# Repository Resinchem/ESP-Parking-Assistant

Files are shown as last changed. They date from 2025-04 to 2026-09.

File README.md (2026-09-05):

# An ESP32 LED Parking Assistant



### Version 0.60 is now out with a complete rebuild!!

Using a low cost ESP32 Mini, a short strip of around 20-40 WS2812b LED pixels and TFMini-s LIDAR distance sensor, you can create an easy-to-build  visual parking assistant system for putting your car in the same location in the garage each time.

Some key features of the system include:
- 4 variable distance parking zones, including a wake zone, an active zone, a parked zone and a backup zone.
- Each zone can have its own unique LED color, specified by the user
- The active zone has 5 different approach effects that can be used to visually show the car approaching the final parked position.
- Automatically goes to standby or sleep mode and only awakens when a car enters the wake zone.
- Supports any number of LED pixels, up to 100, and is designed so the LED strip can be mounted horizontally or vertically.
- All options and settings made through an embedded web interface. No external apps needed.
- Over-the-air firmware updates, with a manual OTA option available for uploading your own modified source code.
- **Optional** Lateral guidance via a secondary sensor.
- **Optional** AP Mode (no-WiFi) allows the system to be used in locations where reliable WiFi may not be available.
- **Optional** MQTT integration so you can use the parking assistant with other automation systems.
- **Optional** 1-Click Home Assistant Discovery.  Add the device to Home Assistant with no YAML or manual configuration!

If you are just looking to install the firmware, just go to the [Installation Page]( https://resinchem.github.io/ESP-Parking-Assistant/installation.html#-install-full-firmware-here) in the firmware guide.  _You do not need to download any files_ from this repo nor do you need to clone the repository.  The installer will handle everything for you!

## Additional Information and Resources

Resource | Details
------|-----
[Build Guide](https://resinchemtech.blogspot.com/2026/08/parking-assistant-2026.html) |A how-to written guide including parts, schematics and overall assembly instructions.
[Firmware Guide](https://resinchem.github.io/ESP-Parking-Assistant/)|Firwmare installer, onboarding and initial system configuration, and overall general application use.

### Video Overviews
YouTube Video | Details
-------|-------
[ESP32 Parking Assistant Overhaul](https://youtu.be/pNj6GjKsijo)|Primarily focuses on v0.60 new features, with brief overviews of operation, parts and assembly processes.
[Parking Assistant Upgrades: Lateral Guidance](https://youtu.be/Eps6QCgKzaM)|Covers new features introduced starting with v0.50.  Primarily focuses on the side sensor addition, wiring and use.
[Original Parking Assistant Video](https://youtu.be/HqqlY4_3kQ8)|Now a bit outdated, as the original version used an ESP8266 and substandard shifter.  But still contains useful background information, including a comparison of distance sensors and why the TFMini-S was selected.

## Special Upgrade Notice
If you are running v0.5x of the firmware, a special one-time migration is **highly recommended**.  This process is described in a special [Migration Page](https://resinchem.github.io/ESP-Parking-Assistant/migration) within the firmware documentation.  

_**DO NOT** attempt to upgrade your firmware using the existing v0.5x web app until you've reviewed the migration page information!_

---

## Information for Older Releases (v0.52 and earlier)
Version 0.60 involved a complete rewrite of the firmware and much of the documentation.  However, if you landed here looking for information for older versions, it has been maintained (for now).

### ESP8266 Support Has Ended (v0.52)

Due to the continued addition (and complexity) of new features, it has unfortunately become necessary to drop support for the ESP8266 beginning with release v0.52.  If you have or wish to use an ESP8266, then you must use firmware v0.51 or earlier.  I've tried to update the wiki and related pages, but if you still see references to the ESP8266 please be aware that this applies to firmware v0.51 or earlier.  Newer features shown in the wiki and discussed elsewhere also may not be available in the older ESP8266 versions.  It is highly recommended to now use an ESP32 for all new builds.

**ADDTIONAL RESOURCES** (ONLY for pre-v0.60 versions!)

Resource | Notes
-----|----
[Firmware Installation and Use](https://github.com/Resinchem/ESP-Parking-Assistant/wiki)|Maintained in this repo's old Wiki (v0.52 and earlier)
[Original Build Guide](https://resinchemtech.blogspot.com/2022/11/esp-parking-assistant.html)|Original written build guide that covers up to v0.52

### Supporting this Project and Future Developement 

### _Always free!_

It takes substantial time, effort and cost to develop and maintain this project and all the related documentation. But my goal is to always provide the code and documentation for free... **without paywalls, subscriptions or implementing some sort of half-assed "freemimum" model.** 

<i>The system will also never collect your data or force any annoying ads down your throat!</i>

If you find this project helpful and would like to say 'thanks', please consider supporting it and future development at:

<a href="https://www.buymeacoffee.com/resinchemtech" target="_blank">Buy Me A Coffee</a>

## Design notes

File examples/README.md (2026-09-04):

## MQTT / Home Assistant Examples

**Starting with release v0.45, Home Assistant Discovery is now available**

MQTT Discover can be launched from within the Parking Assistant web application and it will automatically create a new device and entities in Home Assistant for you, without the need to create any manual YAML or do any other configuration in Home Assistant. Discovery is the **recommended method** of integrating your Parking Assistant.  Please see [Home Assistant Discovery](https://resinchem.github.io/ESP-Parking-Assistant/discoverymain.html) topic for more information.

However, if the discovery process does not work for you or you simply wish to completely control how the entities are created in Home Assistant, you can manually create them via YAML. The basic code for creating these entities is provided in the yaml examples above.  They do not contain additional fields like last-will-and-testament nor any device information. You can tweak these to use your own preferred names, add default icons, or any other valid properties.

Once created, the entities should be available in Home Assistant for use on your dashboards or in your automations.

HA_Entities_Blurred_Small

Note that when first created, these entities may have a state of 'Unknown' until the controller updates its MQTT values based on the telemetry period set in the controller's MQTT options.  You can force an immediate refresh of all topics by any of the following methods:
- Issue an mqtt command to: `cmnd/your_subscribe_topic/refresh` with a payload of "1"
- Use a browser to send the command: `http://[your_ip_address]/api?refresh=1`
- Reboot the Parking Assistant controller.

<i>Creating individual entities as shown in the examples will <b>not</b> create a device like when using Discovery.  To manually add the entities to a common device, you'd need to add the device information to each entity's YAML definition.  See the [Home Assistant MQTT documentation](https://www.home-assistant.io/integrations/mqtt/) for more information on how to add device properties to an entity.</i>

Note that MQTT is optional for the project and it is not required and can be disabled at any time via the web settings.

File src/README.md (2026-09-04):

### If you just want to install the firmware on your ESP32, you do not need to download any files!

Starting with release v0.60, just go to the [Web Installer](https://resinchem.github.io/ESP-Parking-Assistant/installation.html#-install-full-firmware-here) to install the latest firmware release.  All you need is a compatible browser (Chrome, Edge, Brave, Opera, Arc or most other Chromimum-based browsers) and a USB data cable!

## Source Code
This directory contains the source code files for the parking assistant.  You can download and modify this to meet your own needs.  Both the .ino and .h files are reqired. The Parking Assistant supports OTA updates from the Arduino IDE (or other appropriate IDEs).  See the wiki section on [Modifying the Firmware](https://resinchem.github.io/ESP-Parking-Assistant/modifications.html) for more information on OTA updates using an IDE.

You will need to have the ESP32 boards installed in your environment, plus all the appropriate libraries listed at the top of the sketch file.  If you've not setup the Arduino IDE for the ESP before, this video might help: [Arduino IDE: Basics for Non-Coders](https://youtu.be/KS5HOJat88k)

### ESP8266 support has ended
Support for the ESP8266 ended with release v0.52.  If you need to install a version for the ESP8266, you must download and use the _esp8266.bin file for release v0.51 or earlier.  Later versions (v0.52+) are unstable on the ESP8266 due to the overall sketch size and the complexity of new features.

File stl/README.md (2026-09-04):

## 3D Printed Parts
These parts are not required for functionality but simply provided as an option for enclosing or mounting your parts.

All parts were printed using PLA.  Supports (_touching build plate_) are recommended for all parts.  Click any of the files above to see a preview of the model.

Part | Purpose/Notes
----|-----
`Controller Enclosure Easic.stl`|Basic enclosure for the controller.  Deep enough to permit mounting the ESP32 on pin headers.
`Controller Enclosure with Mount Tabs.stl`|Same controller enclosure, but with mount tabs for anchoring to wall or other surface.
`QwiicBus Enclosure.stl`|Enclosure and mount for the Qwiicbus I2C extender (if needed)
`VL53L0X Side Sensor Mount.stl`|Enclosure and mount for the side sensor (if installed)

Alternative, industrious users  improved on my models by designing a different QwiicBus enclosure and even a controller enclosure design that includes the QwiicBus as part of the base controller.  Here is one of these alternate designs:

Credit to _**@pjschaffer**_

[Alternate Controller Enclosure with embedded QwiicBus](https://makerworld.com/en/models/3241403-resinchem-tech-s-parking-assistant-enclosure)

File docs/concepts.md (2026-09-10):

---
layout: default
title: Concepts and Terminology
parent: Welcome
nav_order: 2
has_toc: false
---

# Concepts and Terminology
{: .no_toc }

To successfully install and configure this firmware, it is important to understand the underlying system design and the specific terminology used throughout this documentation.

**🌐 Connectivity & Privacy:**<br>This system is designed to be **fully functional on a local Wi-Fi network**. While it supports integrations like Home Assistant or other systems via MQTT/API, these are strictly **optional**. An active internet connection is not required for core operations.  There is even a mode where the system can operate without WiFi (Access Point mode).
{: .note }

---

## Parking Zones
<p align="center">
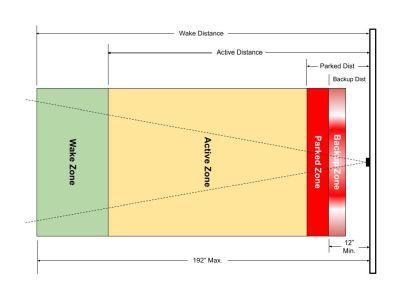
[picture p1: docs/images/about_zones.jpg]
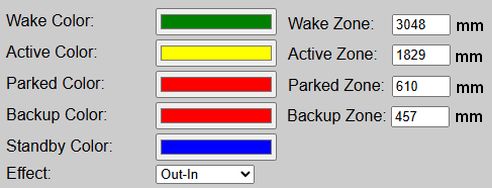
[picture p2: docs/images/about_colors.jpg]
  &emsp;
</p>

To properly configure your system, it is important to understand the different ["zones"](zones) and how they are used.  As a car enters each zone, the LEDs will change color.  What's more, when the car is in the 'Active' zone, an LED effect is used to show the approach to the 'Parked' zone.  Distances, to the outer edge of each zone, can be entered in inches or millimeters.

## The Primary Controller
<p align="center">
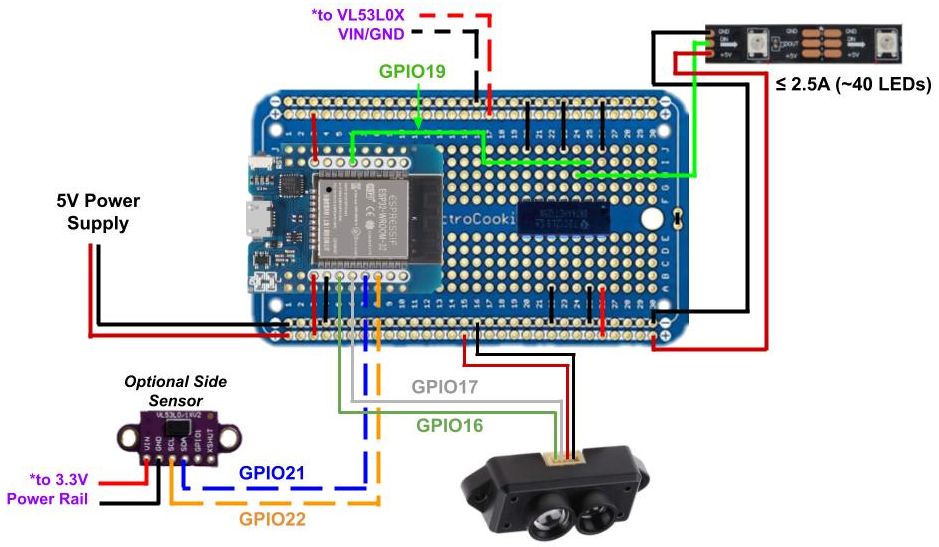
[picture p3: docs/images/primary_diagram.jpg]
  
</p>

The primary controller consists of a standard ESP32 (WROOM-32) and a _recommended_ logic level shifter.  If you've ever built your own WLED controller, the base is nearly identical.  See the [build guide](https://resinchemtech.blogspot.com/2026/08/parking-assistant-2026.html) for complete wiring diagrams and step-by-step assembly instructions.

## LEDs
<p align="center">
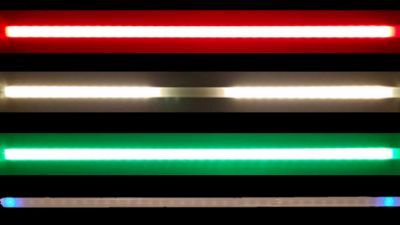
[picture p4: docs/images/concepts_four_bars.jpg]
  
</p>

The system is designed to only work with 5V WS2812b LED strips.  Use of other 5V LED types will require modification of the source code and your own complied version.  Use of 12V or 24V are not supported, as generally these can only control the LEDs in groups of three or six, respectively.  This system needs to control each LED individually, which is normally only found when using 5V addressable LED strips.

The system can theoretically support up to 600 LEDs.  But to minimize the power required (and therefore the wiring), a strip of around 2 feet long is recommended.  This will be around 35 standard LEDs when using a common 60 LEDs/m version.  Alternatively, and to provide greater sensitivity, you can substitute a WS2812b COB LED strip.  Using a version of 160 LEDs/m allows around 100 LEDs in the same 2 foot width, while also drawing about the same amount of current (give or take a bit).

Ideally, you want to keep the current draw of the LEDs to around 2.5A or lower when fully lit at expected brightness.  Exceeding this value will require different power routing (e.g. extra power lines directly to the LEDs). Again, refer to the [build guide](https://resinchemtech.blogspot.com/2026/08/parking-assistant-2026.html) for more information on the LED strips, power supplies and wiring.

## Sensor(s)
<p align="center">
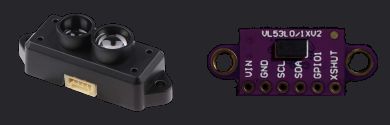
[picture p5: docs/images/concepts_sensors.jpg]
  
</p>

### Primary (Front) Sensor

The primary, or front sensor that tracks the car through the zones, is a TFMini-s LiDAR distance sensor.  The first thing you'll notice about this sensor is its cost... approximately $40!  This is substantially higher than many other distance sensors, like the ultrasonic HC-SR04, that can be purchased for under $5.  

However, in the [original parking video](https://youtu.be/HqqlY4_3kQ8), I compared various sensors at different distances and charted the results.  

<p align="center">
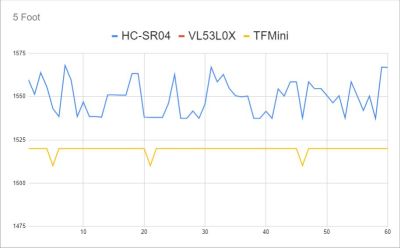
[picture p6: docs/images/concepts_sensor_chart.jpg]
  
</p>

The TFMini-s was the only sensor with the range, precision and signal stability to meet my needs.  Personally, saving $30 isn't much comfort when signal jitter from a noisy subpar sensor causes a bumper to take a $500 bite out of the drywall. 😭

One important note.  Be sure to purchase a TFMini-s (the -s is important).  Other models of the TFMini, such as the _TFMini-plus_ or _TFMini-luna_ use different communication protocols and will not work with the current firmware.

**⚠️ Alternate Sensor Requests:**<br>I've received multiple requests to release a version using a cheaper sensor, like the HC-SR04.  But saving $30 dollars isn't worth the risk of damaging the car or wall by using a less-capable version.  Some have forked the project to substitute a cheaper sensor, but I cannot attest to their functionality nor can I support them.  If you wish to try a different sensor, please understand that you will need to modify the firmware and are on your own for support!
{: .important }

### Optional Secondary (Side) Sensor

While not required, you can add a side sensor to the system to provide both lateral guidance and to improve the front sensor accuracy.  In this case, and because the side sensor needs neither the range nor the precision of the front sensor, it uses a much lower cost VL53L0X sensor.  However, just like the front sensor, the firmware is written for this particular component.  Substitutions will likely require firmware modification.

## Other Important Terminology
There are a few other important terms to understand... at least as far as this guide is concerned.

### Firmware 
This is the compiled code that gets installed on the ESP32 controller.  For this project, the firmware is delivered as a .bin file included in a release's assets.  Note that you cannot directly install the source code (.ino) directly on an ESP board.  It must be compiled into a binary .bin file using the Arduino IDE, PlatformIO or other compiler.  This project includes separate firmware for installing on a new controller or for upgrading an existing controller (v0.60 or greater).

### Web Application:
 The firmware contains an embedded web server and web application. These are primarily used to configure and setup the controller, but can also be used to test or change LED colors, approach effects and distances.

When this documentation refers to the "web app", it does not mean a separate application that has to be installed on a computer, phone or tablet.  You can always access the firmware's "web app" by just going to the IP address of the controller in a web browser of any device on the same WiFi network.  If you opt to run the system in "No WiFi" mode, then the controller will broadcast a local hotspot you can join to access the web application and make system changes.

<div style="display: flex; justify-content: space-between; align-items: center; margin-top: 40px; border-top: 1px solid #333; padding-top: 20px;">
  <a href="{{ '/about' | relative_url }}" class="btn btn-outline"><- Previous: About the Project</a>
  <a href="{{ '/startingmain' | relative_url }}" class="btn btn-purple">Next: Getting Started -></a>
</div>

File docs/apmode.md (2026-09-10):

---
layout: default
title: Access Point Mode (no WiFi)
parent: Setting Up the System
nav_order: 5
---

# Access Point Mode (No WiFi)
{: .no_toc }

---

<p align="center">
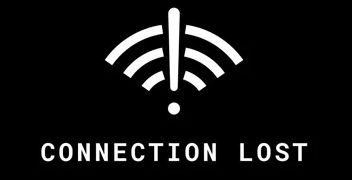
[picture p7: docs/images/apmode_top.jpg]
  
</p>

An oft requested feature, version 0.60 of the firmware introduced the ability to enable local Access Point mode instead of using WiFi.  This is most often needed when installing the Parking Assistant in a location, such as a detached garage or outbuilding, where WiFi may not be available.

Before you can enable this mode (and disable the WiFi features), a few prerequisites must be met:

### <u>System Must First Be Onboarded via WiFi</u>
The onboarding process requires WiFi.  If your planned location does not have WiFi, then simply onboard the ESP32 at a location with WiFi first.  Once onboarded, you can switch to AP Mode via the instructions on this page and then move the controller to the final location.

### <u>MQTT / Home Assistant Discovery Must be Disabled</u>
Since MQTT (and Discovery) require WiFi, you cannot switch the system to AP Mode if Discovery exists or MQTT is enabled.  You must first remove any Discovered devices (if any) and then disable MQTT before you can switch to Access Point mode.

### <u>Other Features Will Also Be Disabled or Limited</u>
Other features that rely on WiFi will also be disabled/unavailable when in AP Mode:
- Firmware Updates:  Firmware updates from within the app use WiFi to transfer the new file.
- Arduino OTA Updates:  This feature requires WiFi/mDNS, so it will also be disabled. 
- HTTP API: Commands can only be sent from devices connected to the AP hotspot.

## Enabling Access Point Mode
Once the above prerequisites have been met, you can toggle AP Mode from the Hardware Settings page.
<p align="center">
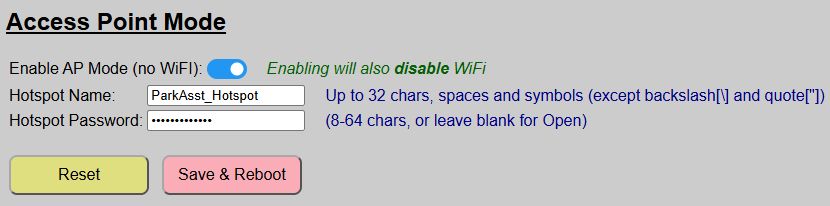
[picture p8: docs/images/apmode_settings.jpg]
  
</p>

Simply toggle the silder to disable WiFi and enable AP Mode.  If you have enabled a feature (like MQTT) that prevents AP mode, you will be shown a message and toggle will move back to "OFF" until you've disabled the other feature(s).

When toggled 'ON', two additional fields are shown:

Setting|Purpose
---|---
HotSpot Name|This is the hotspot that will be broadcast by the system when in AP Mode.  It can be up to 32 characters, numbers or symbols except for the backslash (\\) or quote (") symbols.  It cannot be blank and should not be the same as any other Parking Assistant hotspot name.
Hotspot Password|Enter a password of 8-24 characters in length.  Optionally (but not recommended), you can leave the hotspot 'open', which will not require a password.

>⚠️ **Password Recommended**<br>Leaving a blank password/open hotspot may be more convenient when you need to interact with the system, but anyone else in range of the hotspot can also access the web application and interact with the system.  Even though the range of an ESP32 is rather limited, applying a password is still recommended.
{: .important}

Finally, click the 'Save and Reboot' button.  The system will reboot, but this time, WiFi will not even be started.  Instead, the system will begin broadcasting a local hotspot using the name you specified.  Otherwise, the system will function and operate normally.

## Accessing the Web Application when in AP Mode
So, if the system is not on WiFi, how do you return to the web application to interact with the system or make other changes?  Well, you use a mobile device (tablet or laptop recommended, but a phone will work) and connect to the local hotspot.

In addition, because the radio on the ESP32 isn't very powerful, you'll need to be relatively near the parking assistant to join the hotspot.

_The following instructions and screen shots may be slightly different depending upon the type and operating system of the mobile device in use. Android, iOS and Windows all work just a bit differently, but the steps should be similar._

Using your mobile device, search available WiFi Networks:

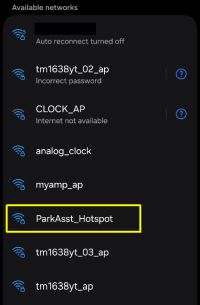
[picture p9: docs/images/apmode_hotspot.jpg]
mobile hotspot


Join this hotspot.  If you entered a password, you will be prompted to provide it.

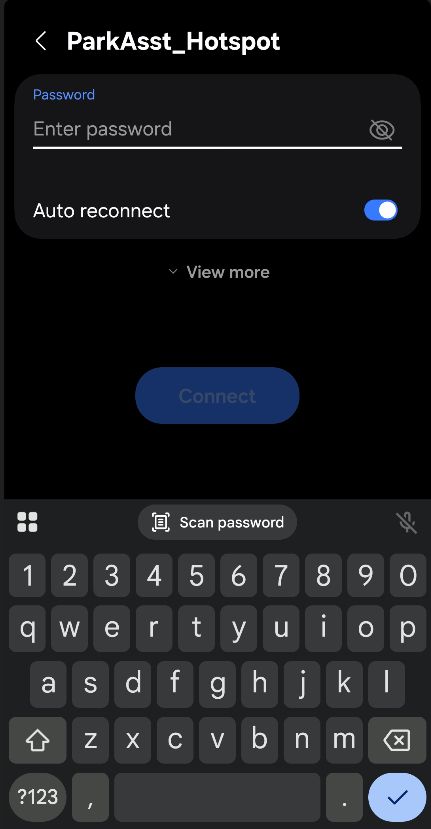
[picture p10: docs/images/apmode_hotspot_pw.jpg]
mobile hotspot


If prompted, elect to  'remain connected' if your device complains about no Internet.  Depending upon your device/OS, the web page may launch automatically. If it doesn't simply open a browser and enter the default IP address of: `192.168.4.1`.  

This should launch the main page of the web application. 

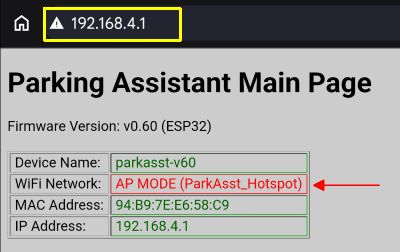
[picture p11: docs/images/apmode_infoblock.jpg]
info block


Note that the info block at the top of the page now indicates AP MODE for the Wifi Network and includes the hotspot name in parentheses.  Once on the main page, you can interact with the system, even changing and saving hardware settings, just like the system was on normal WiFi.  The only exception will be those previously mentioned features, like firmware updates or enabling MQTT, which are only available in normal WiFi mode.

When done interacting, simply rejoin your device to normal WiFi again.  Nothing needs to be done on the parking assistant side and it will continue broadcasting the hotspot for the next time you need to interact with the system.

## Returning to Normal WiFi Mode
If your system is in Access Point mode and you wish to return to normal WiFi mode, the process is even easier!

Access the web app with a mobile device and the hotspot as described above.  Go to the Hardware settings page and simply toggle the AP Mode switch back to the off position.

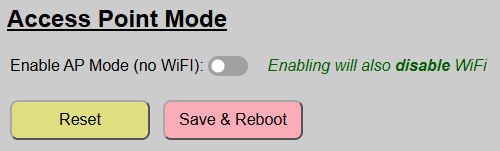
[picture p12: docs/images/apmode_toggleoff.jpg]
toggle switch


Now just 'Save and Reboot'.  The previously used WiFi credentials (SSID and password) used during initial onboarding will be recalled and the system will rejoin normal WiFi when it reboots.  Easy, peasy!  This means you can switch back and forth between normal and AP modes as needed.

## Applying Firmware Updates
One of the features that is disabled when the system is in AP Mode is the ability to update the firmware from the web application.  So how do you handle this situation if you have a system without WiFi and a firmware update is released?  You have a couple of options available.

### Option 1: Return the System to WiFi Mode (recommended method)
First place the system back in normal WiFi mode.  If Wifi is not available in the installed location, then you'll need to temporarily move the controller to a WiFi-enabled spot.  If you built your system according to the [Build Guide](https://resinchemtech.blogspot.com/2026/08/parking-assistant-2026.html) and your ESP32 is mounted on pin headers, you can simply power down the system and remove the ESP32.  Take the ESP32 to a WiFi-available location.

Power the removed ESP32 via its USB port.  Since there are no LEDs or sensors attached, pretty much any USB power source... a cell phone charger or an available USB port on a computer will work.  And since we are just using USB for power in this case (and not data), you do not even need a data cable in this case.

Once the ESP32 is back on WiFi and powered, return to the web application. Note that this may be a different IP address than previously assigned if you did not assign a static/reserved IP address when you onboarded the system.  If you cannot reach the web application, check your router to see if a different IP was assigned.

### Option 2: Update via AP Mode
Alternatively, you can download and transfer the firmware update file (`ParkingAsst_vX.XX_Update.bin`) to your mobile device (laptop strongly recommended), join the hotspot and open up the web application.  This method is not the recommended process for a couple of reasons:
- Depending upon your device, it may not be possible to select the transferred update.bin file from the file browser provided on the update page.
- Hotspot mode simply isn't as robust and reliable as normal WiFi mode.  You may have issues with a successful flash if the file transfer process is interrupted.

But you can always try this method and fall back to the WiFi method if it fails.

Regardless of the method used to access the web page, just use the Firmware Update controller command to flash the update file.  See the [Installing Firmware Updates](firmwareupdates) topic for step-by-step instructions upgrading the firmware.

If you used Method 1, simply set the system back to AP Mode after the update and then reinstall the ESP32 back into the controller assembly.  When it reboots, it will return to AP mode.

<div style="display: flex; justify-content: space-between; align-items: center; margin-top: 40px; border-top: 1px solid #333; padding-top: 20px;">
  <a href="{{ '/sensorcalibrate' | relative_url }}" class="btn btn-outline"><- Previous: Sensor Calibration</a>
  <a href="{{ '/usingmain' | relative_url }}" class="btn btn-purple">Next: Using the System -></a>
</div>

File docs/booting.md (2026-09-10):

---
layout: default
title: The Boot Process
parent: Getting Started
nav_order: 3
has_toc: false
---

# The Boot Process
{: .no_toc }

---

<p align="center">
  The Boot Process Header
</p>

A lot is going on in the background when a controller first boots up... connecting to WiFi, configuring the hardware, starting up the web server and API routines and connecting to an MQTT broker (if enabled).  The system can provide some basic visual indicators of this boot process and can help you determine where a problem may exist if the controller isn't functioning as intended.

>⚠️**Enable Indicators During Setup**<br>It is highly recommended that you leave the boot indicators enabled at least during initial system configuration and setup and until you are sure all hardware and any optional integrations are working properly.  If your system has an issue during the setup/boot process and these indicators are disabled, it may be difficult to determine where and why the failure is occurring.
{: .important}

## Visual Boot Indicators

When you power on the controller, the following steps occur:
* The system looks for a configuration file in its own storage (SPIFFS) partition. If not found, it enters 'Onboarding mode' and starts the WiFi Hotspot.  Setup halts at this point.
* The system attempts to connect to WiFi.  Again, if it fails, it enters Onboarding mode and further setup halts.
* The configuration file is opened and your particular system settings are loaded.
* Hardware and sensor(s) are configured and initialized.
* OTA Mode is enabled.
* When boot is complete, the system enters normal running mode.
<br><br>

_Note_:  You can disable some of these boot indicators via the web app if you don't want to see them.  The process described below assumes these indicators are enabled.
Boot Options

### WiFi Connected

Most ESP32 board have a power LED that will illuminate as soon as power is received.

power led

But most boards also have a second onboard LED (usually blue) that can be controlled via a GPIO pin (GPIO2).  If your board has one (and the option is enabled), this second LED lights up to let you know the controller is officially talking to your network and not just glowing in the dark!

wifi led

This option can be disabled if your board does not have a second LED.  Or if your board uses a different GPIO pin for the onboard LED, you can also change that via the system's hardware settings.

>📵 **Access Point (No WiFi) Mode**<br>If your system is configured for Access Point mode, then the blue LED will never illuminate after initial onboarding, regardless of indicator setting.
{: .note}

### MQTT Broker Connection
If you have enabled MQTT under integrations, the LED strip will show each broker connection attempt.  The system will make up to 10 tries before failing.  Each attempt is shown on the LED strip as it occurs:

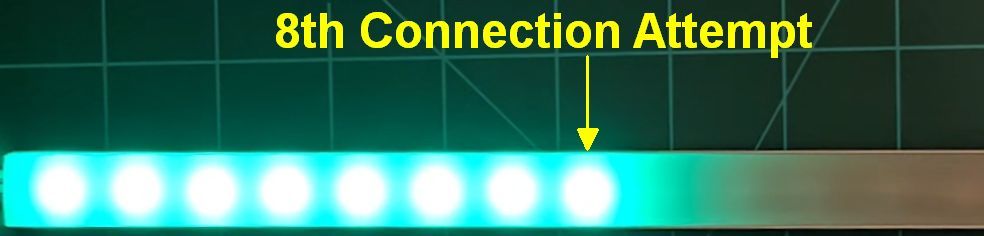
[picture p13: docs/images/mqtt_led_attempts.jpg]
LED Strip


**Each attempt may take 3-5 seconds**.  If unsuccessful after 10 tries, the full LED strip will briefly flash yellow and MQTT will be disabled.  The normal boot process then continues.  This entire process may take up to 60 seconds to complete before failing. The web page will be inaccessible during this period, as it is not available until the entire boot operation completes.

<i>When a normal successful connection is made, it may happen so quickly you may only see one or two LEDs briefly flash in green... or may not see the green LEDs at all.  This normal behavior.</i>

### Side Sensor Initialization
If you have enabled and configured a side sensor (lateral guidance), the boot process will initialize the communication with the sensor.  If this initialization **FAILS**, then the LED strip briefly flashes orange. 

boot_orange

If the side sensor successfully initializes (or if it is disabled), then you will not see this brief orange color.

### LEDs and Other Hardware
If all other hardware and boot processes complete, and if enabled, the LEDs will then briefly flash red, green and blue.

led_test

Once you see this sequence, all hardware and other communication protocols have been initialized and started.  There is just one more step before the system begins normal operation.

### OTA (Over-the-Air) Updates Enabled

Finally, if all other checks complete, the boot process enables over-the-air mode for receiving firmware or other updates wirelessly.

ota leds

When OTA mode is implemented, the LEDs change to alternating red and green.  During the boot process, this is only shown for a few seconds and _does not indicate that the system is receiving data_.  During the boot, it only indicates that OTA is now active and available.  Note that this indicator will always be shown, even if the LED Boot Indicator option is disabled in the hardware settings.

**NOTE**: OTA requires WiFi, so if you are operating in Access Point (no WiFi) mode, the OTA will not be enabled and the LEDs will not show this mode.

After this final step, the system enters normal operating mode.

>👉**System Always Starts in "Active" Mode after Rebooting**<br>By design, any time the system boots, it will start out in 'active' mode.  If a car is present, the LEDs will light up appropriately based on position.  Just for the boot process, the LEDs will remain on for the "Exit Time" and then enter 'Standby' mode.  If no object is in any zone, then the system will enter standby immediately after the boot finishes.
{: .note}

>⚠️**Additional Startup Processes**<br>If you have MQTT enabled, there may be up to a 30 second delay as initial MQTT topics are published before the system will respond to sensor triggers. If the system doesn't respond immediately after booting, give it 30-60 seconds to complete all start up processes.
{: .important}

<div style="display: flex; justify-content: space-between; align-items: center; margin-top: 40px; border-top: 1px solid #333; padding-top: 20px;">
  <a href="{{ '/onboarding' | relative_url }}" class="btn btn-outline"><- Previous: Onboarding</a>
  <a href="{{ '/setupmain' | relative_url }}" class="btn btn-purple">Next: Initial System Setup -></a>
</div>

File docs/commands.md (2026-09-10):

---
layout: default
title: Controller Commands
parent: General System Use
nav_order: 4
has_toc: false
---

# Controller Commands
{: .no_toc }

---

<p align="center">
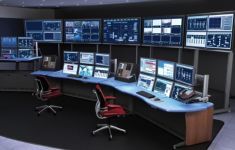
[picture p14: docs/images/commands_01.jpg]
Zone Image
  
</p>
The main page of the web application offers a set of standard controller commands that can perform operations such as rebooting the controller, applying firmware updates, viewing the contents of your saved configuration file or even factory resetting the controller for a new onboarding process.<br><br>

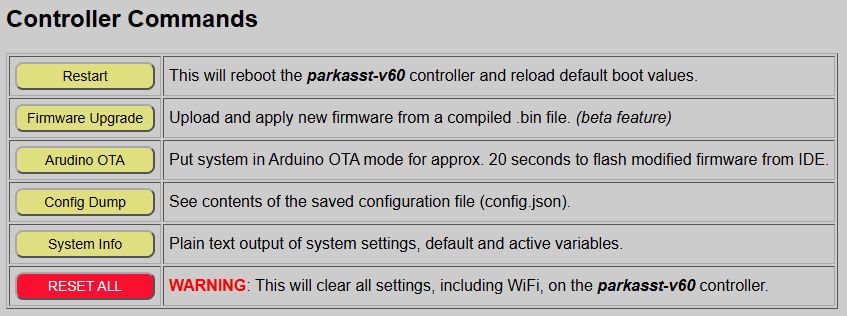
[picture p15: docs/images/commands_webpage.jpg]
Zone Image


### Restart

 Reboots the controller. If you have applied any "Active" settings that have not been saved as new defaults, these settings will be overwritten with the last saved defaults during the reboot.

### Firmware Upgrade

_**This feature is not available when operating in AP Mode!**_
{: .label .label-yellow }

This opens up a page for applying firmware updates from a compiled `_Update.bin` file, normally from the repository's [Releases](https://github.com/Resinchem/ESP-Parking-Assistant/releases/latest) page.  You cannot upgrade using the source (.ino) files, but only with a compiled .bin file.

> **⚠️ Warning**<br>Installing the wrong firmware file on the controller will break your system. See [Installing Updates]({{ '/firmwareupdates' | relative_url }}) before proceeding.
{: .warning }

Installing firmware updates are covered in a separate upcoming topic or you can use the link in the box above to jump directly there now.

### Arduino OTA
_**This feature is not available when operating in AP Mode!**_
{: .label .label-yellow }

This can be used to place the system in a special programming mode, where a modified source code version of the firmware is compiled and installed wirelessly to the controller.  Each controller broadcasts a special message that is used as a "port" in the Arduino IDE.

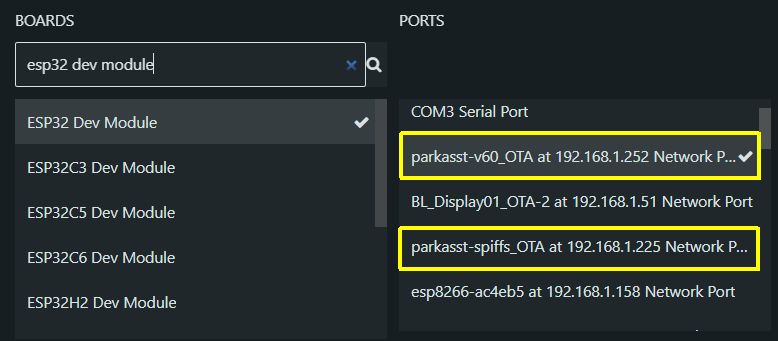
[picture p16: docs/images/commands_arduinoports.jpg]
Arduino Ports


The port will show the device name followed by _OTA and the IP address of the controller.  Make sure when using this method that you are flashing the correct code to the correct controller.  As you can see in the above example, I have two Parking Assistants active on the network.  I can differentiate them not only by the IP address, but also by the device name I assigned during onboarding.

> **🌐 Port Not Found**<br>The Arduino OTA process requires that your network support and allow mDNS broadcasts.  This is an **Arduino requirement** and not a firmware issue.  If you cannot (or prefer not to) allow mDNS broadcasts, then any Arduino updates cannot be done wirelessly and you will need to use a USB cable connection for uploads.
{: .note }

Once your new code is verified and ready for upload, click the 'Arduino OTA' button.  When activated, the LEDs will display an alternating Red-Green pattern

ota_mode

- As soon as the system is put into OTA mode, begin the upload from the Arduino IDE.
- If no code is received within about 20 seconds, the controller exits OTA mode and returns to normal operation.
- When in OTA mode, all other functions of the system are paused.  This includes:
  - No sensor triggers will be recognized.
  - No outbound MQTT updates are published (if enabled)
  - No external commands are recognized or processed

If the Arduino upload is successful, the controller will automatically reboot and begin executing your modified firmware.

Note that the Arduino OTA update is generally used when making your own modifications to the firmware.  If you are just looking to install an update or upgrade from the repository, it is recommended that you use the provided Firmware Upgrade feature described above.  See the topic [Modifying the Firmware](modifications) for more information on making your own changes to the firmware.

### Config Dump

You can use the config dump feature to get a JSON output of the contents of your saved configuration file.

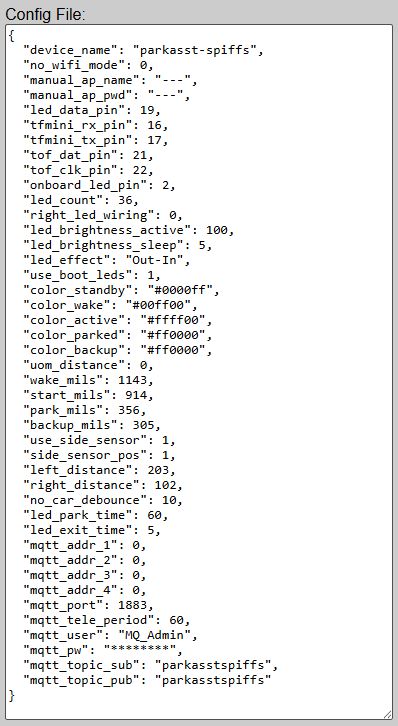
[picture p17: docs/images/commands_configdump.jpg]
Config Dump

<br>
<i>Example configuration file. Fields will differ based on settings/options selected</i>
<br><br>
This can be handy for troubleshooting and you may also be asked for the contents of this file if you open an issue related to the firmware in the Github repository.  You can simply copy/paste the prettified JSON output from the web page to the Github issue (or Discussions).
<br><br>
👉<i> Note that distances are always stored in millimeters in the configuration file, regardless of units selected.</i>
<br><br>
> **👁️ Home Assistant Discovery Config**<br>If you have enabled Home Assistant Discovery, the config dump from the primary controller will also include a second configuration file for the Discovery process.  If Discovery is not enabled, this just includes a message to that effect.  See the [Home Assistant Discovery](discoverymain)  topic for more information.
{: .note }

### System Info

The system info is a plain text version of your system's settings.

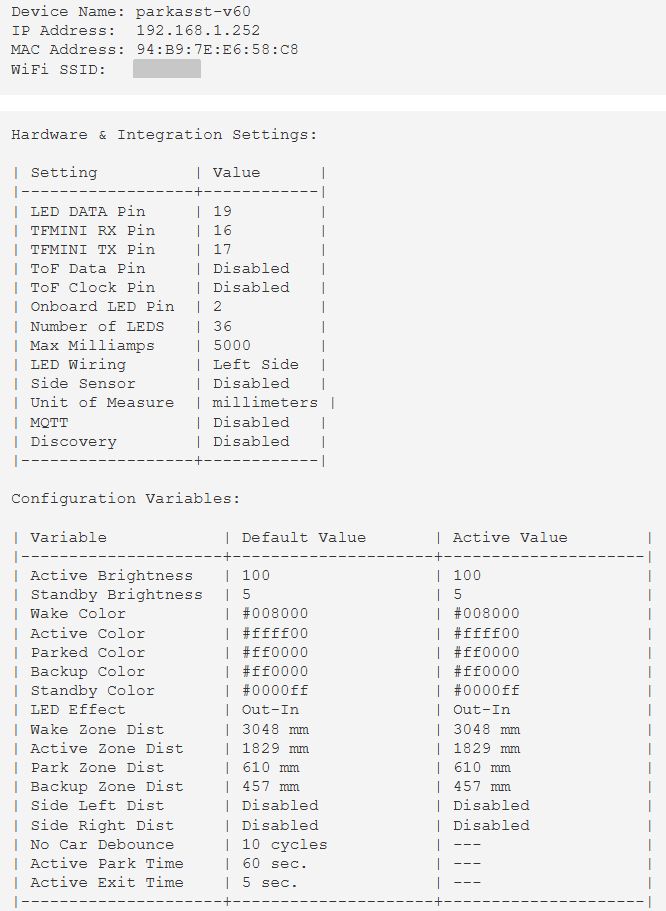
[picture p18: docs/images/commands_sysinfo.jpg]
Sys Info


This contains much of the same information as the Config Dump, but in addition to saved default values, it also shows the current system's ACTIVE values.  It also shows some additional system information.  This can also be a handy troubleshooting tool if the system isn't behaving as expected.

### Reset All

This performs a "factory reset" on the controller, wiping out all saved configuration data. This is normally used if you need to make a change to the WiFi or the global Device Name, as changing either of these items **requires** a full reset.

> **❗ HIGH RISK**<br>This command wipes **ALL** configuration data from the controller, including saved Wi-Fi credentials. Use this only if you intend to return the controller to its original installation state. You will have to repeat the [Onboarding]({{ '/onboarding' | relative_url }}) and [System Setup]({{ '/setupmain' | relative_url }}) processes.
{: .warning }

**_If using AP Mode, you will need to move the controller to a WiFi area for the onboarding step after resetting!_**
{: .label .label-yellow }

### External Control
Some of these commands can also be sent via MQTT or via the HTTP API.  See [Using MQTT and the API]({{ '/integrationmain' | relative_url }}) for a list of applicable commands.

## Next Steps
This completes the normal setup and operation of the system.  The remaining sections of the guide cover optional features like MQTT and Home Assistant integration, upgrading or modifying the firmware, advanced technical information and a troubleshooting section.

<div style="display: flex; justify-content: space-between; align-items: center; margin-top: 40px; border-top: 1px solid #333; padding-top: 20px;">
  <a href="{{ '/sensoroverride' | relative_url }}" class="btn btn-outline"><- Previous: Overriding the Sensors</a>
  <a href="{{ '/integrationmain' | relative_url }}" class="btn btn-purple">Next: Optional Integrations -></a>
</div>

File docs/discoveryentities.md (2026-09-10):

---
layout: default
title: Updating or Hiding Discovered Entities
parent: Home Assistant Discovery
nav_order: 2
---

# Updating or Hiding Discovered Entities
{: .no_toc }

---

<p align="center">
  [Top banner image]
</p>

One of the most powerful features of the Discovery system is the ability to choose exactly which components of the system are exposed to Home Assistant. You can add or remove groups of entities at any time to keep your dashboard clean and relevant.

---

## Updating an Existing Discovery
The primary controller stores your previous settings in a `discovery.json` file. This allows you to modify your entity list without creating duplicates in Home Assistant.

### Modifying Entity Groups
1. Navigate to the **Discovery** page in the **Integrations** menu.
2. Your previously selected groups will be pre-populated.
3. Check any additional groups you wish to add, or uncheck groups you wish to remove.
4. Click the **UPDATE DISCOVERY** button.

> **💡 Device Name Limitation**<br>The **Device Name** is used to generate unique MQTT discovery topics. Because of this, you cannot change the Device Name once Discovery is enabled. To change the name, you must first [Remove Discovery]({{ '/discoverymanage' | relative_url }}) and then recreate it with the new name.
{: .note }

### The Update Button
When you click **UPDATE DISCOVERY**, the system immediately sends "clearance" messages for any removed groups and "discovery" messages for any new ones. 

> **⚠️ Dashboard Warning**<br>If you remove an entity group that is currently in use on a Home Assistant dashboard or in an automation, those items will show as "Unavailable" or may break entirely.
{: .warning }

---

## Handling Hardware Changes and Firmware Upgrades
Because Discovery relies on a unique string (Device Name + MAC Address), certain hardware events require attention:

* **System Reset (Same ESP32):** If you perform a factory reset but use the same hardware and the same Device Name, running Discovery again will simply "take over" the existing entities in Home Assistant.
* **New ESP32 / Different Name:** If you replace the controller or change the name, Home Assistant will treat it as a brand-new device. In this case, it is best to delete the old device from the Home Assistant **Devices** page to avoid clutter.
* **Firmware Updates:** Some firmware updates may introduce new features like LED effects that might require an update to Discovery.  If needed, this will be noted in the release notes for the updated version.

If you make any hardware changes to your system after Discovery is enabled (e.g. enable/disable a side sensor, changing the number of LEDs, etc.), you will need to update or remove/reenable your Discovery to reflect these changes.  

* If you are making permanent hardware changes, then the recommendation is to completely remove and then reenable Discovery.  This assures the correct type of entities and properties are created for the hardware changes.

* If you just want to change the exposed entities, you just make your selected changes and update the Discovery. A complete removal and reenable of Discovery isn't needed just to change exposed entities.

## Entities Created Reference Table
The following table lists the entities created in Home Assistant based on your selections. Note that settings, such as the number or type of sensors used, will also impact the entities created.  

*Note: `device_name` refers to your specified Discovery Device Name (converted to lowercase with underscores).*

 Entity Group | Entities Created | Friendly Name 
 :--- | :--- | :--- 
**Controls**|`light.device_name_led_strip`<br>*(Includes brightness &amp; color attributes)*<br>`switch.device_name_sensor_override`|LED Strip<br><br>Sensor Override
**Sensors**|`binary_sensor.device_name_car_presence`<br>`sensor.device_name_front_distance`<br>`sensor.device_name_side_distance`<br>`sensor.device_name_zone`|Car Presence<br>Front Distance<br>Side Distance<br>Zone
**Configuration**|`number.device_name_brightness_standby`<br>`text.device_name_color1_wake`<br>`text.device_name_color2_active`<br>`text.device_name_color3_parked`<br>`text.device_name_color4_backup`<br>`text.device_name_color5_standby`<br>`select.device_name_led_effect`<br>`number.device_name_dist1_wake`<br>`number.device_name_dist2_active`<br>`number.device_name_dist3_park`<br>`number.device_name_dist4_backup`<br>`number.device_name_side_dist_left`<br>`number.device_name_side_dist_left`|Brightness Standby<br>Color1 Wake<br>Color2 Active<br>Color3 Parked<br>Color4 Backup<br>Color5 Standby<br>LED Effect<br>Dist1 Wake<br>Dist2 Active<br>Dist3 Park<br>Dist4 Backup<br>Side Dist Left<br>Side Dist Right
**Diagnostics**|`button.device_name_controller_restart`<br>`sensor.device_name_ip_address`<br>`sensor.device_name_mac_address`|Controller Restart<br>IP Address<br>MAC Address

### Additional Notes
* If your system is configured without a side sensor, then all side sensor-related entities will be omitted and will not be created.
* To control the LEDs manually via the Light entity or via automations, then assure you first enable the `Sensor Override` switch.  See more information on manually controlling the system under the [MQTT](mqtt) and [API](api) topics.  Toggle this setting back off to reenable normal system operation.

> **💡 Customization**<br>You can safely rename these entities or change their icons directly within the Home Assistant UI without affecting the controller's firmware.  But note that future Discovery updates may overwrite your changes or create duplicate entities.
{: .note }

<div style="display: flex; justify-content: space-between; align-items: center; margin-top: 40px; border-top: 1px solid #333; padding-top: 20px;">
  <a href="{{ '/discoverymanage' | relative_url }}" class="btn btn-outline"><- Previous: Enabling and Disabling Discovery</a>
  <a href="{{ '/discoverymanual' | relative_url }}" class="btn btn-purple">Next: Manually Creating MQTT Entities -></a>
</div>

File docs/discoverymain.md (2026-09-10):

---
layout: default
title: Home Assistant Discovery
nav_order: 6
has_children: true
has_toc: false
---

# Home Assistant Discovery
{: .no_toc }

---

<p align="center">
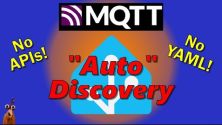
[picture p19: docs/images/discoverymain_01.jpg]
Home Assistant Discovery Overview
  
</p>

If you are a Home Assistant user, you can integrate your LED controller to use its features directly from your dashboards or utilize them in complex automations and scripts. The system offers over 20 distinct entities—including a light, sensor states and settings, and other miscellaneous values without requiring any manual YAML configuration on the Home Assistant side.  And you have control over which entity groups are included and which are omitted!
<p align="center">
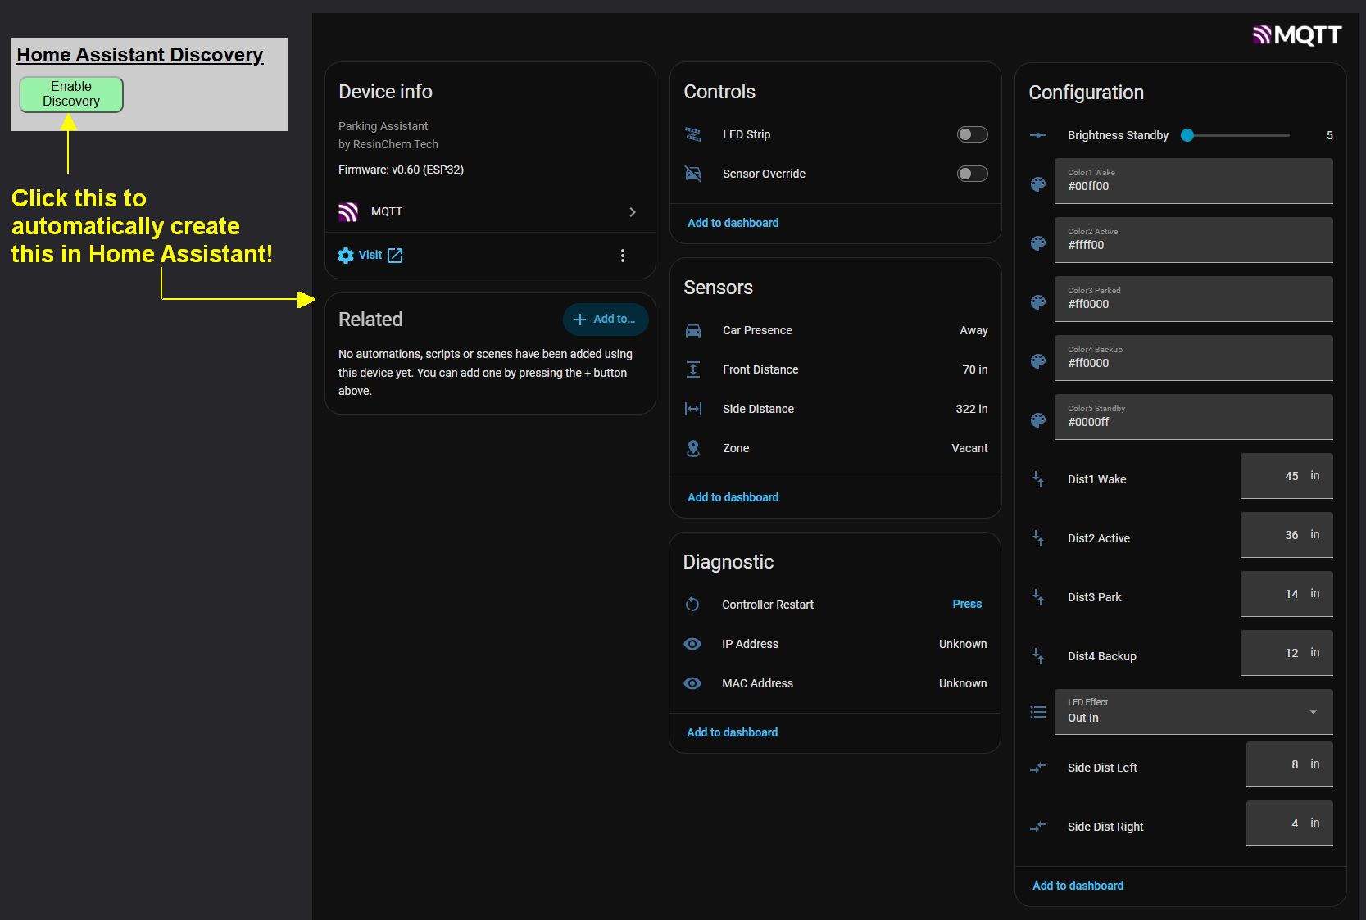
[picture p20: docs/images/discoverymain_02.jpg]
Home Assistant Discovery Overview
  
</p>

## Prerequisites
**MQTT is not available in [AP Mode] - WiFi is required**
{: .label .label-yellow }

Before attempting to enable Discovery, ensure your environment meets the following requirements:

1. **Home Assistant:** Version 2026.3 or later is recommended.
2. **MQTT Broker:** A properly configured broker must be available on your network (e.g., the official Home Assistant Mosquitto add-on or a standalone broker).
3. **MQTT Enabled:** You must have successfully [Enabled and Configured MQTT]({{ '/mqtt' | relative_url }}) in the Parking Assistant’s Integration settings and verified the connection.

---

## Understanding Discovery Naming
The Discovery process creates a new "Device" in Home Assistant using the **Discovery Device Name** you specify. This name is critical because it determines how your entities appear in the Home Assistant database.

### Entity ID Generation
All created entity names are prepended with the device name. The system automatically converts the name to lowercase and replaces spaces with underscores.

**Example: Device Name "ParkAsst 1"**
* `light.parkasst_1_led_strip`
* `sensor.parkasst_1_parkdistance`
* `text.parkasst_1_effect`

> **💡 Note**<br>Once Discovery is enabled, the **device name** cannot be changed without first removing the Discovery and re-adding it. Consider your naming choice carefully to avoid breaking future dashboards or automations.
{: .note }

---

## How Discovered Entities Work In Home Assistant
When the LED strip is created in Home Assistant, it is created as a "Light" entity.  As a light entity, it has its own color and effect attributes.

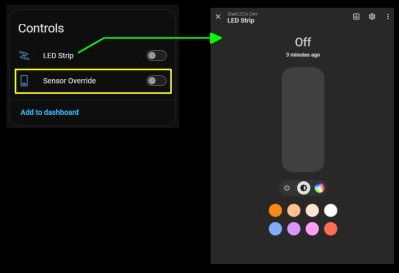
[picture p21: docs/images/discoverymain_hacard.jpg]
ha_card


Note that these are separate and independent from any effect and colors set for the zones.  This means that the LED strip light attributes are only used when manually controlling the LED strip.  However, to manually control the strip and not have any changes immediately reset by the sensor settings, the sensors must be disabled or overridden.

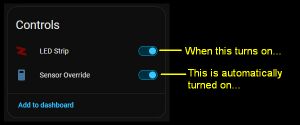
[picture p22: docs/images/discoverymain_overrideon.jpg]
override_on


Since manually controlling the LED strip requires that the sensor override be ON, the system will set this automatically any time you perform an action that causes the LED to turn on.  This is true whether using the Light Card or an automation.  

<i><b>Note:</b></i> While turning on the light via the entity also automatically enables the override, you can also manually enable the override without actually turning on the LEDs.  This can be done if you simply wish to override the sensors and not have the system react to triggers.

So while the override gets automatically set when manually turning on the LEDs, the <b>opposite is not true!</b>

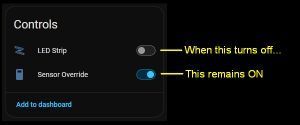
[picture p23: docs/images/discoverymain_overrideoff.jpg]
override_off


This is intentional because you may wish to maintain manual control of the LEDs even after they are toggled off.  However, you must remember to disable the sensor override to return the system to automatic operation where it again responds to sensor triggers.

### Automation Recommendations
If controlling the LEDs via automations or scripts, it is recommended that you explicitly disable and re-enable the sensor override.

<i>Using the UI editor:</i><br><br>
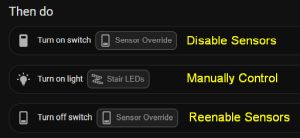
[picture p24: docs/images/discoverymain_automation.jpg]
ha_automation


<i>Using YAML:</i>
```yaml
actions:
  - action: switch.turn_on
    target:
      entity_id: switch.parkasst_sensor_override
  - action: light.turn_on
    target:
      entity_id: light.parkasst_led_strip
  - action: switch.turn_off
    target:
      entity_id: switch.parkasst_sensor_override

```

Since turning on the LED strip also automatically enables the sensor override, the first action is technically unnecessary.  But it is recommended since enabling the sensor override also clears any active sensor triggers and sets the LEDs to an off state.

The last action, reenabling the sensors, also does not need to appear in the same automation's actions if you wish to leave the LEDs in a manual state after the automation completes.  Just remember to disable the override to return the system to automatic operation.

> **🚩 System not responding?**<br>As covered under [Troubleshooting](troubleshooting), if you have your controller integrated with an external system and the LEDs no longer seem to respond to the sensors, check that the Sensor Override setting has not been left on.
{: .important }

## In This Section

* **[Enabling and Disabling Discovery]({{ '/discoverymanage' | relative_url }})** – Step-by-step instructions for the initial setup and removal of the HA integration.
* **[Editing or Hiding Discovered Entities]({{ '/discoveryentities' | relative_url }})** – Managing entity groups and a complete reference table of all discovered entities.
* **[Manually Creating MQTT Entities]({{ '/discoverymanual' | relative_url }})** – Advanced instructions for users who prefer manual YAML configuration.

---

<div style="display: flex; justify-content: space-between; align-items: center; margin-top: 40px; border-top: 1px solid #333; padding-top: 20px;">
  <a href="{{ '/api' | relative_url }}" class="btn btn-outline"><- Previous: API HTTP Command List</a>
  <a href="{{ '/discoverymanage' | relative_url }}" class="btn btn-purple">Next: Enabling and Disabling Discovery -></a>
</div>

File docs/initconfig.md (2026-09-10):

---
layout: default
title: Hardware Configuration
parent: Setting Up the System
nav_order: 2
---

# Hardware Configuration
{: .no_toc }

---

<p align="center">
  Web App Header
</p>

After initial onboarding, you may find that the system doesn't operate or isn't behaving as intended.  This is due to default hardware values that are used for the installation.  To make the system fully functional, you **must** configure your particular hardware.

>👉 **GPIO Pins**<br>The system allows you to use different GPIO pins for your devices other than the defaults provided with the firmware.  But note that you cannot use GPIO 0 for any of your settings.  While GPIO 0 is a valid GPIO pin on most ESP32s, within the context of this application, using "0" as a GPIO pin means that device is not used.  Do not set any GPIO pins to "0" unless you truly are not using that device/connection.  Use of strapping pins is also discouraged, but not enforced by the application.
{: .note }

Begin by opening the integrated web app by just going to the IP address of the controller in a web browser of any machine on the same network.

Near the top of the main page, you will see a System Configuration section with a Hardware Settings button:<br><br>
Option Block<br><br>
Info Section

The top of the hardware settings page shows the current version number, a navigation button back to the main page and a few reminders.  Various settings are listed underneath. I'll show and describe each section separately, starting from the top.

> **⚠️ IMPORTANT**<br>Changes made on this page are not committed and applied until you click the 'Save and Reboot' button at the bottom of the page.  If you make changes and then navigate to a different page before saving, all changes will be lost!
{: .important } 

## System Indicators

System Indicators

These were covered under the [Boot Process](booting) section, but these enable or disable the use of the LEDs to indicate boot progress and success.  

For all settings, the system default value after initial flashing is shown.

Setting|Default|Purpose
---|:---:|---
ESP32 Onboard LED|ON|Shows successful WiFi connection. Will remain off if operating in Access Point Mode (no WiFi).  Otherwise remains on after connection is made.
Onboard GPIO Pin|2|For most ESP32 boards, the onboard LED is controlled by GPIO2.  Only change this if your board is different.  Ignored if prior setting is disabled.
LED Boot Test|ON|Briefly flashes the LEDs red, green and blue at the end of the boot sequence to indicate a successful boot.

I generally recommend that you leave these options enabled.  The only exception might be the ESP32 Onboard LED.  Once you've established that WiFi regularly connects, you may wish to toggle this off just as the blue LED can be quite bright.

## LED Strip Configuration
LED strip Options

This is where you configure your LED strip.  Initially, you may notice that not all LEDs light up, or effects aren't rendered properly.  This is likely because the initial default value for the total number of LEDs (30) is different than the actual number of LEDs in your strip.

Setting|Default|Purpose
---|:---:|---
Number of LEDs|30|The total number of LEDs in your strip.
Wired On|Left|Indicates where your LED data signal wire is connected to the left or right of the LED strip. This impacts how effects are rendered. See below for additional information
Data GPIO Pin|19|The ESP32's GPIO pin used to send the LED data.  Only change if you wired your controller differently.
Max Amp Draw|5|You should set this to approximately 80% or less of your power supply's peak max amp rating.  See below for discussion on this topic.

### <u>Left/Right Wiring</u>
<br>
To properly render the approach zone effect and to correctly flash the proper end of the LEDs when a side sensor/lateral guidance is enabled, the system needs to know whether the LED data line is connected to the left or right side of the LED strip.

LED Wiring

If your strip is mounted vertically, select 'Left' for bottom wiring and 'Right' for top wiring.  If the approach zone effect seems to be working in reverse from what is expected, double-check this setting.

### <u>Max Amp Draw</u>
<br>
LEDs can draw a lot of current!  As an extra safety precaution, this setting attempts to limit the amount of amps that the LEDs will use.  It does this by limiting the overall brightness of the LEDs.

It is recommended that you set this value to no more than approximately 80% of the peak max rating of your power source.  For example, if using a 3A power supply, set this value to around 2.4 amps.  

> **⚠️ DON'T OVERTAX YOUR SYSTEM!**<br>Setting a current limit prevents your LEDs from attempting to pull 1.21 gigawatts through a 28-gauge breadboard jumper! You're building a garage parking assistant, not a flux capacitor—cap the current draw at ~80% of your power supply's peak rating.
{: .important}

If you find that the limiter is making the LEDs too dim, even at the highest brightness, it is an indication that your power supply is too small.  See information in the [Build Guide](https://resinchemtech.blogspot.com/2026/08/parking-assistant-2026.html) for more information on selecting the proper power supply size (and special wiring that is required for high current draw systems).

## Sensor Configuration
This is where you configure the front sensor, and optionally enable and configure a side sensor for lateral guidance.

Sensor Config

Setting|Default|Purpose
---|:---:|---
System Units|mm|Sets whether the system uses inches or millimeters for configuring zone distances.  If MQTT is enabled, also sets the distances reported from the sensors to inches or millimeters.  If you already have distances defined and change this setting, current values are converted for you.
Calibration Mode|--|Opens a separate page for obtaining raw readings from the sensor(s). See the following section on [Sensor Calibration](sensorcalibrate) for additional information.

### Front Sensor

Setting|Default|Purpose
---|:---:|---
RX Pin|16|The GPIO pin connected to the TFMini's receive or RX pin.
TX Pin|17|The GPIO pin connected to the TFMini's transmit or TX pin.
No Car Debounce|10|Number of cycles that a trigger must continue to activate the system.  See the discussion below.
Active Park Time|60|Time in seconds, that the system remains active once the vehicle enters a zone and before the system returns to standby/sleep mode.
Active Exit Time|5|Time in seconds that the system remains active once triggered and when no objects are detected in any zone.  See discussion below.

<b><u>No Car Debounce</u></b><br>
The system samples the sensor distance thousands of times a second.  Occasionally, interference my cause the sensor to very briefly report a random distance.  If this distance is within one of the zone distances, this could activate the system.  To accommodate these momentary signals, a debounce setting is used to say that the distance must be within a trigger distance for so many "cycles".  As a general rule, you want this number to be as low as possible but still not randomly triggering the system.  Start with the default value of '10' and only increase by small amounts (like 5 cycles at a time) if you find the system "ghosting" and turning on when nothing is moving within the zones.

<b><u>Active Park/Exit Times</u></b><br>
To understand the parking and exit times, it is important to understand how the zones work.  See the next section on [How the Parking Zones Work](zones) for more information on determining how the Park and Exit times work.  But in brief:

_Active Park Time_: Time, in seconds, that the system remains active during a parking operation before returning to Standby mode.

_Active Exit Time_: Time, in seconds, that the system remains active after all zones have been vacated.  Does not apply to a departing car and generally is only used when another object (like a person) temporarily enters and then quick exits a zone.

### Optional Side Sensor
If you added a side sensor to your build, enable it here.  The other fields only show when the side sensor is enabled, otherwise they are hidden.  Do not enable this option unless you have a physical VL53L0X sensor connected.

Setting|Default|Purpose|
---|:---:|---|
Enable Side Sensor|OFF|Toggle on to enable the side sensor.|
Sensor Data Pin|21|The ESP32's GPIO pin connected to the sensor's SDA/DAT pin.|
Sensor Clock Pin|22|The ESP32's GPIO pin connected to the sensor's SCL/CLK pin.|
Mount Location|Left|Indicates whether the side sensor is mounted to the left or right side of the car, from the driver's perspective.|

Side Sensor Positioning:<br>
Side Sensor Pos

**<u>Side Sensor Won't Remain Enabled</u>**
<br>If the side sensor is not present or it cannot be initialized during the boot process, the Side Sensor setting will automatically be set to 'Off/Disabled', regardless of the default setting.  If you find that after enabling the side sensor, it still shows as disabled after rebooting, check your side sensor and wiring.<br><br>In addition, the LED strip will briefly flash orange during the [Boot Process](booting) when the side sensor setting is enabled but the sensor fails initialization.

## Access Point Mode (no WiFI)
If you plan on installing your system in a location where WiFi is unreliable or unavailable, you can toggle the system into AP mode and disable WiFi.

>⚠️ **WiFi is required for initial onboarding**<br>WiFi is required for the initial onboarding step.  If the final installation location does not have WiFi, then onboard the controller in a WiFi location and then toggle the AP Mode before moving to the final location.
{: .important}

When Access Point Mode is enabled (and WiFi is disabled), certain other features that require WiFi are also disabled.  These include:

- MQTT / Home Assistant Discovery
- HTTP API
- Firmware Updates
- Arduino OTA Updates

>⛔ **AP Mode cannot be activated if MQTT enabled!**<br>If MQTT or Home Assistant Discovery were previously enabled in WiFi Mode, you will not be able to switch to AP Mode.  You must first disable MQTT/remove Discovery before AP mode can be enabled.
{: .warning}

See the dedicated topic [Access Point Mode](apmode) for more information on configuring and using the system via AP mode and without WiFi.

## Saving and Updating the Hardware Configuration
After making the necessary changes for your system, you **must** click the "Save & Reboot" button at the bottom of the page.

Save_Button

The 'Save' button will write the current settings to the saved configuration file.  The system will then reboot and configure the system with these new saved settings.  Once the reboot is complete, all your changes will be active.

>⚠️ **Navigating Away Will Lose Changes**<br>If you make changes on the hardware page and then navigate to a different page (or close the browser) _before_ clicking the 'Save & Reboot' button, all changes will be lost!
{: .important}

If you have made changes but not yet saved them, you can use the 'Reset' button to restore all hardware settings back to their last saved default values.

<div style="display: flex; justify-content: space-between; align-items: center; margin-top: 40px; border-top: 1px solid #333; padding-top: 20px;">
  <a href="{{ '/webapp' | relative_url }}" class="btn btn-outline"><- Previous: Web App Overview</a>
  <a href="{{ '/zones' | relative_url }}" class="btn btn-purple">Next: Parking Zones -></a>
</div>

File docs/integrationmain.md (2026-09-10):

---
layout: default
title: Optional Integrations
nav_order: 5
has_children: true
has_toc: false
---

# Optional Integrations
{: .no_toc }

---

<p align="center">
  Integrations Overview
</p>
This section is for those who prefer to let their LEDs take orders from a script rather than a sensor. Whether you're a Home Assistant power user or a terminal enthusiast, these tools let you bypass the UI and talk directly to the hardware. 🛠️

<i>Note that use of these integration methods are entirely optional and are not required for any functionality of the Parking Assistant.</i>

>⚠️ **WiFi Required**<br>If you are operating your system in Access Point (no WiFi) mode, you will not be able to enable or use MQTT or the HTTP API as these methods require WiFi for communication.
{: .important}

> **&nbsp; Attention Home Assistant Users!**<br>
While you can certainly manually integrate the Parking Assistant using MQTT, check out the [Home Assistant Discovery](discoverymain) section for how you can safely add, edit and even remove the Parking Assistant to or from Home Assistant instantly with a single button click.  **No YAML needed!** 👍
{: .note }

When it comes to interacting with the Parking Assistant system via third party systems, there are two primary options available:

### MQTT
Message Queuing Telemetry Transport (MQTT) is a lightweight messaging protocol designed for IoT communication. If you have an MQTT broker and a system that can publish/subscribe to topics, you can fully automate the system’s states and settings. 

* **Learn more at:** [MQTT.org](https://mqtt.org/)
* **Implementation &amp; Topics:** [MQTT Setup & Topics]({{ '/mqtt' | relative_url }})

### HTTP API
The only requirement for using this method is that a third party system must be able to POST a message to a URL (the IP address of the controller).  For example, the following could be used to turn on the LEDs:

`http://[your_controller_ip]/api?ledstate=on`

<i>Note:  Since these are just URLs, you could also POST messages to the system via a browser, using any device on the same network.</i>

* **Implementation &amp; Commands:** [API HTTP Command List]({{ '/api' | relative_url }})

<div style="display: flex; justify-content: space-between; align-items: center; margin-top: 40px; border-top: 1px solid #333; padding-top: 20px;">
  <a href="{{ '/commands' | relative_url }}" class="btn btn-outline"><- Previous: Controller Commands</a>
  <a href="{{ '/mqtt' | relative_url }}" class="btn btn-purple">Next: MQTT Setup & Config -></a>
</div>

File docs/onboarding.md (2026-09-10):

---
layout: default
title: Onboarding
parent: Getting Started
nav_order: 2
has_toc: false
---

# Onboarding and First Time Setup
{: .no_toc }

---

<p align="center">
  Onboarding Header
</p>

Once you have successfully flashed the firmware to your ESP32, the next step is to connect it to your local Wi-Fi network. 

**🌐 Local Network Reminder**<br>While this device requires a Wi-Fi connection for the initial setup, it **does not** require any Internet access for full functionality. Switching to "**Access Point (no WiFi)**" mode can be done after initial onboarding and setup.
{: .note }

## 1. Joining Local WiFi
For the initial onboarding and setup, WiFi is required.  If your planned location does not have reliable WiFi, you can complete these initial steps in a different location, such as inside your house.  Only the ESP32 is needed for this step, so you can flash and onboard it before assembly, or if you used the recommended pin headers, simply remove the ESP32 and take it to a WiFi-enable location.

**🚫 Special No WiFi Mode**<br>While mentioned a few times, you can opt to run the system in "Access Point" mode for situations where WiFi may not be available, such as in a detached garage or outbuilding.  However, the initial onboarding and setup steps need WiFi.  Flash and complete these onboarding steps in an area where WiFi is available.  After setup, you can switch off WiFi before final installation.
{: .important }

### Step 1: Join the Hotspot
Once flashed, the controller will broadcast its own Wi-Fi network. It’s essentially a very tiny, very exclusive club where the only item on the menu is "Configuration." If your phone warns you that the network has no Internet access, take a deep breath. <i>Shall we play a game?</i> No—we're just setting up Wi-Fi and getting an IP address, not launching global thermonuclear war. Select 'Stay Connected' and proceed.

The default name for the Wi-Fi hotspot is: `Parking_Assistant_AP`

_As noted earlier, these hotspot names may show your assigned DeviceName_AP instead of the above._

04Onboard_03_AP

Use a phone, tablet, or laptop to join the hotspot. Remember, if your device warns you that there is "No Internet Connection," select **Stay Connected**.

### Step 2: Access the Onboarding Form

Depending upon your device and operating system, selecting the AP will automatically open a browser and display the onboarding page.  However, if this doesn't happen, simply open a web browser and enter the IP address: **`192.168.4.1`**. The onboarding form will appear: 

04Onboard_04_Forms

Fill out the following common fields for both controller types:
* **SSID:** Your Wi-Fi network name (must be the same network as device being used to onboard).
* **Password:** Your Wi-Fi password.
* **Device Name:** A unique, short name (up to 16 alphanumeric characters plus the hyphen [-], no spaces). 
    * *Examples:* `ParkAsst-01` or `Garage-Left`. 
    * Each controller on your network **must** have a unique name.
      * The device name is not only used to help you identify which controller is being accessed via the web application, but this is also used for the WiFi connection and as the MQTT client if MQTT is enabled.  Therefore, all devices should have a unique name across all other devices on your local network.

>⚠️ **Verify All Information Before Submitting!**<br>Once the system successfully joins WiFi, any future changes of the **WiFi credentials** or the **Device Name** will require a full [system reset](commands#reset-all) and onboarding again.
{: .important}

### Step 3: Submit and Verify
Once you have completed all fields, click **Submit**. The controller will reboot and attempt to join your network. The onboarding page on your mobile device will show the connection status.

onboard_pending

Depending on your WiFi strength, it may take up to two minutes for the connection to be established.  Do not navigate away from the status page or change the Wifi connection on your mobile device during this process.

onboard_success

Once the controller successfully joins your WiFi, the status page will update to a 'Success' message and the page will show your SSID and more importantly the <b>newly assigned IP address</b> for the controller.  This is the IP address you will use to access the firmware's web application and settings.

The controller will stop broadcasting the hotpsot and your phone or mobile device will disconnect and <i>should</i> reconnect to your normal WiFi.  Once this step is complete, you can even use the 'Visit Device' button to immediately go to the controller's web interface.

As another visual indicator, the _blue_ LED on the ESP32 will light up when a successful WiFi connection is made.

onboard_led

You can toggle this feature off later if you do not want the blue LED to remain on.

But if the controller is unable to connect to your WiFi for any reason, the following status page will be shown instead:

onboard_fail

If you see the above 'Timeout' page instead of the 'Success' page, it means the controller was unable to connect to your WiFi using the provided information.  This could be an improperly entered SSID or password (these are CASE-SENSITIVE), a firewall issue or other network-related problem.  When this occurs, the hotspot will start broadcasting again.  If you are still on the hotspot WiFi, you can simply click 'Try Again' to return to the onboarding page.  If your phone disconnected from the original hotspot, you'll need to reconnect before returning to the main `192.168.4.1` onboarding page.

If you run into any issues with the onboarding process, see the [Troubleshooting](troubleshooting) section for common issues and resolutions.

## 2. Assign Static or Reserved IP Addresses

This step is optional, but I recommend assigning a static or reserved IP address to the controller.  This way, you'll always use the same address to access the web interface.  If you don't implement this option and your router assigns a new IP address at some point, you'll have to locate this IP before you can reach the web app.

1. Open your router's configuration page.
2. Create a **Static IP or DHCP Reservation** for the Parking Assistant Controller.
3. Power cycle each device to ensure it is using the newly assigned static/reserved IP.

---

## 3. Final Hardware Integration
At this point, you should move your controllers from your computer to their final positions (either on a breadboard or to their permanent soldered board). 

**🚫 No WiFi Mode**<br>If you are planning on enabling the WiFi mode and your installed location does not have reliable WiFi, you can enable that option before moving the controller.  See the following section on [Access Point Mode](nowifimode) for more informaion.
{: .warning }

### Build Resources
If you haven't completed the physical build yet, refer to these guides:
* **[YouTube Overview]({{site.links.youtube_video}})**
* **[Written Build Guide](https://resinchemtech.blogspot.com/2026/08/parking-assistant-2026.html )**

> **⚠️ Additional Setup Required**<br> Don't expect the system to function as expected immediately after onboarding. Initially, the system will use a number of default startup settings.  This includes things like the number of LEDs, power settings, zone distance and colors and so on.  You will need to complete some additional hardware settings via the controller's web interface and save these changes to the local configuration for each controller after it is onboarded for full functionality.
{: .important }

Once your hardware is connected and powered, you can jump to the [Hardware Configuration](initconfig) section to finish the controller setup.

<div style="display: flex; justify-content: space-between; align-items: center; margin-top: 40px; border-top: 1px solid #333; padding-top: 20px;">
  <a href="{{ '/installation' | relative_url }}" class="btn btn-outline"><- Previous: Installation</a>
  <a href="{{ '/booting' | relative_url }}" class="btn btn-purple">Next: The Boot Process -></a>
</div>

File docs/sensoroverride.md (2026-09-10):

---
layout: default
title: Overriding the Sensors
parent: General System Use
nav_order: 3
has_toc: false
---

# Overriding the Sensors
{: .no_toc }

---
<p align="center">
  sensor override
</p>
>🔎 For the purposes of this topic, "sensors" refers to both the front and side sensor.  If your system does not have a side sensor installed and enabled, then the information only applies to the front sensor.
{: .note}

The primary purpose for disabling the sensors is when you want to control the system (primarily the LEDs) via an external system, like Home Assistant.  For example, maybe you want to flash the LEDs in response to some event or trigger.  By overriding the sensors, the LEDs are completely under manual control and will not respond to any triggers from the sensors.
<br>
### Overriding the Sensors via the Web App
Override switch

The master switch to disable the sensors can be found on the main web page under the sensor distance section.

>🔎 **Changing the Override Setting is Immediate!**<br>The sensor override setting is the only setting on the page that takes effect <i>immediately</i> upon changing the toggle, without the need to 'Apply' or 'Save' the setting.
{: .warning}

When the sensors are disabled, you cannot make any changes to the zone or side distances.  MQTT updates, if enabled, will still occur, but sensor data will only be updated per the configuration teleperiod.  See the [MQTT Setup &amp; Config](mqtt) for more information on using MQTT.

### Remotely Disabling/Enabling the Sensors
As mentioned, the most common reason for disabling the sensors is so that the LEDs can be controlled manually from a third-party system.  But to use the LEDs in an external automation or script, that system also needs a way to disable the sensors before controlling the LEDs and then re-enabling the sensors when done.

Luckily the system supports this option via two methods: MQTT or the HTTP API.  The use of MQTT and the API are later covered under [Optional Integration](integrationmain) section, but as a quick example of how the sensor override might be used by an external system:

<b><u>MQTT Example</u></b>

For this example, the remote system would post an MQTT message such as the following to first disable the sensors (note the topic is defined as part of MQTT setup):

Topic: `cmnd/parkasst/sensoroverride`<br>
Payload: `on` 

Using a payload of `on` disables the sensors.  Additional messages could then set the state, color and brightness of the LEDs. 

Topic: `cmnd/parkasst/ledstate`<br>
Payload: `on`

Topic: `cmnd/parkasst/ledcolor`<br>
Payload: `255,0,0`

Topic: `cmnd/parkasst/ledbrightness`<br>
Payload: `128`

When the automation or manual control is complete, the system is returned to normal operating mode by turning the sensor override setting back to 'off'.

Topic: `cmnd/parkasst/sensoroverride`<br>
Payload: `off` 

<b><u>API Example</u></b><br>

This is actually easier, since the API allows commands to be chained together in a single call.  Recreating the above process to disable the sensors and turn on the LEDs, set the color and LED brightness can all be done with a single API command:

`http://[your_controller_ip]/api?sensoroverride=on&ledstate=on&ledcolor=ff0000&ledbrightness=128`

Then to simply reenable the system:
`http://[your_controller_ip]/api?sensoroverride=off`

>⚠️ **Troubleshooting Note**<br>If you find that the Parking System suddenly stops working, double-check the sensor override switch.  The issue could be that this setting was toggled on via an external system and never reset back to normal operating mode.
{: .important}

<div style="display: flex; justify-content: space-between; align-items: center; margin-top: 40px; border-top: 1px solid #333; padding-top: 20px;">
  <a href="{{ '/zonecolors' | relative_url }}" class="btn btn-outline"><- Previous: Zone Colors &amp; Effects</a>
  <a href="{{ '/commands' | relative_url }}" class="btn btn-purple">Next: Controller Commands -></a>
</div>

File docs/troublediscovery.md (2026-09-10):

---
layout: default
title: Home Assistant & MQTT
parent: Troubleshooting
nav_order: 4
---

# Home Assistant and MQTT Issues
{: .no_toc }

---

<p align="center">
  [Troubleshooting image]
</p>
Most MQTT and Home Assistant Discovery issues are the result of a configuration mismatch or a "stuck" message in the MQTT broker. Because MQTT is a middle-man service, troubleshooting often requires a utility that allows you to see exactly what is being broadcast.<br><br> 
I highly recommend **[MQTT Explorer](https://mqtt-explorer.com/)**. It is a free, open-source tool that acts as a window into your broker, allowing you to see if the Parking Assistant is actually talking and what it’s saying.

## General MQTT Issues
If your external system doesn't seem to be receiving MQTT messages from the controller, or if the controller doesn't seem to accept MQTT commands sent, the first thing to verify are the connectivity to the broker, then the MQTT topics and payloads.

### Broker Connectivity

During the boot process, the system will attempt to connect to the MQTT broker.  It will try up to 10 times. If the [Boot Indicators](booting) are enabled, the LED strip will be used to show if there is an issue connecting to the broker.  This could occur if you entered the wrong IP address, port or credentials when you setup the integration.

LED Strip
<br><br>
For a "normal" connection, only one or two LEDs may light up in green (or it may happen so quickly you don't see the green LEDs at all).  However, if there is an issue, you'll see another LED light up every 3-5 seconds as a new connection attempt occurs.  If the connection fails after 10 attempts, the full LED strip will briefly flash yellow and MQTT will be disabled.  Check your broker settings after the boot process continues.
<br><br>
<i>If there is an connectivity or settings issue, the connection attempt may take up to 60 seconds.  The web application will be unavailable during this time and won't be accessible until the boot operation completes.</i>

### Case Sensitivity
<br>
**<u>MQTT Topics</u>**<br>
For most MQTT brokers, topics are <B>CASE SENSITIVE</b>!

`stat/parkasst/ledstate` and `stat/ParkAsst/LEDState` are two completely different topics.  Assure that any commands sent.. and topics listened to by an external system... exactly match the topic (including case) that you configured under the controller's [MQTT Settings](mqtt).

**<u>MQTT Payloads</u>**<br>
MQTT payloads may also be case-sensitive, depending upon the system that is subscribing to and using those payloads.  If the third party system sees a value of "ON" and "on" as two different values, then the external system may need to test for both values.

However, the MQTT commands (subscribe topics) for the controller will accept either lower or upper case for most payloads.  For example, any of the following are valid for sending an "on" state to the controller via MQTT:
`on, ON, On, True, true, TRUE, 1`  

When publishing a state, the controller will always use an upper case `ON` or `OFF`, which is what Home Assistant expects.

The [MQTT Topics](mqtttopics) section lists example payloads for both the published state topics and subscribed topics.  If an MQTT command isn't being processed properly, just be sure to check both the topic and case of the topic and payload.

### Topics Not Updating as Expected
<br>
Recall that when the system is in "Standby" mode (which also includes backing out or departing), MQTT topics are only refreshed once per defined 'tele-period' unless a settings change occurs.  This means that a car's presence, zone and sensor distances will not update upon departure until the car clears all zones and the exit time expires.

See the [Telemetry Period and When State Topics are Updated](mqtt#telemetry-period-and-when-state-topics-are-updated) for more details on when MQTT topics are refreshed.

## Home Assistant Discovery: No Device or Entities Created
If you run the Discovery process in the web app but nothing appears in Home Assistant, verify the following:

* **Prerequisites:** Ensure you’ve met all the steps in the [MQTT Setup & Configuration]({{ '/mqtt' | relative_url }}) section.
* **The Integration:** Ensure you have installed the [**MQTT Integration**](https://www.home-assistant.io/integrations/mqtt/) within Home Assistant itself. This is separate from the Mosquitto broker add-on.
* **Default Settings:** Discovery relies on standard Home Assistant conventions. If you have changed the default settings of the MQTT integration in HA, Discovery may fail.

### Home Assistant MQTT Default Parameters
Ensure your Home Assistant MQTT configuration matches the default values. If you have not modified the MQTT integration options in Home Assistant, these should be your current settings:

| Parameter | Value | | Parameter | Value |
| :--- | :---: | :--- | :--- | :---: |
| **Enable Discovery** | `ON` | | **Birth message retain** | `OFF` |
| **Discovery Prefix** | `homeassistant` | | **Will message topic** | `homeassistant/status` |
| **Enable birth message** | `ON` | | **Will message payload** | `offline` |
| **Birth message payload** | `online` | | **Will message QoS** | `0` |
| **Birth message QoS** | `0` | | **Will message retain** | `OFF` |

## Home Assistant Discovery: Deleted Entities Reappear
If you delete a device in Home Assistant but it "ghosts" back into existence after a reboot, you likely have a **retained message** stuck in your MQTT broker. 

Usually, using the **REMOVE DISCOVERY** button in the Parking Assistant's web app prevents this. However, if you’ve reset your controller or replaced the hardware, the old "discovery" messages might still be sitting on your broker, telling Home Assistant that the old device still exists.

### Cleaning Up "Stuck" Topics
To manually purge these messages using MQTT Explorer:
1. Locate the `homeassistant/` topic.
2. Navigate through the sub-topics (e.g., `binary_sensor`, `light`) to find the entry matching your old device name.
3. Highlight the specific topic and click the **Trash Can** icon to delete it from the broker.

&emsp;&emsp;retained topics

You may have a lot of discovered entities from other projects as well at this one.  If you have difficulty identifying the proper topic, all Discovery topics use the MAC address of the controller.  You can see MAC address of the controller on the main page of the web application.  Use this to identify the topics added via discovery.

Repeat the above steps for all "ghost" or reappearing entities in Home Assistant.  If the device is still present, it will be removed when the last associated entity is removed.

> **⚠️ Proceed with Caution**<br>Only delete topics created by the Discovery process for the PARKING ASSISTANT controller! Deleting other retained messages in your broker may impact or disable other smart devices in your home. When in doubt, refer back to the [Home Assistant Discovery]({{ '/discoverymain' | relative_url }}) section for a full list of entity names.
{: .warning }

<div style="display: flex; justify-content: space-between; align-items: center; margin-top: 40px; border-top: 1px solid #333; padding-top: 20px;">
  <a href="{{ '/troubleoperation' | relative_url }}" class="btn btn-outline"><- Previous: General Operational Issues</a>
  <a href="{{ '/troublefaq' | relative_url }}" class="btn btn-purple">Next: FAQ & Getting Help -></a>
</div>

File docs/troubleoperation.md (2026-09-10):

---
layout: default
title: General Operational Issues
parent: Troubleshooting
nav_order: 3
---

# General Operational Issues
{: .no_toc }

---

<p align="center">
  [Troubleshooting image]
</p>

If you've verified your wiring, assigned GPIO pins and the other steps covered under the preceding [Configuration &amp; Hardware Issues](troubleconfig) topic, or if a previously working system suddenly stops, check the following for additional steps.

## Cannot Access Web Application
If you've completed the [Getting Started](startingmain) steps (installing and onboarding) but cannot reach the web application, check the following:

<b><u>Blue LED on the ESP32 is illuminated</u></b>

esp32 blue led

Most ESP32 boards have two LEDs... one for power and one that is controllable via a GPIO pin. By default (and unless previously disabled), the Blue LED will be illuminated when the system connects to your WiFi.  If this LED does not light up, then the system is not on your WiFi and you will be unable to reach the web app (unless running in AP Mode... see below).

<b><u>Are the LEDs on the ESP32 Flickering?</u></b>

Watch the LEDs on the ESP32 for a few moments.  If they are flickering or briefly going out and then turning on again, it is an indication that the board is stuck in a boot loop.  This is generally caused by either a bad flash or an invalid entry for the WiFi credentials.  The best bet is to try flashing the original firmware via USB cable again, as covered in the [Initial Firmware Installation](installation) section.

<b><u>Is the Onboarding HotSpot Still Broadcasting?</u></b>

Use a phone, tablet or laptop and see if the original onboarding HotSpot is still being broadcast:

AP Hotspot

The hotspot is only shown if the system is unable to join WiFi.  If this hotspot is still broadcasting, join it and try the onboarding process again, verifying your WiFi SSID and password are correct (remember that these are <i>case-sensitive</i>).

<b><u>Is System Running in AP Mode (no WiFi)?</u></b>

AP Hotspot

If you previously configured your system for [AP Mode](apmode) (no WiFi), then you must join the specified hotspot with a mobile device.  The web application will be available via a browser by using the URL:  `http://192.168.4.1`

<b><u>Check Local Network Settings</u></b>

If operating using normal WiFi mode, check your router/firewall settings to assure communications between the controller and device attempting to display the web application are not being blocked or otherwise prevented.  The system does not require any special configuration other than standard HTTP traffic.  But the system needs to both initiate and respond to HTTP requests.  Note this if using VLANs and update your rules accordingly.

>🌐 **Arduino OTA Updates**<br>The only network exception to the above is that is you are using the Arduino IDE to modify the firmware and want to flash your modified code over-the-air (without connecting via USB cable), the OTA functionality requires mDNS.  This is an Arduino IDE requirement to map virtual ports.  If you aren't planning to modify the firmware or will flash via USB, then mDNS is not required for any other function.
{: .important}
 
## System Will Not Exit Standby Mode

This is probably one of the most common issues I hear about... and the cause is almost always the same.

Recall from the [How the Parking Zones Work](zones) topic, the system will not "arm" and be awakened by a vehicle until all zones have first been cleared.  Odds are, your front sensor is detecting an object within one or more of the zones, even when they appear to be empty.

Wall Detected<br>
<i>Sensor placed too close to side wall</i>

Bike Detected<br>
<i>Stationary object exists in a zone</i>

If a stray lawnmower or garbage can sits 2 inches inside the Wake Zone, the sensor will stare at it indefinitely like a cat watching a ceiling fan. Clear all obstacles from the zones so the system can re-arm for the next arrival.

Use the [Calibration Mode](sensorcalibrate) to verify the actual distance being reported by the front sensor.  If it is reporting a distance less than the Wake Zone distance even when the zones should be "empty", odds are either it is detecting an unexpected object... or the sensor is faulty or returning an error code.

## Other Operational Issues
There are various other reasons why the system may not be responding as expected.  The following are some of the most common reasons... and how to resolve them.

### Verify Sensor Override Settings
Recall that the system has a [Sensor Override](sensoroverride) feature.  If this option is enabled/ON (enable via either the web app or by an external MQTT/API call), then the parking process is bypassed and nothing will happen with the LEDs.  Use the web application to check this setting and turn 'OFF' to return the system to normal operation.

### System was left in Calibration Mode
Also recall from the [Calibration Mode](sensorcalibrate) topic, when calibration is active, all other features are secondary... including how the system responds to a parking car.  Exiting the calibration page and returning to any other page in the web app exits calibration mode.

However, if you simply closed the browser without exiting calibration mode, it will remain in the 'calibration state'... impacting normal operation.  If this occurs, just relaunch the web application.  Just loading the main page will exit the preceding calibration mode.

### System show Side Sensor as Disabled
If you previously enabled the side sensor, but it is shown as disabled in the web interface, this means that the system was unable to initialize the VL53L0X during the boot process.  This could be a result of incorrect wiring (SDA/SCL reversed) or could be a signal issue if you have a long wiring run between the controller and sensor.  See the [Build Guide]() for information on dealing with long cable runs to the side sensor, as a signal "booster" may be needed.

Also note that if the Boot LED indicator is enabled, the LEDs will briefly flash orange during the boot if side sensor initialization fails.  See the [Boot Process](booting) topic for more information.

### Other Issues Not Covered Above
If the hardware is operating correctly, most other operational issues are usually related to misconfigured settings... for example, having a 'active' zone distance that is greater than the 'wake' zone distance.  The web application generally prevents these sort of configuration errors, but if MQTT or the API are used to set these values, these checks are not executed.

Some other common misconfiguration issues include:

- <i>Setting any LED color to "Black" (or other very dark color).</i>  The LEDs may appear in an 'off' state when technically they are on and functioning.  Avoid use of any dim/dark colors for any of the Zone settings (except maybe 'Standby' - although a standby brightness of "0" is recommended over using a black/dark color if you wish to disable the standby indicators).

  - >👉 **Disabling the Standby Indicators**<br>If you wish to disable the Standby indicators, it is recommended to set the Standby Brightness to "0" as opposed to assigning a black or other dark/non-visible color.
{: .note}

- <i>Setting Running Brightness Too Low</i>.  Similar to using a dark color, setting the running LED brightness level too low may not illuminate the LEDs.  As a general rule, be sure the running LED brightness has a value of at least 5 or greater.

## Still Having Issues?
If none of the above, or other troubleshooting steps do not resolve your issue, then see the [FAQ &amp; Getting Help](troublefaq) topic for additional options.

<div style="display: flex; justify-content: space-between; align-items: center; margin-top: 40px; border-top: 1px solid #333; padding-top: 20px;">
  <a href="{{ '/troubleconfig' | relative_url }}" class="btn btn-outline"><- Previous: Config &amp; Hardware Issues</a>
  <a href="{{ '/troublediscovery' | relative_url }}" class="btn btn-purple">Next: Home Assistant &amp; MQTT Issues-></a>
</div>

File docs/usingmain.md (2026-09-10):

---
layout: default
title: General System Use
nav_order: 4
has_children: true
has_toc: false
---

# General System Use
{: .no_toc }

---

<p align="center">
  General System Use
</p>
This is where the magic happens. Now that you've done the hard work of flashing, wiring, configuring, and installing the system, it's time to actually put it to work.. Whether you're adjusting colors or zones via the web app or controlling the system via MQTT or the API, these pages cover the "how-to" of your new ESP Parking Assistant.

## Understanding Active vs. Default Settings

While this was also covered under the [Web App Overview](webapp) topic, it's worth repeating here.  Up until this point, we've primarily covered the default settings.  But there is another group of settings called the active settings.

### Default Settings
These are the settings that are saved to a local configuration file and are automatically loaded any time the controller boots up.  This includes the previously covered hardware settings, but also things like the LED color, effect and zone distances along with the LED brightness have default settings that are saved as part of the configuration.

### Active Settings
Active settings are ones you make via the web application (or via MQTT/API) that are in effect for the current active session.  They remain in effect until changed or until the controller reboots, at which point the default settings become active.

### How to Determine Which Settings are Being Modified
As a general rule, any page or section that is going to make changes to the saved defaults will have a button labeled as either "Save & Reboot" or "Set as Defaults".

default_buttons

These buttons also have a reddish/pink background to indicate they will make a permanent change to the configuration file.  Buttons that say "Apply" or have a green background generally mean that the values will only update the ACTIVE settings.  

default_buttons

Active settings are applied immediately, which is another clue.  Changes to DEFAULT settings always require a reboot to save/reload any changes.  All **active** changes are made on the main page of the web application.

<p align="center">
  General System Use
</p>

---

### In This Section
* **[Setting Zone Distances]({{ '/zonedistance' | relative_url }})** - Configure zone trigger distances.
* **[Zone Colors and Effects]({{ '/zonecolors' | relative_url }})** - Assign colors, the approach effect and overall LED brightness.
* **[Sensor Override]({{ '/sensoroverride' | relative_url }})** - Temporarily disable the sensor(s) for manual system control.
* **[Controller Commands]({{ '/commands' | relative_url }})** - System commands to reboot the system, upgrade the firmware and more.

At a minimum, you will need to configure the zone distances for your particular parking area.

<div style="display: flex; justify-content: space-between; align-items: center; margin-top: 40px; border-top: 1px solid #333; padding-top: 20px;">
  <a href="{{ '/apmode' | relative_url }}" class="btn btn-outline"><- Previous: Access Point Mode</a>
  <a href="{{ '/zonedistance' | relative_url }}" class="btn btn-purple">Next: Setting Zone Distances -></a>
</div>

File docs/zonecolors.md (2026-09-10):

---
layout: default
title: Zone Colors & Effects
parent: General System Use
nav_order: 2
has_toc: false
---

# Setting Zone Colors and the Approach Effect
{: .no_toc }

---

<p align="center">
  Zone Image
</p>
Each of the parking zones can be assigned a different LED color.  In addition, the Active (or approach) zone can use different effects to indicate the approach to the Parked zone.  

Zone Image

Again, these settings can be found on the main page of the web application.
<br><br>
Zone Image

Zone | LED Strip
---|---
Wake | When a vehicle first enters the Wake zone, all LEDs will light up in the Wake Zone color.
Active|The LEDs will begin to light up using this color and the selected Effect (see below).
Parked|The entire LED strip will light up in this color.
Backup|If the vehicle pulls too far forward and enters the Backup Zone, the entire LED strip will rapidly flash in this color.  Also used as the lateral guidance color (see below).
Standby|A special color for when the system is in sleep/standby mode.  Only lights one LED on each end of the strip in the selected color (and with the standby brightness). See below for more information on the Standby color and mode.

---

### Selecting a Color

To select a color for any of the zones (or standby), simply click in the color box to display a color picker.

Zone Image

From the color picker, you can simply click the desired hue on the spectrum and fine tune via a click in the larger top box.  Alternatively, you can enter a RGB color value  directly in the numeric boxes, or by clicking the small double arrows, enter a color in HSL or even Hex.  In addition, you can actually select any color from the computer's desktop using the small eye dropper.  When the desired color is selected, just click anywhere outside of the color picker.

<b><u>Picking Colors on a Mobile Device</u></b>

If you are accessing the web application on a mobile device, the color selection process may appear differently depending upon the device and operating system.  For example, here's how the color picker appears on my Android phone:

Zone Image

---

### Selecting the Active Zone Effect
While the other zones (wake, parked and backup) light up the entire LED strip in the chosen color, the Active Zone works a bit differently, lighting up the LEDs as the vehicle approaches the Parked zone.  The best way to view these effects are to simply try them out, but I'll provide an overview of the currently available options.

<b><u>Out-In</u></b><br><br>
Zone Image<br>
With this effect, the outermost pixels on each end light up when the vehicle first enters the active zone. Successive pixels light up towards the center as the vehicle approaches the parked zone, meeting in the middle just before hitting the parked zone.
<br><br>
<b><u>In-Out</u></b><br><br>
Zone Image<br>
This is basically the opposite of 'Out-In'. The LEDs start in the middle and move towards the outside edges as the vehicle approaches the parked zone.
<br><br>
<b><u>Full-Strip</u></b><br><br>
Zone Image<br>
This effect uses the entire LED strip, starting with lighting up the pixel closes to the 'wired' end of the LEDs and lighting up pixels towards the opposite end with the entire strip lit just prior to entering the parked zone. Note that since this effect (and its reversed opposite below) uses all the pixels instead half on each end like the previous two effects, sensitivity will basically be doubled for the same given active zone distance.
<br><br>
<b><u>Full-Strip-Inv</u></b><br><br>
Zone Image<br>
As you might guess, this is just the opposite of the previous Full-Strip effect where the LEDs begin at the 'non-wired' end of the LED strip and light up in series as the car approaches the parked zone.

The full strip effects might be useful in a situation where you need to mount your LED strip vertically instead of horizontally due to limited mounting space on the wall.
<br><br>
<b><u>Solid</u></b><br><br>
Zone Image<br>
This really isn't an effect, but will simply turn the entire LED strip on in the color specified in the settings. The strip remains this color until the vehicle enters the parked zone. There is no indication or change as the car moves through the active zone... the strip just remains solid through the entire active zone. Think of it more like a stoplight effect. Probably not very useful, but it is included in case you have a special use case and don't want any of the other 'countdown' style effects.

---

### Lateral Guidance Color and Effect
If a side sensor is installed and enabled, approximately 15% of the total LED count will be used to flash the LEDs on the left or right when the vehicle strays outside the lateral guidance distance. For example, if you have a total of 35 LEDs, then 5 LEDs will flash on either end to indicate a correction is required when parking.

Zone Image<br>

Note that the lateral guidance LEDs share the same color as the 'Backup Zone' color and will flash rapidly when activated. See the sections on [Hardware Configuration](initconfig) and Using the Web Inteface for more info on enabling lateral guidance.

---

### Standby Mode and LED Color
When the system enters standby mode after either the park or exit times expire, the LEDs will illuminate one LED at each end of the strip in the selected color.  

Zone Image<br>

The standby mode also has its own brightness setting so that you can use a lower brightness level when the system is asleep.  If you want to completely disable the standby indicators, simply set the standby brightness to 0.  See the next section.

---

### LED Brightness

Zone Image<br>
There are two LED brightness level settings:

<b><u>Running Brightness</u></b>: The brightness of the LEDs when 'Active' and tracking a vehicle's approach. Valid values are from 1 - 255, but at very low levels (<5), the LEDs may not appear to illuminate.

<b><u>Standby Brightness</u></b>:  This is the brightness of the two standby indicator LEDs when the system is in standby or sleep mode.  Valid values are 0-255.  If you wish to disable the standby indicators, simply set the brightness to 0.

## Testing and Saving Colors &amp; Effects
This is the same method as used for setting up and testing zone distances.

Zone Distance

When testing the system, you can rapidly check different values via the 'Apply' button.  The 'Apply' button will immediately apply your color, effect and brightness changes without the need to reboot the controller each time a change is made.  When you 'Apply' changes, the system provides two different confirmations that the changes are now active.

Zone Apply Msg

The web page will display a brief message under the buttons to confirm that current values have been applied.

Green LEDs

The LED strip will also briefly flash green to confirm new values are now active.

You can now test your new colors and effect, and continue to change/apply/test different combinations until you have them set to the best options for your situation.

### Load Defaults
At any point in time, you can reset the colors, effect and brightnesses to the last saved defaults by using the 'Load Defaults' button.  _This does not **apply** the default values... it simply loads them.  If you wish to make the defaults 'active', you must 'Apply' them after loading._

Zone Apply Msg

### Saving Distances
Once you have your options set as desired and wish to make them the new default values, be sure to save them using the 'Set as Defaults' button.  This will write your current selections to the saved configuration file, reboot the system, and load up these new values.

>⚠️ **IMPORTANT**<br>If you do not save your new options and the controller restarts for _any reason_ (power outage, etc.), then the last saved colors, effect and brightnesses will be used.  Just assure you click the 'Save as Defaults' if you wish to make your selections the new defaults.
{: .important}

Next, we'll cover a few useful controller commands that might be handy from time to time.

<div style="display: flex; justify-content: space-between; align-items: center; margin-top: 40px; border-top: 1px solid #333; padding-top: 20px;">
  <a href="{{ '/zonedistance' | relative_url }}" class="btn btn-outline"><- Previous: Setting Zone Distances</a>
  <a href="{{ '/sensoroverride' | relative_url }}" class="btn btn-purple">Next: Overriding the Sensors-></a>
</div>

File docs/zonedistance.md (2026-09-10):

---
layout: default
title: Setting Zone Distances
parent: General System Use
nav_order: 1
has_toc: false
---

# Setting Zone Distances
{: .no_toc }

---

<p align="center">
  Zone Image
</p>

Before configuring your Zone distances, it is very important that you understand how the [Parking Zones](zones) work.  Review that topic if you are unsure.  Incorrectly setting the zone distances could result in the driver contacting a wall or other object.

>❗ **CAUTION**<br>Be sure to thoroughly test your configuration before attempting to use it with an actual vehicle.<br><br><i>I cannot be responsible for damage that might occur due to use of this system.  It has proved very reliable in my use, but final responsibility for proper setup, testing and use are entirely yours!</i>
{: .warning}

I strongly recommend you start by initially configuring your zones using a medium-sized objects like a rolling garbage can or even a 2-3 ft. square of cardboard.  Using these, you can set your initial zone distances.  Only when you feel your zones (especially the parked and backup zones) are close should you attempt to use an actual vehicle.

It will likely take a few attempts to get the zones just right and you will probably even adjust them a time or two after you put the system in use.  But once 'zeroed in', you should not need to change the distances unless the parking area changes or a different vehicle is used.
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

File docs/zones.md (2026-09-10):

---
layout: default
title: Parking Zones
parent: Setting Up the System
nav_order: 3
---

# How the Parking Zones Work
{: .no_toc }

---

<p align="center">
  Zone Header
</p>

To understand how the system works, specifically for some options like the Park and Exit times, it is important to understand how the system operates.
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

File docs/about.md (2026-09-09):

---
layout: default
title: About this Project
parent: Welcome
nav_order: 1
has_toc: false
---

# About this Project
{: .no_toc }

---

<p align="center">
  Car in garage
</p>

## The Problem
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

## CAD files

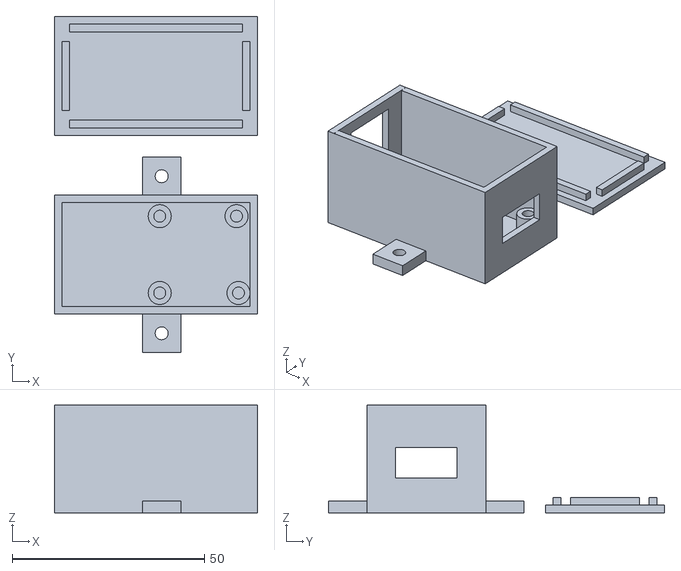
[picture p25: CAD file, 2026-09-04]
stl/QwiicBus Enclosure.stl
53.0 x 87.5 x 28.0

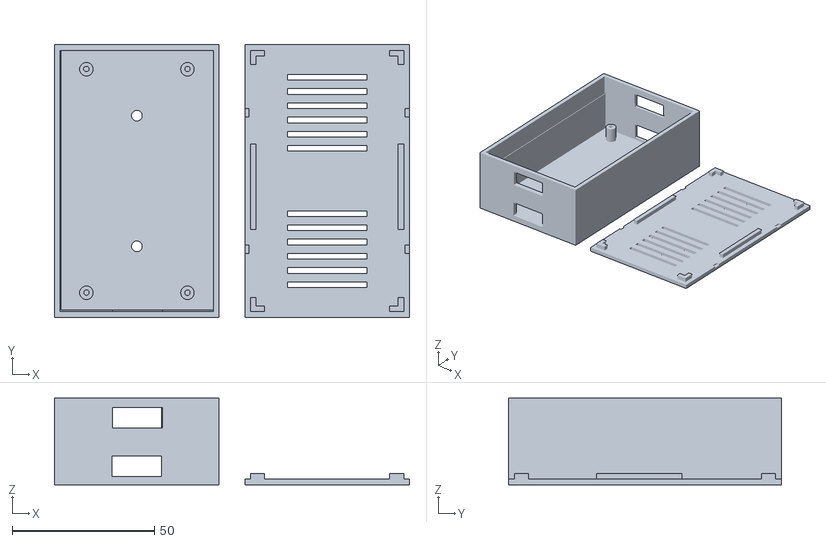
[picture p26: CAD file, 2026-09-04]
stl/Controller Enclosure Basic.stl
125.0 x 96.0 x 30.5

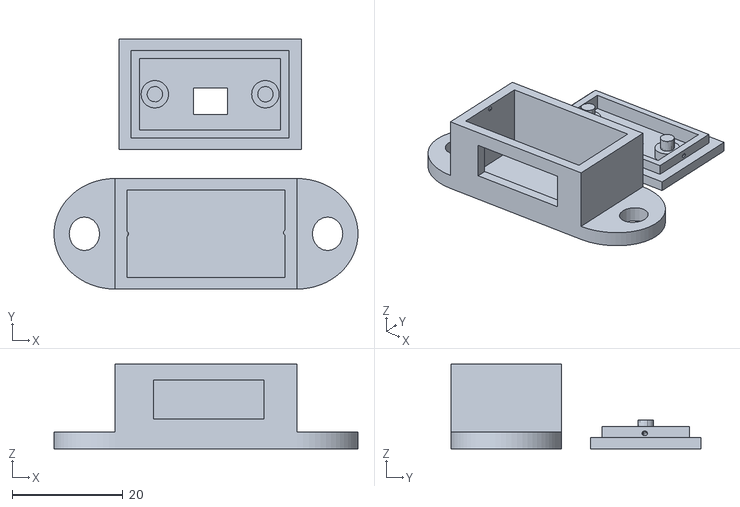
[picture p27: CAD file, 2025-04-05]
stl/VL53L0X SideSensor Mount.stl
55.0 x 45.2 x 15.3

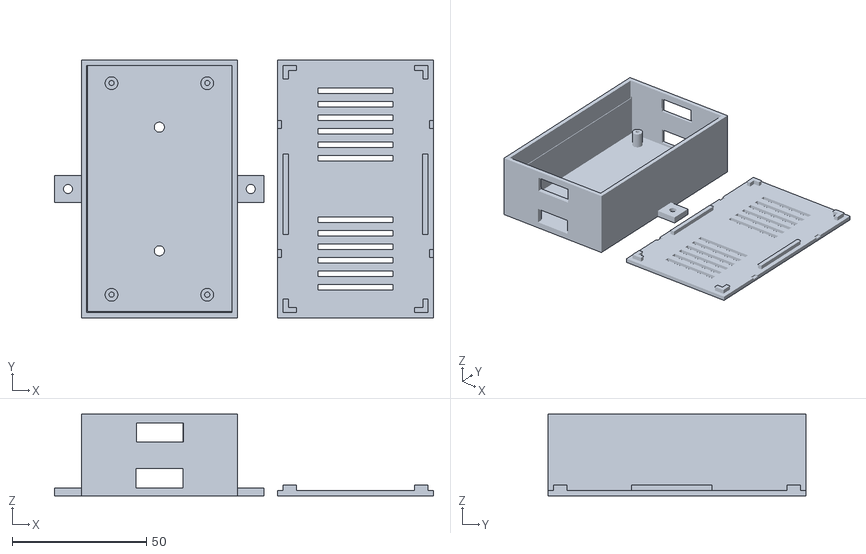
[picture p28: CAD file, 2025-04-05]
stl/Controller Enclosure with Mount Tabs.stl
141.0 x 96.0 x 30.5

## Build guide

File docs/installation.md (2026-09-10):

---
layout: default
title: Initial Firmware Installation
parent: Getting Started
nav_order: 1
has_toc: false
---

# Initial Firmware Installation
{: .no_toc }

---

<p align="center">
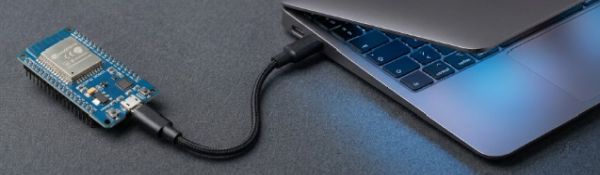
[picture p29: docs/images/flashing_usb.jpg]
Initial Firmware Installation
  
</p>

The first step in preparing your ESP32 hardware is flashing the initial firmware onto the controller.

## 🛑 Which Path Are You On?

Before proceeding, determine which of the following three installation scenarios applies to your system:

1. **🆕 New Build / Fresh Board:** You are flashing a brand-new ESP32 or completely resetting a board. **Stay on this page and use the WebSerial flasher below.**

2. **🔄 Routine Firmware Update (v0.60 to v0.61+):** Do **NOT** use this page. Routine updates are applied wirelessly using the [Firmware Upgrade]({{ '/firmwareupdates' | relative_url }}) feature inside your running system's web interface.

3. **⚠️ Migrating from v0.52 or Earlier:** Stop here! Due to partition layout changes in v0.60+, wireless OTA updates from legacy versions are not recommended. Please follow the step-by-step **[v0.52 to v0.60 Migration Guide]({{ '/migration' | relative_url }})**.

---

## Prerequisites for New Installs

To complete the USB installation on this page, you will need:

* **Hardware:** A computer with an available USB port and a **microUSB Data Cable**. (Note: "Power-only" charging cables will not work).
* **Software:** A Chromium-based desktop browser (Google Chrome, Microsoft Edge, Brave, or Arc) version 89 or newer.
* **Firmware File:** The installer below automatically fetches the latest stable binary (`ParkingAsst_vX.XX_Full.bin`), but versions following v0.60 will allow selecting which version to install. If you prefer traditional desktop tools or want to install a version prior to v0.60, download the file from the [GitHub Releases](https://github.com/Resinchem/ESP-Parking-Assistant/releases) page.

**🖥️ Desktop Utility Alternative**<br>If you prefer not to use a Chromium-based browser with WebSerial, you can use desktop flashing tools (like esptool or ESPHome Flasher). Refer to the [Beginner's Guide to Flashing Custom Firmware](https://youtu.be/74NGHj-cOls?t=488) video (skip to the **8:08** mark).
{: .note }

---

## 👉 Install FULL Firmware Here

**⚠️ NEW INSTALLS ONLY** - Installs the `ParkingAsst_vX.XX_Full.bin`
{: .important }

Installing the **Full** firmware image completely erases the controller's internal flash memory, wiping any saved Wi-Fi and device settings. If you are trying to update a working system (<i>running v0.60 or later</i>) without losing settings, use the embedded app's [Firmware Upgrade]({{ '/firmwareupdates' | relative_url }}) feature instead.

{% include flasher.html %}

**🖥️ USB Drivers: The Invisible Gatekeepers**<br>If your computer treats your ESP32 like an unrecognized device, you might be using a charge-only USB cable. Try a second known data cable before troubleshooting further.
{: .note }

**🔍 Troubleshooting COM Ports**<br>If no new COM port appears when plugging in your board (and you are using a verified data cable), you may need to install the **CP2102** or **CH340** USB-to-Serial drivers for your specific ESP32 board.
{: .note }

---

## Success Criteria & Hotspot Verification

Once flashing completes:

1. Unplug and reconnect the USB cable to power cycle the ESP32.
2. Wait 10–15 seconds for the controller to initialize.
3. Scan for available Wi-Fi networks on your phone or computer.

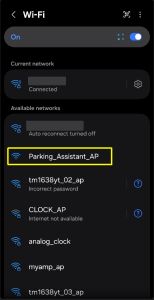
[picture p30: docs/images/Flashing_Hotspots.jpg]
Flashing Hotspots


**Success Criteria:** If you see a Wi-Fi hotspot named `Parking_Assistant_AP` (or `DeviceName_AP` if re-flashing a previously named controller), the firmware flash was successful!

---

### Next Steps

Now that your primary controller is flashed and broadcasting its setup hotspot, you are ready to connect it to your local Wi-Fi network and complete device onboarding.

Proceed to **[Onboarding and First Time Setup]({{ '/onboarding' | relative_url }})**.

> **⚠️ Multi-Device Warning**<br>If you are setting up more than one Parking Assistant, **flash and complete onboarding for the first unit before plugging in or flashing the second unit**. This prevents multiple devices from broadcasting identical default hotspots simultaneously.
{: .important }

<div style="display: flex; justify-content: space-between; align-items: center; margin-top: 40px; border-top: 1px solid #333; padding-top: 20px;">
  <a href="{{ '/startingmain' | relative_url }}" class="btn btn-outline"><- Previous: Getting Started</a>
  <a href="{{ '/onboarding' | relative_url }}" class="btn btn-purple">Next: Onboarding -></a>
</div>

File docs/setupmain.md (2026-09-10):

---
layout: default
title: Setting Up the System
nav_order: 3
has_children: true
has_toc: false
---

# Setting Up the System
{: .no_toc }

---

<p align="center">
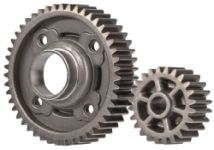
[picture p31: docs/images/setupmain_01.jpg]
System Setup Header
  
</p>

Once the system has been onboarded and the controller is booting normally, you can begin to configure the system for your particular hardware and specific parking needs.  This includes options like the number of LEDs, sensor settings and other global options.

This section covers the core configuration of your hardware and the default system settings:

* **[Web App Overview]({{ '/webapp' | relative_url }})** - Accessing the app and understanding the interface.
* **[Initial Hardware Configuration]({{ '/initconfig' | relative_url }})** - Setting up the system for your exact hardware.
* **[Sensor Calibration]({{ '/sensorcalibrate' | relative_url }})** - See raw readings from your sensor(s).  Used to assist in setting zone distances.
* **[Access Point Mode]({{ '/apmode' | relative_url }})** - Configure the system to work in a situation where WiFi may not be available.

> **💡 Configuration Logic**<br>It is important to understand that the system manages two distinct "sets" of settings:
> * **Default Settings:** Saved values loaded when the system first starts up or reboots.
> * **Active Settings:** Values currently in use (which may be temporary until the next reboot).
>
> This distinction is covered in more detail in the [Web App Overview]({{ '/webapp' | relative_url }}).
{: .note }

---

<div style="display: flex; justify-content: space-between; align-items: center; margin-top: 40px; border-top: 1px solid #333; padding-top: 20px;">
  <a href="{{ '/booting' | relative_url }}" class="btn btn-outline"><- Previous: The Boot Process</a>
  <a href="{{ '/webapp' | relative_url }}" class="btn btn-purple">Next: Web App Overview -></a>
</div>

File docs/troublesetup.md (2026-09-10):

---
layout: default
title: Initial Setup & Connectivity
parent: Troubleshooting
nav_order: 1
---

# Initial Setup & Connectivity Issues
{: .no_toc }

---

<p align="center">
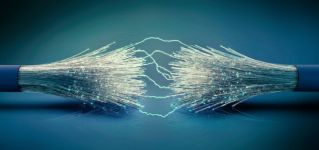
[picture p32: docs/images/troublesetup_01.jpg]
[Troubleshooting image]
  
</p>

This section covers the initial flashing of the binary firmware and the onboarding steps. If you are attempting an upgrade of existing firmware or are trying to flash source code from an IDE, please refer to the [Firmware Updates]({{ '/firmwaremain' | relative_url }}) or [Advanced Technical Information]({{ '/advanced' | relative_url }}) sections instead.

## Installation Issues
Getting the firmware onto the ESP32 is usually the hardest part. If the computer and the controller aren't talking, check these common culprits.

> **🚦 Parking Assistant Installer Use Recommended**<br>The [official installer](installation#-install-full-firmware-here) provided right here within this site is the recommended method of initially installing the firmware. If you installed the firmware using a third-party tool, you should attempt a reinstall using this method first.
{: .important}

### No COM Port Found
When you connect your ESP32 to your PC, you must select a COM port. If no new port appears, you are likely missing the USB-to-Serial drivers.

> **💡 Note**<br>These drivers are provided by third parties. Use caution when downloading and installing files. If the standard drivers fail, check your PC manufacturer's site (especially for Lenovo laptops).
{: .note }

* **[CP2102 Drivers](https://www.silabs.com/software-and-tools/usb-to-uart-bridge-vcp-drivers?tab=overview)** – Windows and Mac.
* **CH342, CH343, CH9102 Drivers:** **[Windows](https://www.wch.cn/downloads/CH343SER_ZIP.html)** \| **[Mac](https://www.wch.cn/downloads/CH34XSER_MAC_ZIP.html)**
* **CH340, CH341 Drivers:** **[Windows](https://www.wch.cn/downloads/CH341SER_ZIP.html)** \| **[Mac](https://www.wch.cn/downloads/CH341SER_MAC_ZIP.html)**

*If the driver pages appear in Chinese, right-click and select "Translate to English" in your browser, or look for the "down arrow" (↓) download button. I did not develop nor am I responsible for these drivers. Install and use at your own risk!*

### ESP32 Will Not Connect
If the drivers are installed but the board won't connect, you may need to perform the "Boot Button Dance" to force the board into flashing mode:

1. Hold down the **BOOT** button on the ESP32.
2. Apply power (plug in USB) or press the **EN/RESET** button while still holding BOOT.
3. Release both buttons simultaneously.

### Flash Succeeds, but no Hotspot Appears
If the flash finishes but you don't see an onboarding access point, the flash was likely incomplete or corrupt. Erase the flash and try again. If the problem persists, try a different utility:

1. **[ESPConnect](https://thelastoutpostworkshop.github.io/ESPConnect/) (Recommended Alternative)** – Requires a Chromium-based browser and internet connection.
2. **[ESPHome Web Flasher](https://github.com/esphome/esphome-flasher/releases/latest)** – A reliable desktop alternative.
3. **[NodeMCU PyFlasher](https://github.com/nodemcu/nodemcu-flasher)** – Use as a last resort (Windows only).

If all else fails, you may need to try compiling and flashing the source code from the Arduino IDE. It is possible that there is a compatibility issue with your particular ESP32. See [Modifying the Firmware](modifications) for more information on using the Arduino IDE to flash the firmware.

## Onboarding Issues
Once the flash is successful, the controller broadcasts a Wi-Fi hotspot. You should see a network named: `PARKING_ASSISTANT_AP`. If you do not see this hotspot after power cycling the ESP32:

* **Check the Network:** Ensure your phone or laptop is searching on the same Wi-Fi frequency (2.4GHz).
* **Proximity:** The ESP32 doesn't have the broadcasting power of a high-end router. Stay in the vicinity of the controller during this process.
* **Wait for it:** It can take 2–3 minutes for the hotspot to initialize. If it never appears after a power cycle, refer back to the flashing troubleshooting above.

## Obtaining the Controller IP Address
The onboarding process will show you the newly assigned IP address if it successfully joins your WiFi.<br>
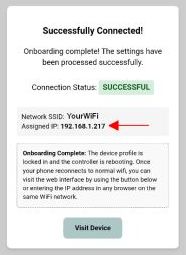
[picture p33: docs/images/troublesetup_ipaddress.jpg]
onboard_ip


However, if you missed noting the new IP address or if you disconnected your device from the Hotspot before the onboarding completed, you can still use your router to get the IP address.

router setup

If supported by your router, the Hostname should match the Device Name you assigned during onboarding.

> **💡 Static or Reserved IPs Recommended**<br>As covered in the [Onboarding](onboarding) Topic, assigning a static or DHCP reservation for your device is recommended.  This is especially true if using external interfaces such as the HTTP API, as these use the IP address of the Parking Assistant controller for communication. If the IP address of the controller changes, the external interfaces may cease operation until they are reconfigured for the controller's newly assigned IP address.
{: .important }

In addition, if the IP address of the controller changes, it changes the IP address you use to access the embedded web application.  If your system suddenly stops working or you can no longer access the web interface, check your router to assure the controller did not get assigned a new IP address.

<div style="display: flex; justify-content: space-between; align-items: center; margin-top: 40px; border-top: 1px solid #333; padding-top: 20px;">
  <a href="{{ '/troubleshooting' | relative_url }}" class="btn btn-outline"><- Previous: Troubleshooting Overview</a>
  <a href="{{ '/troubleconfig' | relative_url }}" class="btn btn-purple">Next: Configuration &amp; Hardware Issues -></a>
</div>

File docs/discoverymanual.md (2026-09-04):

---
layout: default
title: Manually Creating MQTT Entities
parent: Home Assistant Discovery
nav_order: 3
---

# Manually Creating MQTT Entities
{: .no_toc }

---

<p align="center">
  [PLACEHOLDER: Manual YAML Configuration]
</p>

While the "One-Click" Discovery is recommended for most users, some Home Assistant enthusiasts prefer the precise control afforded by manual YAML configuration. This method allows you to define unique IDs, specific icons, and custom availability logic directly in your configuration files.

> **❗ Advanced Users Only**<br>Manually creating MQTT entities requires a solid understanding of Home Assistant’s YAML structure and MQTT integration. If you are not comfortable editing `configuration.yaml`, it is highly recommended to use the [Automatic Discovery]({{ '/discoverymanage' | relative_url }}) method instead.
{: .important }

---

### YAML Example: Sensor Override Switch
If you choose the manual path, you must ensure your topics match the **Publish** and **Subscribe** topics defined in your [MQTT Settings]({{ '/mqtt' | relative_url }}).

Below is an example of how the **Sensor Override** entity might be defined in your Home Assistant configuration using YAML. 

*Note: This example assumes your chosen topic is `parkasst`.*

```yaml
mqtt:
  - switch:
      unique_id: parkasst_sensor_override
      name: "Sensor Override"
      state_topic: "stat/parkasst/sensoroverride"
      command_topic: "cmnd/parkasst/sensoroverride"
      availability:
        - topic: "stat/parkasst/status"
      payload_on: "ON"
      payload_off: "OFF"
      state_on: "ON"
      state_off: "OFF"
      optimistic: false
      qos: 0
      retain: true    
```

You can find all the relevant state and command topics for the various entities under the [MQTT Topics &amp; Payloads](mqtttopics) topic.

### Further Reference
Because the Home Assistant environment evolves frequently, the firmware is designed to follow standard MQTT conventions. For a comprehensive guide on creating lights, binary sensors, and buttons via YAML, please refer to the official documentation:

* **[Home Assistant MQTT Integration Documentation](https://www.home-assistant.io/integrations/mqtt/)**

---

<div style="display: flex; justify-content: space-between; align-items: center; margin-top: 40px; border-top: 1px solid #333; padding-top: 20px;">
  <a href="{{ '/discoveryentities' | relative_url }}" class="btn btn-outline"><- Previous: Editing or Hiding Entities</a>
  <a href="{{ '/firmwaremain' | relative_url }}" class="btn btn-purple">Next: Firmware Updates -></a>
</div>

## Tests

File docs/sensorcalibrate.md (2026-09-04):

---
layout: default
title: Sensor Calibration
parent: Setting Up the System
nav_order: 4
---

# Sensor Calibration
{: .no_toc }

---

<p align="center">
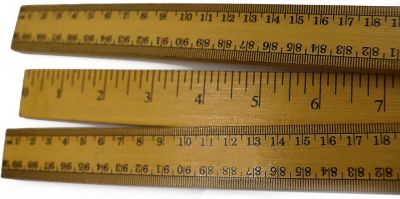
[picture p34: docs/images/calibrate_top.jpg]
Web App Header
  
</p>

On the hardware page under the sensor configuration section, you will find a "Calibration Mode" button.

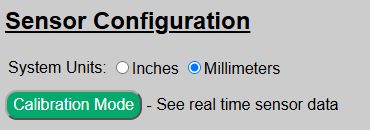
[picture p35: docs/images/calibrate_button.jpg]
calibrate button


This will open up a special calibration page where you can see real time data collected from the front sensor (TFMini-s) and the optional side sensor (VL53L0X) if installed and enabled.

>❗**IMPORTANT**<br>When the system is in calibration mode all other system functions are paused.  This not only includes triggers for the LEDs, but MQTT updates, API calls, etc. are all disabled.<br><br>**Do not close your browser when in calibration mode!**  Use the provided button to return to the hardware settings page and restore the system to normal operation.<br><br><i>If you do inadvertently close the page, just reopen the main web app page again. Opening any of the normal pages also restores the system.</i>
{: .warning}

### Using the Calibration Data

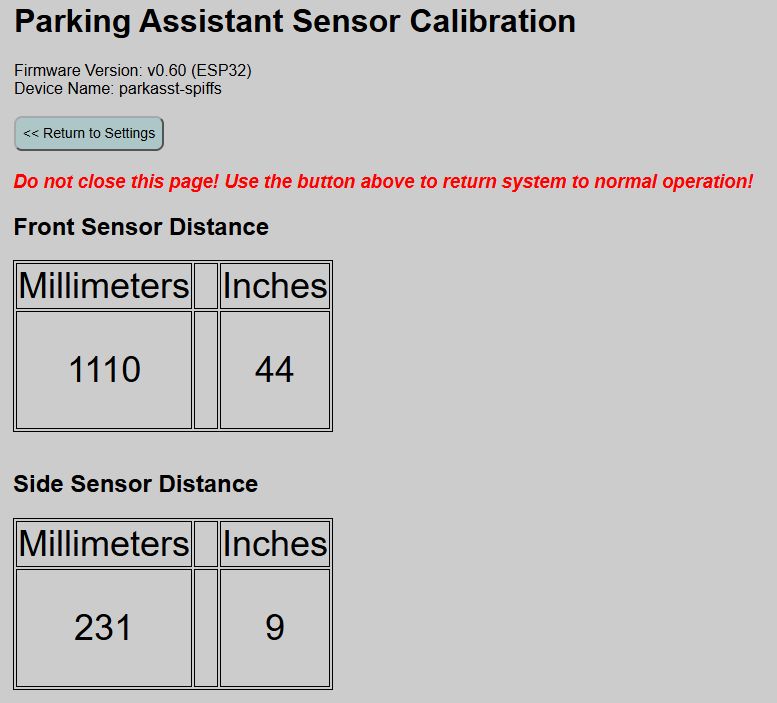
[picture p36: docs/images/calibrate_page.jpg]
calibrate_page


The Calibration page will display the current raw distance reading of the TFMini-s front sensor and the VL53L0X side sensor (if enabled), updated once per second.  Note inches are rounded to the nearest whole integer, even though zone distances permit entry in tenths of an inch (e.g. 24.6").

- The values will naturally "bounce" a bit, and even when detecting a solid, non-moving object, the reported distance may vary by a few millimeters between readings.  This is normal behavior.

- If a distance of "9999" is shown, it means no object is within the range of the sensor OR an error is being returned due to a problem with the sensor.  If you place an object within a foot or two, and directly in front of the sensor, yet still get a "9999" reading, check the sensor and wiring as something isn't working correctly.

- Values of N/A mean the sensor was not detected or is not enabled.

You can then use this calibration page to help place the sensor and to determine the starting trigger distances for the parking zones that you can fine tune later.   

No values from the page are saved or used for any settings.  It is informational only.  When done with the configuration, use the button at the top to return to the hardware settings page **and return the system to normal operation**.

<div style="display: flex; justify-content: space-between; align-items: center; margin-top: 40px; border-top: 1px solid #333; padding-top: 20px;">
  <a href="{{ '/zones' | relative_url }}" class="btn btn-outline"><- Previous: Parking Zones</a>
  <a href="{{ '/apmode' | relative_url }}" class="btn btn-purple">Next: Access Point Mode -></a>
</div>

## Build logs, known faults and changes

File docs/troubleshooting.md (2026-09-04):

---
layout: default
title: Troubleshooting
nav_order: 9
has_children: true
has_toc: false
---

# Troubleshooting
{: .no_toc }

---

<p align="center">
  Troubleshooting Overview
</p>

If you find there is a "ghost in the machine" or your system isn't behaving as expected, don't panic. Electronics can be finicky, but most issues can be resolved with a bit of systematic checking. 

> **🔍 Living Document**<br>
> This troubleshooting topic will be updated if common issues/workarounds are discovered over time.  If you develop a problem or issue after you've been using the system for a while, be sure to check this topic again, as it may have been updated with new information
{: .note }

Before diving into the specific fixes below, first verify that you have reviewed the applicable sections throughout this document and the [Build Guide](https://resinchemtech.blogspot.com/2026/08/parking-assistant-2026.html) to ensure a step wasn't missed during the assembly process.  In addition, you can often find helpful information or potential problems/fixes in the following areas of the repository:
* **<a href="https://github.com/Resinchem/ESP-Parking-Assistant/discussions">Repository Discussions</a>**
* **<a href="https://github.com/Resinchem/ESP-Parking-Assistant/issues">Repository Issues</a>**

---

### 🛑 The Golden Rule of Hardware
As emphasized throughout this project, **the firmware is designed to work with specific hardware components.** 

> **❗ Support Disclaimer**<br>
> I am unable to provide technical support for builds that use substituted hardware components or modified firmware. If you decide to go "off-book" with different functions, sensors, or controllers, you are officially the lead engineer for that version! Please don't ask for support when using custom firmware modifications or unsupported hardware.
{: .important }

---

### Triage: Where is the problem?

To help you find a solution without scrolling through pages of unrelated text, the troubleshooting guide is broken down into the following categories:

* **[Initial Setup & Connectivity]({{ '/troublesetup' | relative_url }})** – Issues with COM ports, USB drivers, flashing errors, and the initial onboarding hotspot.
* **[Configuration And Hardware]({{ '/troubleconfig' | relative_url }})** - Issues with configuration and hardware setup.
* **[Daily Operation & Use]({{ '/troubleoperation' | relative_url }})** – Problems with "Save & Reboot" persistence, firmware update failures, and reviewing Config Dumps.
* **[Home Assistant & MQTT]({{ '/troublediscovery' | relative_url }})** – Discovery issues, "stuck" MQTT topics, and integration prerequisites.
* **[FAQ & Getting Help]({{ '/troublefaq' | relative_url }})** – Frequently Asked Questions and the proper etiquette for opening a GitHub Issue or starting a Discussion.

---

<div style="display: flex; justify-content: space-between; align-items: center; margin-top: 40px; border-top: 1px solid #333; padding-top: 20px;">
  <a href="{{ '/advancedpartitions' | relative_url }}" class="btn btn-outline"><- Previous: Partitions &amp; Flashing</a>
  <a href="{{ '/troublesetup' | relative_url }}" class="btn btn-purple">Next: Initial Setup Troubleshooting -></a>
</div>

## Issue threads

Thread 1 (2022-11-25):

Problems Flashing

lockkp1, 2022-11-25:
Hi, thanks so much for your write up and code. However I am having issues flashing my D1 mini with the .ino you have. Would you have the .bin file?

I tried to flash my board in NodeMCU Flasher but it doesn't seem to flash the board properly:
Auto-detected Flash size: 4MB
Erasing flash (this may take a while)...
Chip erase completed successfully in 2.2s
Warning: Image file at 0x0 doesn't look like an image file, so not changing any flash settings.
Compressed 54360 bytes to 13659...
Wrote 54360 bytes (13659 compressed) at 0x00000000 in 1.3 seconds (effective 328.2 kbit/s)...
Hash of data verified.

Leaving...
Staying in bootloader.

Firmware successfully flashed. Unplug/replug or reset device
to switch back to normal boot mode.

and then I tried to flash in ESPHOME Flasher but that wont flash at all, it gives me errors.

Thank you again

Resinchem, 2022-11-25:
Are you using the bin file ParkingAsst_v0.33_ESP8266.bin file downloaded from the releases page of this repo: [Releases](https://github.com/Resinchem/ESP-Parking-Assistant/releases/tag/v0.33)?

It appears you are trying to flash the .ino file or maybe the .zip file from downloading the code according to the error, and that won't work in this case.  Just download the .bin from the Releases page and try flashing that.

lockkp1, 2022-11-26:
Feel a bit dumb, I completely did not see it haha. Thank you so much, flashed properly and now having issues with the TF mini.

Is there anyway to diagnose the sensor? I double checked all my wiring, the lights and everything is working but as I test the distance sensor nothing seems to happen. I set my stanby lights to on to diagnose it and the lights just stay on no matter what I put in front of the sensor. I tried to adjust the values in the parkassist setup site but even still at the lowest values nothing seems to happen. I may have a defective sensor but I just wanted to see if there was anyway to tell?

Thank you so much again

Resinchem, 2022-11-26:
Unfortunately, since the TFMini-s uses the serial port on the D1 Mini, it can make diagnosing difficult since you can't put out data to a serial monitor at the same time.  But there are a few things to check:
- Make sure you didn't mix up TX/RX - TX on TFMini connects to RX on D1Mini and RX to TX.  Use the supplied cable that comes with the TFMini to verify pin locations/wire colors.
- Assure you have the TFMini-s version.  The TFMini-s (and the TFMini-plus) changed the communication data structure and the library in the code will not work with the original TFMini.
- If you have an MQTT broker, enable MQTT and set telemetry period to minimum 60 seconds.  Place a solid object 2-3 feet from the sensor and see what value it posts to MQTT for parking distance.  If a value of 65533 or 192.0 is consistently reported even if you move the object, it likely means that the TFMini is not communicating because it is either wired wrong or truly is faulty.

Those are a few ideas to try.  I'm happy to help further, but since this is a separate issue from the original flashing problem, I'm going to go ahead and close this issue.  If you continue to need assistance, you can always open a new issue here, or preferably reach out via the comments section of either the blog or YouTube video and we can take it from there.

Closed 2022-11-26.

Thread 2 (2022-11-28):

More than one device publishes to the same MQTT topic

Resinchem, 2022-11-28:
Due to the hardcoded MQTT topic in the code, installing more than one instance of the parking assistant with MQTT enabled will cause the two devices to overwrite each other in MQTT.

Currently the only fix for this issue if two or more devices are going to enable and use MQTT is to edit the source .ino file and update this line: ```#define MQTT_TOPIC_PUB "stat/parkasst"``` giving each device a unique topic (such as /parkasst1 and /partasst2).

If you are not using MQTT or only have MQTT enabled for one device, this does not impact normal operations.

Resinchem, 2022-12-02:
This issue is being merged with [Issue #5](https://github.com/Resinchem/ESP-Parking-Assistant/issues/5) as it is related to the same hardcoded values and has the same temporary fix.

Closed 2022-12-02.

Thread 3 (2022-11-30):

Potential Boot Loop

Wh1t3Fox, 2022-11-30:
I flashed the firmware on an ESP8266  D1 mini and an ESP8266 NodeMCU. I was able to access the web UI, but after entering my wifi information and LED numbers the device never allows me to access the web UI again. Nmap showed port 80 open and when I power cycle the device the flashing blue light never stops. Below is the output from the device:
```
[08:03:00] ets Jan  8 2013,rst cause:1, boot mode:(3,0)
[08:03:00]
[08:03:00]load 0x4010f000, len 3584, room 16
[08:03:00]tail 0
[08:03:00]chksum 0xb0
[08:03:00]csum 0xb0
[08:03:00]v2843a5ac
[08:03:00]~ld
[08:03:00]
[08:03:00] ets Jan  8 2013,rst cause:1, boot mode:(3,0)
[08:03:00]
[08:03:00]load 0x4010f000, len 3584, room 16
[08:03:00]tail 0
[08:03:00]chksum 0xb0
[08:03:00]csum 0xb0
[08:03:00]v2843a5ac
[08:03:00]~ld
[08:03:00]
[08:03:00] ets Jan  8 2013,rst cause:1, boot mode:(3,0)
[08:03:00]
[08:03:00]load 0x4010f000, len 3584, room 16
[08:03:00]tail 0
[08:03:00]chksum 0xb0
[08:03:00]csum 0xb0
[08:03:00]v2843a5ac
[08:03:00]~ld
[08:03:01]
[08:03:01] ets Jan  8 2013,rst cause:1, boot mode:(3,0)
[08:03:01]
[08:03:01]load 0x4010f000, len 3584, room 16
[08:03:01]tail 0
[08:03:01]chksum 0xb0
[08:03:01]csum 0xb0
[08:03:01]v2843a5ac
[08:03:01]~ld
[08:03:01]
[08:03:01] ets Jan  8 2013,rst cause:1, boot mode:(3,0)
[08:03:01]
[08:03:01]load 0x4010f000, len 3584, room 16
[08:03:01]tail 0
[08:03:01]chksum 0xb0
[08:03:01]csum 0xb0
[08:03:01]v2843a5ac
[08:03:01]~ld
```

Resinchem, 2022-11-30:
Could you possibly send me a screenshot or list of the values that you have entered in the web interface/configuration right before this problem begins?  I may not be error trapping for certain combination of values.

Also, if possible, can you look on the back of your TFMini and see which version of the sensor you have?  There should be something on the board that says TFMini v1.x.

Wh1t3Fox, 2022-11-30:
SSID: syzygy-iot
Password: 32 characters consisting of upper and lower case letters and numbers (originally I had a password with special characters and removed those)
# LEDS: 30

Will the TFMini need to be plugged in for the firmware to properly load? I haven't fully looked through the source code yet, but as of right now I was just attempting to boot the esp8266 without the LEDs or TFMini attached.

Resinchem, 2022-11-30:
Yes... the TFMini needs to be attached.  I think I mention this in both the wiki and the blog.  The code attempts to establish a serial connection to the TFMini as part of the setup process.  Actually, I'm surprised you were able to get the hotspot and web interface to show without the TFMini.

Try it with the TFMini attached.  If you are still seeing the boot loop, I'd like to see a screenshot of **all** the values you entered on the main settings page of the web interface.  Something like an invalid value in the distances could be causing something like a divide by zero error and resulting the boot loop.  You need to enter all distance values as well, but the web app doesn't error check for that (but it probably should).

Wh1t3Fox, 2022-11-30:
Ahh okay my bad. I'll give that a try

Wh1t3Fox, 2022-11-30:
I'm still having the same issues. Everything is plugged into the D1 mini.  TFmini version is 1.8.1.

Here is the wifi settings I applied. I have not been able to get to the main settings page even though I can see the device on my network.

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

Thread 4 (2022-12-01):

Code does not work with newest version of TFMini-s

Resinchem, 2022-12-01:
Others have reported, and I now have confirmed, that a newer version of the TFMini is being sold.  Currently, the code does not work correctly with the newer sensor.

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

If your TFMini-s lists v1.8.1 on the back as shown above, you can build the system as described.  Hook up the new TFMini and you can access the web app and the controller will go through the normal boot sequence (all blue lights, followed by red & green lights), but then goes into standby mode and does not respond to objects in front of the sensor.

I am working on a fix and will release a new version of the firmware that works with the newer sensor as soon I have developed and tested it.  If you have the older v1.7 TFMini, the current code should function normally and as expected.

Resinchem, 2022-12-02:
This has been fixed with release 0.40.  This new version supports both the older v1.7 version and the newer v1.8.1 release of the TFMini-s.  Note that only the **"-s"** version of the sensor is supported.  It will not work with the base TFMini and has not been tested with the TFMini-plus.

If you've had issues with your system not responding to objects/vehicles, please upgrade to the last version.

Resinchem, 2024-07-08:
Just an update should someone stumble across this.  As of mid-2024, the TFMini-Plus now being sold is a newer v2.0 version.

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

This newer version has been confirmed to work with the later versions of the Parking Assistant firmware (v0.45 and greater).

Closed 2022-12-02.

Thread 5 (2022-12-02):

Installing multiple devices on same network may cause issues

Resinchem, 2022-12-02:
Attempting to install a second (or third) parking assistant on the same network may cause unforeseen issues.  This is due to some hardcoded information related to wifi, OTA updates and MQTT.  For example, a second device will attempt to join your wifi network using the same hostname.  This may or may not cause issues depending upon your particular setup.

In addition, multiple devices with the same MQTT name and topic will overwrite each other's data if MQTT is enabled on more than one device.  Until a fix is released, you may use the following workaround for additional devices.  You will need to download and modify the existing parking_assistant.ino and edit with the Arduino IDE or other compatible editor for this fix.

_You must make these changes and upload to the controller before the first-time onboarding process!_ Some of these values are used during the initial process where you onboard the controller to your wifi.  If you have already onboarded your controller, you will need to perform a full reset and then load the firmware with the changes listed below.

**You do not need to reset or make these changes to your initial or first parking assistant!** These changes ONLY need to be made to any subsequent controllers added after the first one.

At the top of the source code file, locate the following #define statements:

```
#define WIFIHOSTNAME "ESP_ParkAsst"         // Host name for WiFi/Router
#define MQTTCLIENT "parkasst"               // MQTT Client Name
#define OTA_HOSTNAME "ParkAssistOTA"        // Hostname to broadcast as port in the IDE of OTA Updates
#define MQTT_TOPIC_SUB "cmnd/parkasst"      // Default MQTT subscribe topic
#define MQTT_TOPIC_PUB "stat/parkasst"      // Default MQTT publish topic
```
Edit each line to make each value unique.  For example, just add a numeric value for each new device:

```
#define WIFIHOSTNAME "ESP_ParkAsst2"         // Host name for WiFi/Router
#define MQTTCLIENT "parkasst2"               // MQTT Client Name
#define OTA_HOSTNAME "ParkAssistOTA2"        // Hostname to broadcast as port in the IDE of OTA Updates
#define MQTT_TOPIC_SUB "cmnd/parkasst2"      // Default MQTT subscribe topic
#define MQTT_TOPIC_PUB "stat/parkasst2"      // Default MQTT publish topic
```

Save the changes.  You may then either create a new .bin file and upload to the controller following the wiki information [Initial Installation](https://github.com/Resinchem/ESP-Parking-Assistant/wiki/02-Initial-Installation) or uploaded directly from the Arduino IDE via USB cable.

Note that if a new firmware version is released before one containing a fix for this issue, you will need to complete the above steps again using the new .ino version.  It is hoped a fix for this issue will be released soon.

Closed 2022-12-05.

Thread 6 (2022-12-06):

[Feature Request] Side to Side Indicator

tonkaskippers, 2022-12-06:
I’d like to be able to add an additional sensor on the side of the garage so that in a two-car garage.  This makes sure the vehicle doesn't take up the other car's space and is not too close to the wall where it's difficult to open the door.

I think it should have an animation with multiple segments going in the direction that you want the vehicle to move in, would be ideal, kind of like the gif below.  Once the vehicle is in the correct x-axis position, it resumes the regular distance indication.

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

Closed 2022-12-06.

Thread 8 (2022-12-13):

Support HC-SR04

renat2985, 2022-12-13:
I understand that this sensor is worse. But I would still really like to see support for this module in your firmware.
Thanks.

Resinchem, 2022-12-14:
I understand the desire to use the lower cost HC-SR04, but it is not something I currently have the time to develop and support.  It would mean maintaining and updating two different versions of the firmware every time I wanted to make a change or improvement.  However, you or anyone else is free to clone or fork the code and replace the TFMini with the HC-SR04.  It would really just involve removing the TFMini library and related references and changing the distance measuring procedure to get a reading from the HC-SR04 using two GPIO pins.  As long as the code in the main loop is getting a distance reading in mm, it really doesn't care where it comes from... and all the rest of the application, including the LED logic, the web app, OTA updates, etc. should work as-is.

I may consider making an HC-SR04 version available at some point in time, but I certainly am not able to do so at the current time with my existing project load.  So, for now, I'm going to close the issue and mark it as 'won't fix'.  If I time comes that I am able to create a separate version, I will reinstate or recreate the enhancement request.

Closed 2022-12-14.

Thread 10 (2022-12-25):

Board may boot loop if restarted before settings are saved

Resinchem, 2022-12-25:
In some cases, if you reboot the controller after onboarding to wifi, but before going to the web app and saving settings as new boot default, it can cause the board to enter a boot loop.  If this occurs, it will be necessary to re-flash the firmware via USB.  **A fix is in currently in progress**.

In the meantime, just assure that immediately after onboarding your device to wifi you go to the web app and enter some starting values and check the box to save the settings as boot defaults and update.

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

This will create the initial configuration file and prevent the boot loop from possibly occurring.  You can return to the web app and make as many additional changes as you like... just as long as an initial file is created before the first reboot of the device.

Resinchem, 2022-12-26:
Issue should be resolved with release v0.43.  Default starting values are now provided for all config settings in the event the config file isn't present at boot tome.

Closed 2022-12-26.

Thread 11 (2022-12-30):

no distance measurement

n1kDon, 2022-12-30:
Hi thank you for your great project. I have a test build with a wemos d1 mini but the led strip is not leaving stand by mode. I tested changing the parking distances but no difference. In mqtt there is always "cardetected = 0", "parkdistance = 5080.0" . I tested my tfmini-s with another esp32 and that code (https://github.com/ibrahimqazi/TFmini-S-interfacing-with-ESP32) and I get good readings. How can I debug it and check if the tfmini is detected?

Resinchem, 2022-12-30:
The parkdistance of 5080 means that the sensor is not returning a valid reading.  Are you running the latest version of the firmware?  Earlier versions did have an issue with the latest revision of the TFMini-s, but that has been fixed starting with release 0.40.  If you have a TFMini-s with a board number of v1.8.1 and are running a version of the firmware prior to 0.40, you won't get a distance reading (see the [0.40 Release Notes](https://github.com/Resinchem/ESP-Parking-Assistant/releases/tag/v0.40) for details).

Have you followed the [troubleshooting steps](https://github.com/Resinchem/ESP-Parking-Assistant/wiki/10-Troubleshooting) list in the wiki?  The latest firmware has been confirmed to work with the current version of the TFMini-s by multiple people, so I don't believe this is a firmware issue.

n1kDon, 2022-12-30:
So I changed anything including the esp and no luck. So I remembered that I had a similar problem with tx/rx on another project and I found an old wemos d1 mini and now its working. I think there is a problem with some batches of the V 3.0 version of the "wemos" d1 mini. Thank you for your help.

Resinchem, 2022-12-30:
Great!  Glad you got it working.  Thanks for posting the follow-up, as I was not aware of the issue with some D1 Minis, and maybe this can help someone else.  And thanks for closing the issue as resolved.

Closed 2022-12-30.

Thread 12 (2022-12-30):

change minimum detection to 0.1m instead of 0.3m

n1kDon, 2022-12-30:
The minimum detection range of the TFMini-S is 0.1m not 0.3m, I tested it with TFMini-S version 1.81.
See https://cdn.sparkfun.com/assets/8/a/f/a/c/16977-TFMini-S_-_Micro_LiDAR_Module-Product_Manual.pdf
page 7. Perhaps you could consider changing that and add a disclaimer that you are not responsible for any damage on the car :)

Resinchem, 2022-12-30:
I will double-check, but I believe the original TFMini-s v1.4 might have had a minimum distance of 300 mm and anything closer than that range still reported as 300 mm.  Seems like that is also what I remember from my testing.. but I do need to verify that.

If that is the case, I likely will not modify the existing firmware for shorter distances.. "disclaimer" or no disclaimer.  If someone has the older version and sets a minimum distance less than the sensor can measure, then they very easily could continue to pull forward, while the sensor is still showing they are 300 mm away.  Of course, you are welcome to modify your own source code and set the minimum distance to anything you want.

Resinchem, 2022-12-31:
Testing has confirmed what I recalled.  While the newer v1.8.1 boards can report shorter distances, I found that the accuracy and stability begins to suffer at less than about 6".  I even got some readings that were less than 1", but they were very unstable and the next reading at the same distance might return something line 2".  Based on that alone, I might consider lowering the minimum distance to 6".

However, with the older v1.4 version, this was not the case.  I confirmed that anything shorter than 11.8" (the published minimum of 300mm), just continued to return 11.8".  This value was consistent whether the true distance was 4", 6," 8" or 10"....  it always returned 11.8".

For this reason, and to avoid maintaining separate versions for the different sensors, I am not going to lower the minimum distance at this time.  However, if you wish to do so yourself (and completely at your own risk), the minimum distance is only enforced on the web settings page.  You can simply take the source code and modify the 'min' value for each of the distance input fields to change the allowable minimum distance values for the system.

Closed 2022-12-31.

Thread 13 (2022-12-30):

Network SSID with special characters won't connect

hemiawd, 2022-12-30:
Ran into issue, network name is NETWORK-2.4G and fails to connect. Using network SSID NETWORK-GUEST and it connects.

I suspect there is a problem handling the "." character in the network name. With tons of devices, changing the network SSID is not possible. Thanks for looking into this

Resinchem, 2022-12-30:
I suspect this is an issue within the WifiManager library, as that is what handles the onboarding process and the binding to the wifi... I don't actually do anything with the SSID/password in my code.  There do seem to be a couple of similar reported issues within that repository:  [Issue 804](https://github.com/tzapu/WiFiManager/issues/804) and [Issue 906](https://github.com/tzapu/WiFiManager/issues/906).  One is still open and the other has been closed, but I don't see that the problem was specifically fixed.

There have been numerous releases after the one I am currently using, but all are either beta or release-candidates, with no stable/production versions and there are little to no details as to what each new release addresses.  I'm using the latest version before it requires a change from LittleFS to SPIFFS, which is likely to have a major impact on how I'm storing all the other settings.

I'll leave this issue open and continue to investigate, but there is probably little I can do until the underlying WifiManager library is updated to support special characters in its parameters.

hemiawd, 2022-12-31:
Thanks. We did further testing and I have not looked at the code yet, but appears to be a length issue. Network name shows correctly but failed to connect to 12 and 13 character SSID with and without special characters. We were able to quickly connect to 6 character SSID and might be more accurate description of the bug.

Resinchem, 2022-12-31:
Interesting!  I greatly appreciate your assistance in trying to find the cause/solution.  I've spent some time looking at the WifiManager repo, but to be honest, I'm still relatively new to the Arduino/C++ scene.  I looked at all the various posted issues, but It didn't take me long to pretty much get lost looking at their code.  So, you were able to connect to shorter SSIDs that did contain special characters?  If so, then you are right and I will change the issue description to say "longer SSIDs" instead of special characters... or make it both if the shorter SSIDs have problems with the special characters as well.

hemiawd, 2023-01-17:
I installed as a "gift" so unable to do more testing. The 6 char SSID did not have special characters, we had created a 12 char removing the special was unable to connect leading me to test SSID length as it had worked beautifully in the workshop with a shorter SSID.

Building a second and will do more extensive testing to answer the remaining questions. I'll also take a look at the code.

Resinchem, 2023-01-18:
Thanks for the additional testing.  This may in no way be related, but I'm going to add it here for now as something else to consider.  Another user was having connectivity problems... the device would connect the first time, but fail to reconnect on additional attempts (wifimanager.autoconnect returning false).  Here is the info he shared with me regarding what he found:

> I did notice that in the internal wifimanager SSID setup page,  it shows "Authentication Error" after setting up the timeout using the Asus RT-AX86S (although the device is in the Asus device table).  So, I got out my old Asus RT-AC68P router and made a Petrie Dish SSID sub net, and the Wemos D1 connects perfectly and immediately every time

So, at least in his case, it was an issue with a particular router... and obviously something I couldn't duplicate.  Again, might be a completely separate issue, but it does appear that there are some connectivity issues with at least this router... and the same source code connects perfectly with a different router.
.

Closed 2024-01-02.

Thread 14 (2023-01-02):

LEDs will not respond

balucanb, 2023-01-02:
So I followed @Resinchem video, instructions used the items from his list to build the board, Board powers, may not be an issue but the board led only flashes once on boot and does not remain on, but the software flashed fine, I can see the tf mini is powered as I see the red lights inside it, I am connected to my wifi even though the SSID is long ( im-under-your-bed) I see the parkasst on my network, I can go to the set up page and get no errors when saving options, I have tested and they are getting 5v. But not matter what I do I can not get any leds ( Im using 30 leds) to work? Any clue what may be going on and or any help is appreciated. Iattached pic of the board if that helps
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

Resinchem, 2023-01-02:
If you are getting to the settings page and are able to save the settings... and can see the parking assistant device on your network, then everything is fine with the firmware.  Have you tried following the [troubleshooting steps](https://github.com/Resinchem/ESP-Parking-Assistant/wiki/10-Troubleshooting) as shown in the wiki?  There is a whole section about the LEDs not responding.

But in short, if you are reaching the web settings page, it is generally one of two things... the LED strip is not wired correctly (or not getting a good signal) or the distance sensor is not returning a valid distance reading.  If you are not seeing the boot sequence on the LEDs, then it is likely the LED wiring.  If you see the LED boot sequence but then the LEDs do not come on after that, it is probably the distance sensor.

Also, please assure you are running the latest release of the firmware.  Early versions did have issue with the new versions of the TFMini board, but this has been resolved.

balucanb, 2023-01-02:
Leaving this here for anyone else that might have the same issue. CHECK your connections, then check them again..and one more time! After pulling out the multimeter there was 1 solder joint that appeared to be good be view but it wasn't. After a quick addition of a little solder ALL was good. :)

Closed 2023-01-02.

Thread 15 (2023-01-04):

Upgrade from .42 to .43 lost all settings

withanhdammit, 2023-01-04:
This is mostly just for a heads up.  I upgraded from .42 (original install) to .43 and all settings were lost.  I had to re-set up the wifi access, LED count, distances, etc.

Not sure if there were any other similar reported issues.  I wanted to log this because the notes said I should not have lost my settings.

n1kDon, 2023-02-10:
Had the same problem.

balucanb, 2023-02-11:
SAME

Resinchem, 2023-02-12:
I can't find any reason why this should be happening as the only change in this upgrade was to add default values to the local variables when the values are read from flash, in the event the values do not yet exist in flash.  I've also been unable to replicate the issue on three different systems.  Can anyone experiencing the issue let me know what ESP board they are using?  Again, I don't know why this would have any impact, but I'm just looking for why it appears to happen in some cases, but not in others.

Any additional information you can provide, other than "me too", would be helpful in trying to actually to determine a cause.  In addition to the ESP board you are using, confirming both the old version and the new version involved in the upgrade would be helpful.

However, since it does appear to be happening in some instances, I will add the possibility to the release notes and that you should always record your settings before an upgrade.  I also do not believe this problem will happen or reoccur when upgrading from 0.43 to the latest 0.44 as this upgrade has nothing to do with the values stored in flash nor how they are read.
 But it might happen when upgrading from anything prior to 0.43 to 0.44.

n1kDon, 2023-02-12:
Updated from 0.43 to 0.44 and the configuration including wifi credentials was gone. Board: wemos d1 mini clone.

balucanb, 2023-02-12:
Here is the board I am using.  I had quite a bit of trouble when I went to the newest version. To be fair it could Have been user error, always a consideration. I tried the OTA first then when it came back up it was like it was a new install, another issue was it would no longer connect to the WiFi SSID that I had been using previously. After looking around I saw where others had posted similar issues. Long story short it took me about 5 hours and several attempts of re installing the firmware thru serial and OTA when I gave up and changed the name of the SSID and it worked.
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

Resinchem, 2024-02-16:
I believe I _finally_ found the issue as to why this was occurring in some situations.  A fix is implemented in the v0.46 release.  After upgrading to this version, loss of settings should not occur on future firmware upgrades.  Of course if you experienced it before, it may happen one last time when upgrading to v0.46  as the fix won't be present until after the upgrade.

Closed 2024-01-02.

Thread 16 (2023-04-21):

ESP in AP mode

jajen1977, 2023-04-21:
Why is the esp in AP open wifi mode all the time? Anyone can connect and hack this.

Resinchem, 2023-04-21:
Do you have special characters in your SSID or password?  If so, then it is probably related to this issue #13.  However, I am not the developer or maintainer of the ESP8266 wifi library.  If this is your issue, you should post the issue to their Github repo.

I've had no issue with multiple ESP8266 type boards and multiple builds with the ESP remaining in AP mode after entering in the proper wifi credentials as part of the [first time setup steps](https://github.com/Resinchem/ESP-Parking-Assistant/wiki/03-First-Time-Setup)

jajen1977, 2023-04-21:
No, I don't have special characters in SSID / password

Resinchem, 2023-04-21:
I'm happy to try to help, but I need more information before I'm able to assist.  The AP hotspot should ONLY be broadcast when it cannot connect to your local wifi... that is clearly stated in the code here:

```  //fetches ssid and pass and tries to connect
  //if it does not connect it starts an access point with the specified name "ESP_ParkingAsst"
  //If not supplied, will use ESP + last 7 digits of MAC
  //and goes into a blocking loop awaiting configuration. If a password
  //is desired for the AP, add it after the AP name (e.g. autoConnect("MyApName", "12345678")
  if (!wifiManager.autoConnect("ESP_ParkingAsst")) {  //
```
If you are seeing the AP being broadcast, then that means it is not connecting to your wifi and that is a different troubleshooting process.  If that is the case, then I'd need to know what you tried, if you are seeing the MAC or IP address appear in your router at all, what router you are using, whether you've tried moving the controller closer to the router/wireless access point, etc.

Again, the local AP/hotspot is only broadcast on initial setup and then only if it fails to connect to wifi.  If you are truly concerned about this open access point being "hackable", then you can simply add your own password to the hotspot here: ```wifiManager.autoConnect("ESP_ParkingAsst", "mypassword")```
as it is clearly stated within the code comments.  I also just verified three different installations and none of these are broadcasting the "open AP" since they are joined to my wifi.  So you need to first look at any issues with the controller joining your wifi before stating that the AP is always open... it is not if you are joined to wifi.

jajen1977, 2023-04-21:
I am connected to wifi all the time. The signal is strong and stable. Im seeing the IP, MAC, mqtt works fine. But at the same time esp is broadcasting SSID "ESP-66E3C2" I don't understand it but it is like this all the time. Tomorrow I will try to factory reset and I will set up everything again. Maybe it will help.

Resinchem, 2023-04-21:
Well... any possibility that you have another ESP device running somewhere?  The AP hotspot for the Parking Assistant is "ESP_ParkingAsst" and not ESP-nnnnnn.  It's not entirely impossible that it would broadcast the ESP and MAC address, but it really shouldn't.   And even it if did for some reason, that AP should go away once it has joined wifi.

Can you try this?  Join this ESP-66E2C2 wifi on your phone and open a browser and go to 192.168.4.1.  Does it say "ESP_ParkingAsst" under the WifiManager heading... and do you see an input field for UniqueDeviceName?  If you don't see these fields, then it is not the Parking Assistant ESP broadcasting the hotspot and some other ESP device.

Please let me know what you find.  I will often see an ESP-nnnnn being broadcast from some ESP I was testing with but never onboarded to my wifi.  Again, I'm not saying it is NOT the parking assistant, but I'm trying to eliminate possibilities.

jajen1977, 2023-04-21:
There is no other esp. It's definitely the same. I know that, because when the assistant's power is turned off, this SSID disappears. Tomorrow I'll connect to ESP-66E2C2 and let you know.

jajen1977, 2023-04-22:
I connected  to ESP-66E2C2  and after entering the address 192.168.4.1 it say "Controller Settings (parkasst)". Now im sure that is park assist esp device.

Resinchem, 2023-04-22:
OK... thanks for checking that.  It is strange if it is truly on your wifi that it is still broadcasting the AP.  Can you try something else?  After powering on the device and seeing the AP appear, enter the IP address of the controller that your router said it has assigned (you said you are seeing the IP address and MAC address in your router, correct?).  If you enter in that IP address, it should bring up the web interface for the parking assistant (for example, mine is 192.168.1.105):
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

If you do get this page, please scroll all the way to the bottom and let me know what it says for 'Current version'.  If you don't get the above page, then try to ping the IP address.
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

If it does not respond to a ping, then it is not actively on your network.  The router may be showing the MAC address (and the leased IP) since it was seen at least once, but that doesn't mean it is currently joined to your wifi.  Please let me know what you find.

Resinchem, 2023-04-22:
Oh... and also let me know what ESP8266 board you are using.  Is it a Wemos D1 Mini or some other ESP board?

jajen1977, 2023-04-22:
IP address and the web interface for the parking assistant responds. MQTT functionality works fine too. I checked it. The only thing that is strange is active openAP mode in the same time. Current version is v0.44 (ESP8266). The device is Wemos D1 Mini.

Resinchem, 2023-04-23:
OK... after repeated reboots of my devices, I actually did get the AP to reappear even though the controller was connected to wifi.  It's not consistent, but I have confirmed that it can occur.  This led me to search the issues from the WifiManager library that I am using and I found this issue:

[Sometimes AP Randomly Comes back on](https://github.com/tzapu/WiFiManager/issues/1220)

This issue has been open for over 2 years... and there may be others listed, but this is the initial one that I found.  I can try to review and see if there is a way that I can force the AP to turn off after a successful connection to wifi, but with other projects and priorities, I can't make any promises as to when I might get the opportunity to develop, test and deploy any changes.

In the interim, if you are overly concerned about "hacking" of this open AP (first note that the ESP8266 wifi is a very weak signal and does not broadcast very far), you can add a password to the AP as I detailed above.

Thanks for providing the additional information that allowed me to track down the issue.

jajen1977, 2023-04-23:
thank you for trying to solve the problem.

tcflint, 2023-10-11:
Resinchem your projects are great.  I had a few questions on this and the battery for mailbox.
Could you DM me to discuss?
Thanks

Resinchem, 2024-02-05:
Fixed with [release v0.45](https://github.com/Resinchem/ESP-Parking-Assistant/releases/tag/v0.45).  Local AP/hotspot no longer continues to broadcast after successfully joining wifi.

Closed 2024-02-05.

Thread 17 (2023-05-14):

Troubleshooting

withanhdammit, 2023-05-14:
Are there any troubleshooting or debugging logs?  I'm having trouble getting this to work.  I had it set up and working on a breadboard, but after assembling, it no longer works.  I have triple checked everything, voltages all read correct, however the LEDs are not illuminating.  LEDs have power down to the end of the strip, I have tested them on a WLED controller and the LEDs are fine.

I also noticed the logic level shifter outputs 3.3v on the data line when the LEDs are connected and 5v when the LEDs are not connected.

I know I need to disconnect the TFmini to read data out of the USB port, but the serial monitor in the Arduino IDE just shows gibberish:
09:51:23.612 -> �rll�r $ �n

�
l�
b|��   �r b�
b �nn lnn2b
b
p�$b lrlp�n�

�
l
�

b
n�n�l
 b��nn'l� l` �  nn
l`   nr���n

b l`  r��n

b l` �b

�l�lr�` ��nb

withanhdammit, 2023-05-14:
Thanks, I do have the baud set at 115,200.  I didn't see 'Discussions' or I would have posted there.  I was pretty certain the firmware was fine.

I think the issue was related to the ESP8266.  I replaced it and it booted and reads correctly now.

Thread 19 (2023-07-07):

Pins for HC-SR04 without logic level shifter

LuxStatera, 2023-07-07:
I have a D1 Mini, LED strip and HC-SR04. I want to make sure I am using the correct pins on the D1 Mini. What pins would you recommend without the logic level shifter? Will everything still work without it?

Resinchem, 2023-07-07:
**This code will not work with the HC-SR04... period.**  The code would have to be substantially modified with different libraries to read the distances from the HC-SR04.   This code will ONLY work with the TF-Mini.  Wiring will not matter.

If you want to use the HC-SR04, I suggest you look at one of the forks of this project that have been rewritten to work with the HC-SR04 and post your wiring questions there as I am not the one supporting those versions.

But I will say that you _might_ get away without the logic level shifter if you keep the controller close to the start of the LED strip.  You may be fine... and you may not if the voltage on the data line drops too low.  This will lead to flickering and other misbehaving of the LEDs.  But you are obviously free to roll the dice and take your chances.  I would highly recommend a bench test with the expected wiring lead length of your final install before creating any final version.

Closed 2023-07-07.

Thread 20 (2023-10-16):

MQTT message after LED change

n1kDon, 2023-10-16:
Hi, thanks for the great project. Its working great, but now to my issue. I bought an old traffic light and wanted to sync it with the parking assistant. I changed the code for my needs but when I compile the esp8266 (d1 mini) is behaving very slow with slow led and website response, **even when I test compile with the original source code**. Tried with different arduino ide and library versions but had no luck. Setting MQTT off for testing doesn't change the behavior. The precompiled version is working normal.
I changed only the Update LEDs part and inserted a new global variable.

```cpp
// Global variable
String prevLEDStatus = "";

// Update LEDs
if ((carDetected) && (isAwake)) {
    String currentLEDStatus = "";  // Variable to store the current LED status

    if (tf_dist <= backupDistance) {
        // Beyond minimum distance - flash backup!
        blinkLEDs(ledColorBackup);
        currentLEDStatus = "backup";

    } else if (tf_dist <= parkDistance) {
        // In desired parked distance
        fill_solid(LEDs, numLEDs, ledColorParked);
        currentLEDStatus = "parked";

    } else if ((tf_dist > startDistance) && (tf_dist <= wakeDistance)) {
        // Beyond start distance but within wake distance
        fill_solid(LEDs, numLEDs, ledColorWake);
        currentLEDStatus = "wake";

    } else if ((tf_dist <= startDistance) && (tf_dist > parkDistance)) {
        // Update based on selected effect
        if (ledEffect_m1 == "Out-In") {
            updateOutIn(tf_dist);
        } else if (ledEffect_m1 == "In-Out") {
            updateInOut(tf_dist);
        } else if (ledEffect_m1 == "Full-Strip") {
            updateFullStrip(tf_dist);
        } else if (ledEffect_m1 == "Full-Strip-Inv") {
            updateFullStripInv(tf_dist);
        } else if (ledEffect_m1 == "Solid") {
            updateSolid(tf_dist);
        }
        currentLEDStatus = "start";
    }

    // Check if the LED status has changed
    if (currentLEDStatus != prevLEDStatus) {
        // If the MQTT client is connected, publish the LED status
        if (client.connected()) {
            String topic = "parkingAssistant/" + mqttTopicPub + "/led_status";
            client.publish(topic.c_str(), currentLEDStatus.c_str());
        }
        // Update the previous LED status with the current status
        prevLEDStatus = currentLEDStatus;
    }
}
```
Has anyone else faced a similar issue or have any insights on what might be causing the slowdown? Any help would be greatly appreciated.

Thank you!

Resinchem, 2023-10-16:
I am by no means an expert when it comes to Arduino, libraries or other detailed options when it comes to creating compiled code.  However, if the precompiled version runs fine and your compiled version is sluggish or isn't working quite right, then it would seem that there is obviously something different in our two environments when compilation occurs.  This may or may not be helpful, but here are the related versions and options I used for the original version:

Arduino IDE 1.8.16
ESP8266 Board 2.7.4

Applicable Library Versions:

WiFiManager.h  2.0.8-beta
FastLED 3.5.0
ArduinoJson 6.18.5
TFMPlus 1.5.0
PubSubClient 2.8.0

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

I don't know if any of that will be helpful or not, but that's about the only thing I can think of if the precompiled bin is fine, but when you compile your own (even with the original source), the response is sluggish.

n1kDon, 2023-10-16:
Thank you for your assistance. The issue has been resolved. Here's what I did:

Downgraded some of the libraries to the versions you used and switched my board from a d1mini clone to the D1 R2 & mini.
With these changes, everything is working smoothly. I can now proceed to test and refine my MQTT setup further.

Resinchem, 2023-10-16:
Great.. glad that resolved it.  I'm going to go ahead and mark as 'resolved' and close the issue.

Closed 2023-10-16.

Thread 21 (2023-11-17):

Parking Asst drops wifi

withanhdammit, 2023-11-17:
I recently noticed a strange ESP-xxxxxxx hotspot being broadcast, so I connected to it and was surprised to discover it was my Parking Assistant.  It's been working fine all along, so I wasn't aware anything was amiss.  Nothing I did could connect it back to my IOT wireless network.

I reset all settings and it started broadcasting ESP-ParkAssist.  I joined that and reconnected it to my IOT wireless network.  It then came up correctly.  I added the config (distances/colors) and saved, it's working fine again.  I rebooted it a couple times, still good to go.

However, I also want this connected to my Home Assistant, so I input my MQTT broker (IP address, port, username, password, devicename (no special characters just 'parkmazda')) and when it saved/rebooted it dropped off my IOT wireless network again, and started broadcasting the ESP-xxxxxxx hotspot again.  When I connect to that hotspot, all the settings are configured, it just will not connect to my IOT wireless network.

I reset all settings again and set it back up without MQTT configured. Not sure if there's a problem with the MQTT or not.  I would really like to use the MQTT topics for Home Assistant, so I'm hoping there's something that can help.  Not sure if there are logs or anything I can grab to investigate.  To be fair, it's never connected to MQTT since I originally built the project, I had given up on it and was reminded again when I noticed it broadcasting the new SSID.

I am running v.44, This is on a D1-Mini (ESP8266).

withanhdammit, 2023-11-17:
I reflashed the firmware and while the ESP-xxxxxxx is still being broadcast, I see the other issue regarding that, and understand it's a library issue.

I'll open a new issue for my MQTT problem.

Closed 2023-11-17.

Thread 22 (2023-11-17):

MQTT User and Password Fields Limited to 30 characters each

withanhdammit, 2023-11-17:
I think the MQTT password field may be truncating my password.  I don't see anything in the code that would indicate that, and I know Arduino code can handle this length password (64 chars, letters & numbers only, no special chars).  I have another device early in my days of home automation where I built a temperature sensor that was pure MQTT, with the same password and it connects fine and still actively reports.

The Home Assistant MQTT Broker (Mosquitto) is reporting parkasst is not authorized.  I have double checked the password (it's copy/pasted so I know there's no typos.  It is a pretty long password, so maybe the textbox is truncating it?

```
2023-11-17 14:17:13: New connection from 10.42.100.113:52214 on port 1883.
2023-11-17 14:17:13: Client parkasst disconnected, not authorised.
```

withanhdammit, 2023-11-17:
That's fantastic, thank you!

I've been looking through the code and haven't been able to spot where that's limited, so I appreciate you looking!

withanhdammit, 2023-11-18:
I think I found the references (is the 31 for 30 chars plus CR?) I think this would do the trick:
Line 175
```char mqtt_pw[31];```
to
```char mqtt_pw[65];```

Line 765
```  char t_mqtt_pw[31];```
to
```  char t_mqtt_pw[65];```

Line 768
```  int user_pw = 31;```
to
```  int user_pw = 65;```

That should make the password field able to go up to 64 characters (plus CR (presumably))

Resinchem, 2023-11-18:
Yes... those are the variable declarations, but without looking more closely at the code and testing, I'm not sure that just increasing those variable lengths will allow longer entries without causing other issues or errors.  There is also the web page entry sections and where it reads and writes to SPIFFS (e.g using mqttuser, and mqttpw.).  It would be great if it is that simple, but I would need to review all the code, make a test version and upload it to my test system to be sure it doesn't break something else.  I haven't worked on it in a while, so I just can't say right away if other changes may be needed or not.

If you have the ability to compile your own code, you are certainly free to try just changing those values and can let me know if it really is that simple and solves the issue.  Otherwise, I will try to get to it as soon as I get a break in my current project load.

withanhdammit, 2023-11-18:
No worries, I'm happy to make those changes and test the new bin.  I'll let you know how it goes.  Hoping for no magic smoke LOL

withanhdammit, 2023-11-18:
That did the trick!  I called my test version .44a, and I can see the MQTT messages now!
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

Resinchem, 2023-11-18:
Outstanding!  Thanks for trying that and doing the hard work for me!  I'll leave this issue open until I roll those changes out in a new version, but you made the job much easier.

Resinchem, 2023-11-18:
Do you happen to have a Discord account?  I'd like to reach out for a non-related issue.  If you have one and don't want to post it here (you can delete it afterwards if you want... I'll get a copy via email), you can always email me at the account you can find on the 'about' page of my YouTube channel.  If not, no big deal.  Just easier (and more appropriate) to chat there than here or in the comments of YouTube or the blog.

withanhdammit, 2023-11-18:
I did some more work, specifically around getting these into a decent usable state in Home Assistant.

My HA/MQTT config is:
```
mqtt:
  sensor:
    - name: "Park Assist Distance"
      state_topic: "stat/parkmazda/parkdistance"
      unit_of_measurement: "in"
      icon: mdi:ruler
    - name: "Park Assist Car Detected"
      state_topic: "stat/parkmazda/cardetected"
    - name: "Park Assist MQTT Connected"
      state_topic: "stat/parkmazda/mqtt"

binary_sensor:
  - platform: template
    sensors:
      park_assist_car_detected:
        friendly_name: "Park Assist Car Detected"
        value_template: "{{ states('sensor.park_assist_car_detected') == '1' }}"
        icon_template: >-
          {% if is_state('binary_sensor.park_assist_car_detected', 'on') %}
            mdi:car
          {% else %}
            mdi:car-off
          {% endif %}
      park_assist_mqtt_connected:
        friendly_name: "Park Assist MQTT Connected"
        value_template: "{{ states('sensor.park_assist_mqtt_connected') == 'connected' }}"
        icon_template: >-
          {% if is_state('binary_sensor.park_assist_mqtt_connected', 'on') %}
            mdi:wifi
          {% else %}
            mdi:wifi-off
          {% endif %}
```
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

And my Lovelace cards look like this:
```
type: button
entity: binary_sensor.park_assist_car_detected
show_name: true
show_icon: true
tap_action:
  action: none
hold_action:
  action: none

type: button
entity: sensor.park_assist_distance
show_state: true
show_name: true
show_icon: true
tap_action:
  action: none
hold_action:
  action: none

type: button
entity: binary_sensor.park_assist_mqtt_connected
show_name: true
show_icon: true
tap_action:
  action: none
hold_action:
  action: none
```
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

And to go really next level, it would be cool to have the thresholds available via MQTT, then I could code against those, too.  Oh, and the colors, so I could make the distance icon the same color as the thresholds, like if you're in the too far zone the icon is red, distance thresholds pulled from MQTT, if you're in the just right zone the color is green, and if you're in the too close zone the color is red.  Or something along those lines.  But future state :-D

withanhdammit, 2023-11-18:
> Do you happen to have a Discord account? I'd like to reach out for a non-related issue.

I am on discord as 'withanHdammit'

Resinchem, 2024-02-05:
Fixed with release v0.45.  MQTT User Name and Password can now be up to 64 characters each.

Closed 2024-02-05.

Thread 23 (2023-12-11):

MQTT

marcelk1101, 2023-12-11:
Hello,
thanks for this great idea and development.

I want to know if its possible to get more datapoints on mqtt? I need the state of the leds and the distance. So it would be possible to generate an "live" view.

Would it be possible to update the firmware with wifi?

Thank you very much!

Resinchem, 2023-12-11:
I'm not sure what you are looking for with MQTT.  I understand that you want updates more often, but distance is already included in the MQTT topics published... as is whether a car is detected or not.

The same with WiFi.  What are you referring to?  The firmware has WiFi enabled by default and is how you access the web/settings.  It also supports over-the-air firmware updates via WiFi.

As far as changing the frequency of MQTT updates, it will update at least once a minute if you set it at the minimum telemetry time in the settings (60 seconds).  I will also update any time the car "state" changes... e.g. goes from no car detected to car detected (or vice versa).  When the car is just sitting parked (or isn't present), I'm not sure why you would need the distance to be rapidly updated at a more frequent rate.  The same with the LEDs.  I simply saw no reason to flood the MQTT broker with messages when nothing was really changing.  But you may have particular reasons.

I'll mark this as an enhancement request, but to be completely honest, I don't know if or when I may get around to it and would need to have a little better justification and explanation as to what you are really looking for (and why) before I'd consider adding it.

marcelk1101, 2023-12-13:
Hello,

thank you for your explanation. After I changed the adapter, 3 data points were visible. (Car detected, distance) This is exactly what I need, so it was my mistake.

Now an optimization would be desirable. If you had another data point using MQTT to put the Wemos in standby. So that the lidar sensor is not constantly on. I would connect it to my garage door, i.e. when the door opens the chip is woken up. Is this possible?

Thank you

Resinchem, 2023-12-13:
While you can certainly make something like that work, it won't be something that I will pursue.  The TFMini Plus lists an average power draw of 550 mW.  That's 0.00055 kW.  Running 24/7 for an entire year would consume about 12 kWh.  And at least here in Indiana, the cost per kWh is $0.15.  That means the cost to run the lidar sensor continuously for an entire year would be about $1.80.  Even adding in the D1 Mini and the standby lights on the LEDs (which can be toggled off in the settings if desired), the cost of the system in standby mode would probably top out at about $3.00-$4.00/year.  It's honestly not worth my time to spend hours rewriting and testing the code to save $4.00 over the course of a year.

Plus if you are going to wake the system with something like the garage door, note that it takes the system anywhere from 15-45 seconds to boot up (depending on how quick the system can join your WiFi, MQTT broker, etc.).  This means the system will not respond to an approaching car until this boot process completes and possibly leaving the driver approaching the parked location with no feedback from the system... unless they want to sit in the driveway waiting for the system to finish booting.

Again, you are free to fork or clone my code and make these changes yourself.  For me, it isn't something I see as worthwhile for my own purposes.

marcelk1101, 2023-12-16:
Hello,

I would like to thank you very much for the detailed and understandable answer.

However, I still have one question.

We have developed a visualization for the iobroker in our community, similar to Home Assistant. Unfortunately, the data is only updated every 60 seconds, so real-time display is unfortunately not possible. According to your description it is probably the ESP8266. Are there plans to improve this, for example with an ESP32?

I would be very interested.
I would like to thank you in advance and wish you a pleasant Christmas season.

Best Regards, Marcel

Resinchem, 2023-12-16:
Well, technically the limitation isn't due to the ESP8266 or even the MQTT broker.  But in my case, I have a lot of MQTT devices that probably publish well over a hundred MQTT messages.  In addition, each change to a sensor or value also gets recorded in the Home Assistant log files.  Having a device that publishes messages every 1 or 2 seconds would just unnecessarily tax the broker and bloat the Home Assistant log.  So, for this device, I imposed a 60 second limit due to what I considered "normal" usage.

But both the ESP8266 and MQTT broker could certainly handle an MQTT message at shorter intervals... like once a second.  And if you wanted to change it for this particular app, there are only two minor changes that need to be made.  There is a variable called mqttTelePeriod that is set to 60 seconds by default.  Then where the web page is generated, there is a check that doesn't allow a value of less than 60 to be entered.  You could just change these two values and remove the minimum 60 second limit.

I don't have any plans to develop a version for the ESP32.  Again, the ESP8266 is quite capable of handling the load for the current parking system as it is designed.

marcelk1101, 2023-12-17:
Perfect, I will test soon. Do you think its possible to Update with OTA, or do I have to write the changed firmware manualy with flashing tool?

Closed 2023-12-13.

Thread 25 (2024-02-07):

Power problem with my build

Ourbudd, 2024-02-07:
1st off Thanks for this build lesson. This is my 1st Arduino project and it has been a nice project with great instructions.

I have built the unit just like you said with the parts you suggested. I am having one problem and haven't figured out what is causing it. When I boot it up on the power supply it generally does not do anything, I checked voltages on both sides and they right in line. After testing numerous times it came on and worked fine but after disconnecting power and trying again I couldn't get it to work again. The light blinks but occasionally and random amounts from what I can tell. I looked the board over with a scope and don't see any issues but not sure what is causing the problem. Then when I was testing trying to figure it out I disconnected the power supply and connected it to a battery pack with a micro USB and it came on and worked, every time I tried it? I then tried back and forth between the 2 different power sources and one more time it worked on the power supply after about a minute or so but most of the time it doesn't. I checked voltages on both rails on both power supplies and they are very similar 3.3 and 5, I also took voltage readings on the logic level shifter and most seemed good but on LU4 when on the battery source I get 0.25 to 0.65 V and when on the wall power supply it gives me about 3.3 V, I tried many times and it is basically the same. When the unit did work on the wall power supply the voltage was low like on the battery. I tried moving things around and looking deeper with the digital scope but can't fine the problem. Any help is appreciated and being new I am sure some of this could have been said better. I will attach pictures of the board connections. Thanks,   Tim
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

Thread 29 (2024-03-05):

Compille Issue Caused By pixeltypes.h:7,controller.h:9,FastLED.h:57, & noise.cpp:6:

ylnest2018, 2024-03-05:
Not sure if it's just me, but I get these compile errors on my Firebeetle 2.

I read something online where people talk about downgrading the board to v2.X because v3.X broke the FastLED compatibility, but curious if anyone else has this issue and/or knows how to fix it.

I tried to just comment out all the FastLED code to see if i could proceed but it's pretty ingrained in this amazing project so I dont want to butcher it

`Users/leo/Documents/Arduino/libraries/FastLED/src/noise.cpp: In function 'void fill_raw_2dnoise8(uint8_t*, int, int, uint8_t, q44, fract8, int, uint16_t, int, uint16_t, int, uint16_t)': /Users/leo/Documents/Arduino/libraries/FastLED/src/noise.cpp:623:100: error: ambiguous overload for 'operator*' (operand types are 'q44' {aka 'q<unsigned char, 4, 4>'} and 'int') 623 |     fill_raw_2dnoise8(pData, width, height, octaves-1, freq44, amplitude, skip+1, x*freq44, freq44 * scalex, y*freq44, freq44 * scaley, time); |                                                                                             ~~~~~~ ^ ~~~~~~ |                                                                                             |        | |                                                                                             |        int |                                                                                             q44 {aka q<unsigned char, 4, 4>} In file included from /Users/leo/Documents/Arduino/libraries/FastLED/src/pixeltypes.h:7, from /Users/leo/Documents/Arduino/libraries/FastLED/src/controller.h:9, from /Users/leo/Documents/Arduino/libraries/FastLED/src/FastLED.h:57, from /Users/leo/Documents/Arduino/libraries/FastLED/src/noise.cpp:6: /Users/leo/Documents/Arduino/libraries/FastLED/src/lib8tion.h:909:14: note: candidate: 'uint32_t q<T, F, I>::operator*(uint32_t) [with T = unsigned char; int F = 4; int I = 4; uint32_t = long unsigned int]' 909 |     uint32_t operator*(uint32_t v) { return (v*i) + ((v*f)>>F); } |              ^~~~~~~~ /Users/leo/Documents/Arduino/libraries/FastLED/src/lib8tion.h:911:14: note: candidate: 'uint16_t q<T, F, I>::operator*(uint16_t) [with T = unsigned char; int F = 4; int I = 4; uint16_t = short unsigned int]' 911 |     uint16_t operator*(uint16_t v) { return (v*i) + ((v*f)>>F); } |              ^~~~~~~~ /Users/leo/Documents/Arduino/libraries/FastLED/src/lib8tion.h:913:13: note: candidate: 'int32_t q<T, F, I>::operator*(int32_t) [with T = unsigned char; int F = 4; int I = 4; int32_t = long int]' 913 |     int32_t operator*(int32_t v) { return (v*i) + ((v*f)>>F); } |             ^~~~~~~~ /Users/leo/Documents/Arduino/libraries/FastLED/src/lib8tion.h:915:13: note: candidate: 'int16_t q<T, F, I>::operator*(int16_t) [with T = unsigned char; int F = 4; int I = 4; int16_t = short int]' 915 |     int16_t operator*(int16_t v) { return (v*i) + ((v*f)>>F); } |             ^~~~~~~~ /Users/leo/Documents/Arduino/libraries/FastLED/src/noise.cpp:623:127: error: ambiguous overload for 'operator*' (operand types are 'q44' {aka 'q<unsigned char, 4, 4>'} and 'int') 623 |     fill_raw_2dnoise8(pData, width, height, octaves-1, freq44, amplitude, skip+1, x*freq44, freq44 * scalex, y*freq44, freq44 * scaley, time); |                                                                                                                        ~~~~~~ ^ ~~~~~~ |                                                                                                                        |        | |                                                                                                                        |        int |                                                                                                                        q44 {aka q<unsigned char, 4, 4>} /Users/leo/Documents/Arduino/libraries/FastLED/src/lib8tion.h:909:14: note: candidate: 'uint32_t q<T, F, I>::operator*(uint32_t) [with T = unsigned char; int F = 4; int I = 4; uint32_t = long unsigned int]' 909 |     uint32_t operator*(uint32_t v) { return (v*i) + ((v*f)>>F); } |              ^~~~~~~~ /Users/leo/Documents/Arduino/libraries/FastLED/src/lib8tion.h:911:14: note: candidate: 'uint16_t q<T, F, I>::operator*(uint16_t) [with T = unsigned char; int F = 4; int I = 4; uint16_t = short unsigned int]' 911 |     uint16_t operator*(uint16_t v) { return (v*i) + ((v*f)>>F); } |              ^~~~~~~~ /Users/leo/Documents/Arduino/libraries/FastLED/src/lib8tion.h:913:13: note: candidate: 'int32_t q<T, F, I>::operator*(int32_t) [with T = unsigned char; int F = 4; int I = 4; int32_t = long int]' 913 |     int32_t operator*(int32_t v) { return (v*i) + ((v*f)>>F); } |             ^~~~~~~~ /Users/leo/Documents/Arduino/libraries/FastLED/src/lib8tion.h:915:13: note: candidate: 'int16_t q<T, F, I>::operator*(int16_t) [with T = unsigned char; int F = 4; int I = 4; int16_t = short int]' 915 |     int16_t operator*(int16_t v) { return (v*i) + ((v*f)>>F); } |             ^~~~~~~~ /Users/leo/Documents/Arduino/libraries/FastLED/src/noise.cpp: In function 'void fill_raw_2dnoise16(uint16_t*, int, int, uint8_t, q88, fract16, int, uint32_t, int, uint32_t, int, uint32_t)': /Users/leo/Documents/Arduino/libraries/FastLED/src/noise.cpp:661:101: error: ambiguous overload for 'operator*' (operand types are 'int' and 'q88' {aka 'q<short unsigned int, 8, 8>'}) 661 |     fill_raw_2dnoise16(pData, width, height, octaves-1, freq88, amplitude, skip, x *freq88 , scalex *freq88, y * freq88, scaley * freq88, time); |                                                                                              ~~~~~~ ^~~~~~~ |                                                                                              |       | |                                                                                              int     q88 {aka q<short unsigned int, 8, 8>} /Users/leo/Documents/Arduino/libraries/FastLED/src/lib8tion.h:922:49: note: candidate: 'uint32_t operator*(uint32_t, q<T, F, I>&) [with T = short unsigned int; int F = 8; int I = 8; uint32_t = long unsigned int]' 922 | template<class T, int F, int I> static uint32_t operator*(uint32_t v, q<T,F,I> & q) { return q * v; } |                                                 ^~~~~~~~ /Users/leo/Documents/Arduino/libraries/FastLED/src/lib8tion.h:923:49: note: candidate: 'uint16_t operator*(uint16_t, q<T, F, I>&) [with T = short unsigned int; int F = 8; int I = 8; uint16_t = short unsigned int]' 923 | template<class T, int F, int I> static uint16_t operator*(uint16_t v, q<T,F,I> & q) { return q * v; } |                                                 ^~~~~~~~ /Users/leo/Documents/Arduino/libraries/FastLED/src/lib8tion.h:924:48: note: candidate: 'int32_t operator*(int32_t, q<T, F, I>&) [with T = short unsigned int; int F = 8; int I = 8; int32_t = long int]' 924 | template<class T, int F, int I> static int32_t operator*(int32_t v, q<T,F,I> & q) { return q * v; } |                                                ^~~~~~~~ /Users/leo/Documents/Arduino/libraries/FastLED/src/lib8tion.h:925:48: note: candidate: 'int16_t operator*(int16_t, q<T, F, I>&) [with T = short unsigned int; int F = 8; int I = 8; int16_t = short int]' 925 | template<class T, int F, int I> static int16_t operator*(int16_t v, q<T,F,I> & q) { return q * v; } |                                                ^~~~~~~~ /Users/leo/Documents/Arduino/libraries/FastLED/src/noise.cpp:661:129: error: ambiguous overload for 'operator*' (operand types are 'int' and 'q88' {aka 'q<short unsigned int, 8, 8>'}) 661 |     fill_raw_2dnoise16(pData, width, height, octaves-1, freq88, amplitude, skip, x *freq88 , scalex *freq88, y * freq88, scaley * freq88, time); |                                                                                                                          ~~~~~~ ^ ~~~~~~ |                                                                                                                          |        | |                                                                                                                          int      q88 {aka q<short unsigned int, 8, 8>} /Users/leo/Documents/Arduino/libraries/FastLED/src/lib8tion.h:922:49: note: candidate: 'uint32_t operator*(uint32_t, q<T, F, I>&) [with T = short unsigned int; int F = 8; int I = 8; uint32_t = long unsigned int]' 922 | template<class T, int F, int I> static uint32_t operator*(uint32_t v, q<T,F,I> & q) { return q * v; } |                                                 ^~~~~~~~ /Users/leo/Documents/Arduino/libraries/FastLED/src/lib8tion.h:923:49: note: candidate: 'uint16_t operator*(uint16_t, q<T, F, I>&) [with T = short unsigned int; int F = 8; int I = 8; uint16_t = short unsigned int]' 923 | template<class T, int F, int I> static uint16_t operator*(uint16_t v, q<T,F,I> & q) { return q * v; } |                                                 ^~~~~~~~ /Users/leo/Documents/Arduino/libraries/FastLED/src/lib8tion.h:924:48: note: candidate: 'int32_t operator*(int32_t, q<T, F, I>&) [with T = short unsigned int; int F = 8; int I = 8; int32_t = long int]' 924 | template<class T, int F, int I> static int32_t operator*(int32_t v, q<T,F,I> & q) { return q * v; } |                                                ^~~~~~~~ /Users/leo/Documents/Arduino/libraries/FastLED/src/lib8tion.h:925:48: note: candidate: 'int16_t operator*(int16_t, q<T, F, I>&) [with T = short unsigned int; int F = 8; int I = 8; int16_t = short int]' 925 | template<class T, int F, int I> static int16_t operator*(int16_t v, q<T,F,I> & q) { return q * v; } |                                                ^~~~~~~~ /Users/leo/Documents/Arduino/libraries/FastLED/src/noise.cpp: In function 'void fill_raw_2dnoise16into8(uint8_t*, int, int, uint8_t, q44, fract8, int, uint32_t, int, uint32_t, int, uint32_t)': /Users/leo/Documents/Arduino/libraries/FastLED/src/noise.cpp:699:106: error: ambiguous overload for 'operator*' (operand types are 'int' and 'q44' {aka 'q<unsigned char, 4, 4>'}) 699 |     fill_raw_2dnoise16into8(pData, width, height, octaves-1, freq44, amplitude, skip+1, x*freq44, scalex *freq44, y*freq44, scaley * freq44, time); |                                                                                                   ~~~~~~ ^~~~~~~ |                                                                                                   |       | |                                                                                                   int     q44 {aka q<unsigned char, 4, 4>} /Users/leo/Documents/Arduino/libraries/FastLED/src/lib8tion.h:922:49: note: candidate: 'uint32_t operator*(uint32_t, q<T, F, I>&) [with T = unsigned char; int F = 4; int I = 4; uint32_t = long unsigned int]' 922 | template<class T, int F, int I> static uint32_t operator*(uint32_t v, q<T,F,I> & q) { return q * v; } |                                                 ^~~~~~~~ /Users/leo/Documents/Arduino/libraries/FastLED/src/lib8tion.h:923:49: note: candidate: 'uint16_t operator*(uint16_t, q<T, F, I>&) [with T = unsigned char; int F = 4; int I = 4;
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
Resinchem, 2024-03-05:
This definitely looks like a FastLED issue, but I'm unable to test or confirm.  As mentioned in the wiki, this project was developed with, and for, a Wemos D1 mini but should work with most other NodeMCU-style ESP8266 boards. Other board types may require modification to the code or libraries.

I'll leave this issue open for a bit to see if anyone else has any info on the Firebeetles, but due to the large number and types of ESP8266 boards, it is simply impractical for me to be able to test and verify my code on every variant.

ylnest2018, 2024-03-05:
im offended by the label you gave 🤣

Anyway, I have since learnt the FastLED package can have issues with the latest ESP board version 3.0.0a and the solution is to downagrade in Arduino IDE to 2.0.14

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

Might help someone else if they get stuck :)

Closed 2024-03-05.

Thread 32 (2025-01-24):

Welcome to ESP-Parking-Assistant Discussions!

Bjeff895, 2025-01-24:
### Discussed in https://github.com/Resinchem/ESP-Parking-Assistant/discussions/18

<div type='discussions-op-text'>

<sup>Originally posted by **Resinchem** May 14, 2023</sup>
## Welcome!
  Please use discussions for the following:
  * Ask questions you’re wondering about.
  * Troubleshoot your installation
  * Share ideas.
  * Engage with other community members.

</div>just a question, have done the wiring, down loaded the software, got the hotspot working, set up the wifi, it says saved but after this it will not connect to wifi. It gives me a can’t connect to AP. I’ve tried several times time but still no success.
Even tried the earlier suggestion about setting 2.4/5gig on my router  bye forcing it to use another network but to no avail. Not sure if you can

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

help since may be out of this discussion, but if you could direct me to areas or ideas as how I could fix this I would appreciate the help. Used d1 mini, ws2812b leds, logic level shifter, tf mini-s. Sending three pics if they help.
Thanks
Barry Jefferies

Resinchem, 2025-01-24:
Is that a v4 of the D1-Mini with a USB-C connection instead of a microUSB connection?  From the photo, it looks as if it is.

There is known issue with the board and I'm not sure if/when I'll be able to diagnose further and repair.  See issue #31. In the interim, I recommend a D1 mini that uses a microUSB connection.

Bjeff895, 2025-01-24:
Thank you for your quick response, the chip has a micro usb connector but I bought it from Amazon in Canada so not sure of version number. Maybe I’ll try to get on from US Amazon. Thanks for your trouble I’ll carry on and report back.
Barry

Resinchem, 2025-01-24:
Sorry if I assumed it had the USB-C port.  I've just never seen a D1 Mini like that (square corners on the PCB vs. rounded or angled).

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

This doesn't necessarily mean anything is "wrong" with your D1 Mini, but I've run into boards by some sellers that use lower cost components on the board (e.g. different voltage regulator, different USB-to-Serial chip, etc.).  Occasionally, I'll get a hold of one that doesn't want to play nice... I even had a batch that wouldn't even flash.

If you are going to try ordering new boards, I'd try a completely different seller and see if you can find one that more closely matches the one above.  I know you said you were in Canada, but for comparison, here's the link to the D1 Minis I normally purchase from U.S. Amazon if it helps out for comparison purposes:  [Wemos D1 Mini](https://amzn.to/4hsceN8)

And please let me know what you do find so I can update the info here and in the general documentation if needed.

Bjeff895, 2025-01-28:
Just received my new d1 mini and rewired it into circuit and nothing has changed, " AP not found." Any further thoughts or do i have a router problem?

Resinchem, 2025-01-28:
I'm at a bit of a loss.  There was an issue reported quite some time ago that was related to the WiFi/onboarding library that I'm using.  Apparently, it has some issues with special characters in the SSID and password.  Now, it looks like you only have an underscore and a dash, so I don't _think_ that's an issue.  But if you have special characters in the password, that could also be the cause.  But you can easily verify if this is the case if you have the ability to spin up a secondary SSID on your network.  If you can at least temporarily create a simple SSID and password that only consists of letters and numbers, then you can try joining the controller to this test SSID.  If it joins, then we know its an issue with something in the SSID and/or password.

FYI... I'm in the slow process of going back an updating many of these old projects, replacing the external onboarding library with one that I developed myself (and doesn't have the SSID/PW issues).  Along the way, I'm making a number of other standard improvements, updating the libraries and boards to the latest versions, etc.  This being one of my more popular projects, it is high on the list.  But I can't say for sure when I'll get to it.  If are able to determine that it is an issue with your SSID/PW, then the options are to use a different SSID, change and remove special characters from your existing WiFi or simply wait until I get around to an updated version.

But if you are able to try joining a different WiFi network without any special characters in either the SSID or password, please let me know what you find.

Bjeff895, 2025-01-28:
I have wled on my network and it connects fine, also the password for this
project is only lowercase letters and 4 numbers. I'll keep trying
different ideas and if I come up with any thoughts I will report back to
you .
thanks again

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

Resinchem, 2025-01-29:
I appreciate it.   WLED is definitely using a different onboarding process (assuming that is the cause here).  But I'm going to go ahead and close this issue for now as I know that there are a lot of successful installs based on what I've heard from others.  So I do think it is something particular to your network/hardware/situation.  If we eventually determine that it is truly a problem with the firmware, I'll reopen this issue or start a new one.

Bjeff895, 2025-01-29:
Ok, thanks for the update.

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

Closed 2025-01-29.

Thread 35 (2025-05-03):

Left lateral sensor distance limited to 36"

Resinchem, 2025-05-03:
I noticed there is an inconsistency between the instructions in the web UI vs. actual behavior when setting the distance parms for lateral guidance.  The instructions say it's a maximum of 48 inches (which is perfect because I need 42 inches for my larger value).  But when I update settings, the result always max's out at 36 inches.

Not sure it's a big deal b/c I'm still calibrating my lateral guidance, but figured you appreciate knowing.

_Originally posted by @mluckolson in https://github.com/Resinchem/ESP-Parking-Assistant/discussions/34#discussioncomment-13026405_

Resinchem, 2025-05-03:
Confirmed.  The right lateral sensor distance can be set up to the specified max distance of 48" but setting the left distance to any value greater than 48", defaults back to a maximum of 36".

This will be fixed in the next firmware release.

Resinchem, 2025-05-05:
Resolved with Version 0.51

Closed 2025-05-05.

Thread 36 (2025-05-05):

Cannot set distances to millimeters in version 0.50

Resinchem, 2025-05-05:
When switching units from inches to millimeters and saving settings, the unit always switches back to inches.

_Originally posted by @jajen1977 in https://github.com/Resinchem/ESP-Parking-Assistant/discussions/34#discussioncomment-13025736_

Resinchem, 2025-05-05:
Resolved in Version 0.51.

Closed 2025-05-05.

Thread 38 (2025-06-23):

invalid header

tapiocateeh, 2025-06-23:
Installed 0.51 onto ESP32 mini ESP-WROOM-32 board, installation seems to be fine, went to boot, no published WiFi AP SSID, looked at logs, found

[19:12:53]invalid header: 0x6d74683c
[19:12:53]invalid header: 0x6d74683c
[19:12:53]invalid header: 0x6d74683c

attempted install again with new board, still same error.

Sorry, i'm still new to this ESP stuff, so if you have any other ideas, I am more than willing to try them! TIA!

Resinchem, 2025-06-23:
Yep... that's definitely a boot loop (RTC_RESET over and over).  This means that for whatever reason, you aren't getting a good flash.  This actually doesn't have anything to do with the firmware itself... as it isn't even getting to the point of running the firmware.

FYI... I originally compiled the firmware in the Arduino IDE using the 'ESP32 Dev Module' option.  My board also reports the chip as "ESP32-D0WD-V3 (revision 3)".  Just to verify, I'm using the following when flashing/creating the .bin:

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

You might try selecting the ESP32 Dev Module and assure all the board settings match the above.  Then first 'verify' the code in the IDE.  If it compiles without error, verify the proper COM port and try flashing/uploading again.  It is normal to see a handful of log messages after initial flash that look like errors (e.g. messages related to SPIFFS) but this is normal as the configuration file it is looking for doesn't exist until the controller is onboarded.  However, it should just be a few messages and then the log stops and waits (and the hotspot SSID should be broadcasting).  But if you see that 'RTC_RESET' message over and over again, that means the board is bootlooping and it cannot find/load the firmware.  Normally this is the result of either a bad flash or an incompatible board.

If you've tried all the above and still can't get a good flash, you may just have to order and try a different ESP32 from a different source.  Do note that the firmware has not been tested with all the variants of the ESP32 (e.g. "C series", "H series", "S series", etc.).  It's only been confirmed to work with the original ESP32 boards.  While it is unfortunate, there are a lot of cheap clones out there.  I've received batches of ESP32 boards where over half of them could not be flashed no matter what I tried.  It could be use of a substandard voltage regulator, issues with the USB-to-UART chip, etc.  It is entirely possible that you simply received a bad batch (or a batch that just won't flash this firmware properly).

I'm committed to continuing to help you until we get a working controller.  But it is probably going to take some trial and error on your part.  Do you happen to have any ESP8266 boards laying around?  Not that you want/need to use an ESP8266 for this project, but it might be interesting to see if you can flash the ESP8266 firmware to the ESP8266 successfully and get the hotspot to appear.  If you do, you don't need to actually onboard it.  Just seeing the 'ESP_ParkAssist' SSID lets you know the firmware was successfully installed and is running.  You can erase the board at this point and reuse it for another project.  Otherwise, you are probably going to have to order different ESP32 boards.  If possible (and no rush), could you post a photo of both the top and bottom of the ESP32 you are currently using?  I just want to see if I can notice anything different or unusual about it.

Resinchem, 2025-06-27:
Ok... that is progress!  The logs you are seeing is a failure to communicate with the VL53L0X side sensor.  Do you have the sensor connected to the ESP32?  Even though you are seeing those errors, can you access the web settings page at the IP address of the controller?  By default, the side sensor should be disabled (and I can see that from the config file dump in the log... which is good as it means the config file is getting created/read from flash).

But the I2C messages means that it is attempting to communicate with the sensor and isn't getting a response.  Also note that when you are on the onboarding page and you enter in your SSID, Password, Device name, etc., when you submit this page, the ESP32 will reboot and attempt to join WiFi (this is why the connection is lost).  Here's an oversimplified version of the onboarding/join WiFi process:

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

If it successfully joins the WiFi, then the ESP_ParkAssist hotspot will disappear and remain gone.  At this point, you need to rejoin the same WiFi with your phone or whatever device you used for onboarding.  Then you need to get the assigned IP address from your router and enter that in the browser of a device also on the same network.  Dropping the connection after onboarding is normal and expected.  However, if the ESP_ParkAssist hotspot reappears after a few minutes, then the board did not join WiFi and you'd have to try onboarding again.

It could be the particular board... or it could also easily be something that I missed in the firmware.  But it is definitely trying to communicate with the VL53L0X side sensor and not getting a response.  But it looks like everything else is OK.  See if you can pull up the web interface via the IP address of the controller and let me know the results.

Resinchem, 2025-06-28:
Fantastic!  Congrats on getting it working.  It is a bit interesting however.  I'm using a Wemos ESP32 Mini for both my production and development systems and firmware compiled for ESP32 Dev Module and they appear to operate without issue.  There must be something slightly different about your boards... or they've changed something with the current batches.

Regardless, it sounds like you now have a functioning system.  I'm going to go ahead and close this issue.  If you have other questions, please feel free to post in the discussion area of the repo and I'll do my best to address them.

Closed 2025-06-28.

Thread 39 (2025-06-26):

Side Sensor settings must be flipped when LED strip is wired on the right

Resinchem, 2025-06-26:
Currently, by default, the side sensor/lateral guidance settings make an assumption that the LED strip wiring/first LED is located on the left hand side of the strip:

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

If your installation has the LEDs wired on the right (as per the right image above), then it will be necessary to also 'flip' your side sensor settings in the web interface.  For example, if you have the side sensor physically installed on the right side of the parking zone:

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

If the LED strip is wired on the left, then the sensor position and distances work as expected.  However, if the LED strip is wired on the right, you have to flip the sensor position (set it to 'Left' even though it is physically on the right) and also flip the left/right distances.

I hope to fix this discrepancy in a future release but flipping the side sensor settings will allow the system to function normally until I can get the issue resolved.

Resinchem, 2025-07-13:
Issue resolved with release v0.52 which adds a new option to specify on which end the LEDs are wired:

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

When installed, the option defaults to 'left side' wiring.  If you previously applied the fix above (flipping the sensor location and distances), you can specify right-side wiring and then the side sensor settings will work as originally planned (e.g. you can 'flip' them back to the actual location/distances).  See the wiki section on [Understanding the Parking Zones](https://github.com/Resinchem/ESP-Parking-Assistant/wiki/04-Understanding-the-Parking-Zones) for more details.

Closed 2025-07-13.

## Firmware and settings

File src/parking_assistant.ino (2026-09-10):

/*
 * ESP32 Parking Assistant
 * Includes captive portal and OTA Updates
 * This provides code for an ESP32 controller and a WS2812b LED strip
 * Last Updated: September, 2026
 * ResinChem Tech - Released under GNU General Public License v3.0.  There is no guarantee or warranty, either expressed or implied, as to the
 * suitability or utilization of this project, or as to the condition of this project, or whether it will be suitable to the users purposes or needs.
 * Use is solely at the end user's risk.
 */
#pragma once

#include <Wire.h>
#include <LittleFS.h>
#include <TFMPlus.h>                    //https://github.com/budryerson/TFMini-Plus (v1.5.0)
#include <WiFiClient.h>                 //Arduino ESP Core - creates a client that can connect to an IP address
#include <PubSubClient.h>               //https://github.com/knolleary/pubsubclient  Provides MQTT functions (v2.8)
#include <ArduinoOTA.h>                 //https://github.com/jandrassy/ArduinoOTA (v1.1.0)
#include <ArduinoJson.h>                //https://github.com/bblanchon/ArduinoJson (v7.3.1)
#define FASTLED_INTERNAL                //Suppress FastLED SPI/bitbanged compiler warnings (only applies after first compile)
#include <FastLED.h>                    //https://github.com/FastLED/FastLED - LED functionality (v3.7.1)
#include <VL53L0X.h>                    //VL53L0X ToF Sensor https://github.com/pololu/vl53l0x-arduino (v1.3.1) - only available on ESP32
#include <math.h>
#include "html.h"                       //html code for the web pages
#include <WiFi.h>
#include <ESPmDNS.h>
#include <WebServer.h>
#include <DNSServer.h>                  //Captive portal DNS server (for auto-launching: only works on some devices/operating systems)
#include <Update.h>

#define VERSION "v0.61"
// =======================
//  GPIO PINS
// =======================
// These are just defaults.  If using different GPIO pins, you can set these via the embedded web app.
// It is not necessary to change any pins here.
#define LED_DATA_PIN 19                 // Pin connected to LED strip Data IN
#define TFMINI_RX_PIN 16                // To TF-Mini TX
#define TFMINI_TX_PIN 17                // To TF-Mini RX
#define TOF_DAT_PIN 21                  // To VL53L0X SDA PIN (data)
#define TOF_CLK_PIN 22                  // To VL53L0X SCL PIN (clock)
#define ONBOARD_LED 2                   // ESP32's onboard (blue) LED GPIO Pin
// ================================
//  System Feature Options
// ================================
#define APPNAME "Parking Assistant"
// Changing any of these requires a recompile and upload.  Normally changed for debugging purposes.
#define WIFIMODE 2                      // 0 = Only Soft Access Point, 1 = Only connect to local WiFi network with UN/PW, 2 = Both
#define MQTTMODE 1                      // 0 = Disable MQTT, 1 = Enable (will only be enabled if WiFi mode = 1 or 2 - broker must be on same network)
#define SERIAL_DEBUG 0                  // 0 = Disable (must be disabled if using ESP8266 RX/TX pins), 1 = enable
#define DNS_PORT 53                     // Standard DNS port of auto-launching captive portal or web app when running in AP Mode
#define NUM_LEDS_MAX 600                // For initialization - recommend actual max 50 LEDs if built as shown
#define MILLI_AMPS 5000;                // Default - will be defined during onboarding
#define FORMAT_LITTLEFS_IF_FAILED true  // DO NOT CHANGE!!!

//MQTT Handling - needed to handle in main loop and to avoid thread conflicts
#define MSK_LEDSTATE        0x00000001UL
#define MSK_LEDCOLOR        0x00000002UL
#define MSK_LEDBRIGHTNESS   0x00000004UL
#define MSK_CAR_PRESENCE    0x00000008UL
#define MSK_SIDE_DISTANCE   0x00000010UL
#define MSK_PARK_DISTANCE   0x00000020UL
#define MSK_ACTIVE_ZONE     0x00000040UL
#define MSK_SLEEP_BRIGHT    0x00000080UL
#define MSK_COLOR_STANDBY   0x00000100UL
#define MSK_COLOR_WAKE      0x00000200UL
#define MSK_COLOR_ACTIVE    0x00000400UL
#define MSK_COLOR_PARKED    0x00000800UL
#define MSK_COLOR_BACKUP    0x00001000UL
#define MSK_COLOR_MANUAL    0x00002000UL
#define MSK_DIST_WAKE       0x00004000UL
#define MSK_DIST_START      0x00008000UL
#define MSK_DIST_PARK       0x00010000UL
#define MSK_DIST_BACKUP     0x00020000UL
#define MSK_SIDE_DIST_LEFT  0x00040000UL
#define MSK_SIDE_DIST_RIGHT 0x00080000UL
#define MSK_SENSOR_OVERRIDE 0x00100000UL
#define MSK_LED_EFFECT      0x00200000UL
#define MSK_LIGHT_JSON      0x00400000UL
// ========================
//  Config variables
// ========================
// These variables are stored in the saved configuration.  
// Most have a 'default' and 'active' version and can be changed via web app without updating saved defaults
// Those with only a single version (non _dflt) can only be updated with a Save & Reboot
String deviceName = "parkasst";    //This value will be set during onboarding and cannot be changed via web app
// --------------------
//  GPIO Pin Variables
// --------------------
//These are initially assigned defaults, but will be updated by config file when read
//Single Vars
byte ledData_Pin = LED_DATA_PIN;
byte tfminiRX_Pin = TFMINI_RX_PIN;
byte tfminiTX_Pin = TFMINI_TX_PIN;
byte tofDat_Pin = TOF_DAT_PIN;
byte tofClk_Pin = TOF_CLK_PIN;
byte onboardLED_Pin = ONBOARD_LED;

// --------------------------
//  LEDs, Effects and Colors
// --------------------------
//Single vars
int milliamps = MILLI_AMPS;   //does not have 'active'
CRGB ledColorOff = CRGB::Black;
bool rightLEDWiring = false;
int numLEDs = 30;

//Vars with Saved defaults 
byte defaultBrightness = 100;
byte sleepBrightness_dflt = 5;

CRGB ledColorStandby_dflt = CRGB::Blue;
CRGB ledColorWake_dflt = CRGB::Lime;
CRGB ledColorActive_dflt = CRGB::Yellow;
CRGB ledColorParked_dflt = CRGB::Red;
CRGB ledColorBackup_dflt = CRGB::Red;

String ledEffect_dflt = "Out-In";

//Active vars
byte activeBrightness = 100;
byte lastBrightness = 64;                // Holding varible to return to prior state when LEDs have been off.
byte sleepBrightness = 5;

CRGB ledColorStandby = CRGB::Blue;
CRGB ledColorWake = CRGB::Green;
CRGB ledColorActive = CRGB::Yellow;
CRGB ledColorParked = CRGB::Red;
CRGB ledColorBackup = CRGB::Red;

String ledEffect_m1 = "Out-In";

// -----------------------
//  Sensors and Distances
// -----------------------
//Single vars
byte uomDistance = 1;              // 0=inches, 1=millimeters (no active var)
bool useSideSensor = false;
byte sideSensorPos = 0;            // 0=unused, 1=right side, 2=left side
byte nocarDetectedCounterMax = 10; //noCarDebounce (valid values 0 - 25) (no active var)
uint32_t maxOperationTimePark = 60;
uint32_t maxOperationTimeExit = 5;
//Vars with saved defaults
int wakeDistance_dflt = 3048;
int startDistance_dflt = 1829;   // Start countdown distance (~6')
int parkDistance_dflt = 610;     // Final parked distacce (~2')
int backupDistance_dflt = 457;   // Flash backup distance (~18")

int leftDistance_dflt = 610;     // 610 = ~24 in
int rightDistance_dflt = 508;    // 508 = ~20 in

//Active Vars
int wakeDistance = 3048;    // wake/sleep distance (~10ft)
int startDistance = 1829;   // Start countdown distance (~6')
int parkDistance = 610;     // Final parked distacce (~2')
int backupDistance = 457;   // Flash backup distance (~18")

int leftDistance = 610;     // 610 = ~24 in
int rightDistance = 508;    // 508 = ~20 in

//-------------------------
// MQTT - Only single vars (no dflt/active)
//-------------------------
//  MQTT will only be used if a server address other than '0.0.0.0' is entered via portal
byte mqttAddr_1 = 0;
byte mqttAddr_2 = 0;
byte mqttAddr_3 = 0;
byte mqttAddr_4 = 0;
int mqttPort = 0;

String mqttUser = "myusername";
String mqttPW = "mypassword";
uint16_t mqttTelePeriod = 60;
String mqttTopicSub ="parkasst";  
String mqttTopicPub = "parkasst"; 

//======== END CONFIG VARS ==========

// ===============================
//  Effects and Color arrays 
// ===============================
//  Effects are defined in defineEffects() - called in Setup
//  Effects must be handled in the lights on call
//  To add an effect:
//    - Increase array below (if adding)
//    - Add element and add name in defineEffects()
//    - Update if statement in main loop
//    - Add update function to implement effect (called by main loop)
int numberOfEffects = 5;
String Effects[5]; 

//===============================
// WiFi and Onboarding Variables
//===============================
//WiFi Info
String wifiHostName = deviceName;
String otaHostName = deviceName + "_OTA";
String wifiSSID = "";
String wifiPW = "";

bool onboarding = false;        //Will be set to true if no config file found or wifi cannot be joined
bool onboardConnecting = false;
bool triggerWiFiBegin = false;
unsigned long onboardStartMilli = 0;
unsigned long onboardSuccessMilli = 0;
bool onboardRebootReady = false;
unsigned long onboardRebootMilli = 0;
bool wifiConnected = false;
//Vars for using AP Mode Only
bool noWiFiMode = false;
String manualAPName = deviceName + "_Hotspot";
String manualAPPwd = "";

//=================
//  MQTT Variables
//=================

String mqttClient = "parkasst";
uint32_t mqttLastUpdate = 0;
bool mqttEnabled = false;              //Will be enabled/disabled depending on whether a valid IP address is defined in Settings (0.0.0.0 disables MQTT)
bool mqttConnected = false;            //Will be enabled if defined and successful connnection made.  This var should be checked upon any MQTT action.
bool prevCarStatus = false;            //For forcing MQTT update on state change
bool forceMQTTUpdate = false;          //Force MQTT update on state change
bool initialSyncRequired = false;      //Flag for initial publish of MQTT data after boot
const int MQTT_RETRY_DELAY = 5000;     //Delay (ms) between reconnect attempts
uint32_t lastMqttRetryAttempt = 0;     //Non-blocking handler for MQTT reconnection
int syncStep = 0;
unsigned long lastSyncStepTime = 0;
volatile uint32_t mqttUpdateMask = 0;  //Volatile so it can be updated by out-of-thread background tasks
const int INIT_SYNC_INTERVAL = 100;   
bool isMqttJsonProcessing = false;     //Needed to handle special light JSON payload from Home Assistant (Discovery)

//Vars for Discovery
byte macAddr[6];               //Device MAC address (array is in reverse order)
String strMacAddr;             //MAC address as string and in proper order
char uidPrefix[] = "prkast";   //Prefix for unique ID generation
char devUniqueID[30];          //Generated Unique ID for this device (uidPrefix + last 6 MAC characters)

struct DiscoverySettings {     //Structure for HA MQTT Discovery 
  bool exists = false;
  String deviceName = "";
  bool controls = true;
  bool sensors = true;
  bool config = true;
  bool diagnostics = true;
};
DiscoverySettings currentDiscovery;

// ========================
// Arduino IDE OTA Updates
// ========================
// You should not change any of these
bool ota_flag = true;                       // Must leave this as true for board to broadcast port to IDE upon boot
uint16_t ota_boot_time_window = 2500;       // minimum time on boot for IP address to show in IDE ports, in millisecs
uint16_t ota_time_window = 20000;           // time to start file upload when ota_flag set to true (after initial boot), in millsecs
uint16_t ota_time_elapsed = 0;              // Counter when OTA active
uint16_t ota_time = ota_boot_time_window;
uint8_t web_otaDone = 0;                    // Web OTA Firmware Update

//=============================
// Web app tesing and hold vars
//=============================
String whichData = "all";
//Main Page
String mainPageMode = "";
bool mainTestColorFlag = false;
bool mainTestDistFlag = false;
String mainPageColorMsg = "";
String mainPageDistMsg = "";


// ========================
// OTHER GLOBAL VARIABLES
// ========================
bool isBooting = false;
bool overrideSensors = false;   //Used by MQTT/API to override sensors for manual LED control
bool mainTestFlag = false;
bool tfMiniEnabled = false;
bool blinkOn = false;
bool blinkSideOn = false;
int intervalDistance = 0;
bool carDetected = false;
bool isAwake = false;
bool coldStart = true;
bool showStandbyLEDs = true;
bool useOnboardLED = true;
bool useBootLightsLED = true;

bool ledState = false;
CRGB ledColorManual = CRGB::White;
CRGB activeLEDColor = CRGB::White;

//Sensor measurements
int16_t tf_dist = 0;
int16_t vl_side_dist = 0;
String mqttZone = "Vacant";

byte carDetectedCounter = 0;
byte carDetectedCounterMax = 3;
byte nocarDetectedCounter = 0;
byte outOfRangeCounter = 0;
uint32_t startTime;
bool exitSleepTimerStarted = false;
bool parkSleepTimerStarted = false;

String baseIP;

//===========================
// Instantiate objects
//===========================
WiFiClient espClient;
WebServer server(80);
TwoWire bus1 = TwoWire(0);
VL53L0X side_sensor;
DNSServer dnsServer;

#if defined(MQTTMODE) && (MQTTMODE == 1 && (WIFIMODE == 1 || WIFIMODE == 2))
  PubSubClient client(espClient);
#endif

TFMPlus tfmini;
CRGB LEDs[NUM_LEDS_MAX];  

// ==============================
//  Function Prototypes/Declares
// ==============================
//Config Files
void readConfigFile();
void writeConfigFile(bool restart_ESP);
String getCurrentConfig();
bool saveDiscoveryConfig();
void deleteDiscoveryConfig();
String getDiscoveryConfig();
//WiFi and MQTT Setup
void setupSoftAP();
bool setupWifi();
bool setupManualAP();
bool setup_mqtt();
void reconnect();
bool reconnect_soft();
bool mqttIsConnected();
//LED and Display Functions
void defineEffects();
void allLEDsOff(bool resumeSleep = false);
void blinkLEDs(CRGB color);
void blinkSideLEDs(CRGB color, byte pos);
void updateOutIn(int curDistance);
void updateInOut(int curDistance);
void updateFullStrip(int curDistance);
void updateFullStripInv(int curDistance);
void updateSolid(int curDistance);
void updateSleepMode();
void updateOTA();
//Calcs, Conversions and Misc
int calculateInterval();
float mmToInches(int mmDistance);
int inchesToMm(float inchDistance);
//MQTT and API Processors
void callback(char* topic, byte* payload, unsigned int length);
void handleAPI();
bool processCommand(String key, String val);
void updateMQTT(String whichField);
void handleQueuedMqttUpdates();
void executeMqttUpdate(String whichField);
void handleInitMqttSync();
void handleLiveMqttUpdates();
void publishLightJsonState();
void forceMqttRefresh();
void setLEDState(bool state, CRGB color = activeLEDColor);
void overrideAllSensors(bool sensorsOff);
String getEffectName(String effect);
//Web Pages and Handlers
void setupWebHandlers();
void handleRoot();
void handleOnboard();
void handleOnboardStatus();
void runOnboardingProcesses();
void handleMainPage();
void webMainPageJson();
void webSystemPage();
void webSystemPageJson();
void handleSystem();
void webCalibratePage();
void getCalibrationData();
void webIntegratePage();
void webIntegratePageJson();
void handleIntegrations();
void handleDiscoverySave();
void publishDiscovery(bool add);
void publishVersionUpdate();
void webRestartPage();
void webFirmwareUpdate();
void handleWebUpdate();
void handleWebUpdateEnd();
void handleOTAUpdate();
void handleOTAUpdateMqtt();
void webConfigDump();
void handleInfoDump();
void infoDumpJson();
void webResetPage();
void handleNotFound();
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
void loop() {
  //Process DNS queries if running in AP mode
  if (noWiFiMode || onboarding) {
    dnsServer.processNextRequest();
  }  
  //Handle OTA updates when OTA flag set via HTML call to http://ip_address/otaupdate
  if (ota_flag && !noWiFiMode) {
    updateOTA();  //Show update on LED strip
    uint32_t ota_time_start = millis();
    while (ota_time_elapsed < ota_time) {
      ArduinoOTA.handle();  
      ota_time_elapsed = millis()-ota_time_start;   
      delay(10); 
    }
    ota_flag = false;
    updateSleepMode();
  }
  //Handle any web calls
  server.handleClient();
  if (onboarding) {
    runOnboardingProcesses();
  } else {
    if ((!overrideSensors) && (!mainTestFlag)) {
      //regular code logic here
      if (mqttEnabled && (WIFIMODE > 0 && WiFi.status() == WL_CONNECTED)) {
        mqttConnected = client.connected();
      }
      uint32_t currentMillis = millis();
      int16_t distance = 0;
      //Attempt to get reading from TFMini
      if (tfMiniEnabled) {
        if (tfmini.getData(distance)) {
          tf_dist = distance * 10;
        } else {
          tf_dist = 8888;  //Default value if reading unsuccessful
        }
      } else {
        tf_dist = 9999;  //Default value if TFMini not enabled (serial connection failed)
      }

      if ((useSideSensor) && (sideSensorPos > 0) && (leftDistance > 0) && (rightDistance > 0)) {
        vl_side_dist = side_sensor.readRangeContinuousMillimeters();
      } else {
        vl_side_dist = 0;
      }

      //Determine if car (or other object) present in any zones
      if (tf_dist <= wakeDistance) {
        if (!carDetected) {
          carDetectedCounter ++;
        }
        if (carDetectedCounter > carDetectedCounterMax) {  //eliminate trigger on noise
          carDetectedCounter = 0;
          nocarDetectedCounter = 0;
          carDetected = true;
          if (coldStart) {
            coldStart = false;
            exitSleepTimerStarted = true;
            parkSleepTimerStarted = false;
          } else {
            exitSleepTimerStarted = false;
            parkSleepTimerStarted = true;
          }
          startTime = currentMillis;
          FastLED.setBrightness(activeBrightness);
          isAwake = true;
          ledState = true;
        }
      } else {
        nocarDetectedCounter ++;
        if (nocarDetectedCounter > nocarDetectedCounterMax) {  //eliminate trigger on noise
          if (!exitSleepTimerStarted) {
            if ((carDetected) || (coldStart)) {
              exitSleepTimerStarted = true;
              coldStart = false;
              startTime = currentMillis;
            }
          }
          carDetected = false;
          carDetectedCounter = 0;
          nocarDetectedCounter = 0;
          mqttZone = "Vacant";
        }
      }

      //Update LEDs
      if ((carDetected) && (isAwake)) {
        if (tf_dist <= backupDistance) {
          //Beyond minimum distance - flash backup!
          blinkLEDs(ledColorBackup);
          mqttZone = "Backup";
          activeLEDColor = ledColorBackup;
        } else if (tf_dist <= parkDistance) {  
          //In desired parked distance
          fill_solid(LEDs, numLEDs, ledColorParked);
          mqttZone = "Parked";
          activeLEDColor = ledColorParked;
        } else if ((tf_dist > startDistance) && (tf_dist <= wakeDistance)) {
          //Beyond start distance but within wake distance
          fill_solid(LEDs, numLEDs, ledColorWake);
          mqttZone = "Wake";
          activeLEDColor = ledColorWake;
        } else if ((tf_dist <= startDistance) && (tf_dist > parkDistance)) {
          //Update based on selected effect
          if (ledEffect_m1 == "Out-In") updateOutIn(tf_dist);
          else if (ledEffect_m1 == "In-Out") updateInOut(tf_dist);
          else if (ledEffect_m1 == "Full-Strip") updateFullStrip(tf_dist);
          else if (ledEffect_m1 == "Full-Strip-Inv") updateFullStripInv(tf_dist);
          else if (ledEffect_m1 == "Solid") updateSolid(tf_dist);
          
          mqttZone = "Active";
          activeLEDColor = ledColorActive;
          //Check side sensor
          if (useSideSensor && (vl_side_dist > 0) && (vl_side_dist < 1300)) {
            // --- LEFT SIDE MOUNT (sideSensorPos == 2) ---
            if (sideSensorPos == 2) {
              if (vl_side_dist < leftDistance) blinkSideLEDs(ledColorBackup, 2); // Too far LEFT: Flash LEFT LEDs
              else if (vl_side_dist > rightDistance) blinkSideLEDs(ledColorBackup, 1); // Too far RIGHT: Flash RIGHT LEDs
            // --- RIGHT SIDE MOUNT (sideSensorPos == 1) ---
            } else if (sideSensorPos == 1) {
              if (vl_side_dist < rightDistance) blinkSideLEDs(ledColorBackup, 1); // Too far RIGHT: Flash RIGHT LEDs
              else if (vl_side_dist > leftDistance) blinkSideLEDs(ledColorBackup, 2); // Too far LEFT: Flash LEFT LEDs
            }
          }
        }
      }
      //Put system to sleep if parking or exit time elapsed 
      uint32_t elapsedTime = currentMillis - startTime;
      if (((elapsedTime > (maxOperationTimePark * 1000)) && (parkSleepTimerStarted)) || ((elapsedTime > (maxOperationTimeExit * 1000)) && (exitSleepTimerStarted  ))) {
        updateSleepMode();
        forceMQTTUpdate = true;
        isAwake = false;
        startTime = currentMillis;
        exitSleepTimerStarted = false;
        parkSleepTimerStarted = false;
      }
      //Show/Refresh LED Strip
      FastLED.show();
    }

    // ===================
    // MQTT STATE UPDATES
    // ===================
    if ((!mainTestFlag) && (!noWiFiMode)) {
      // Don't update MQTT when in test mode or if sensors are overridden
      // If MQTT enabled, check connection (Non-Blocking) and reestablish if needed.
      if (mqttEnabled && (WIFIMODE > 0 && WiFi.status() == WL_CONNECTED)) {
        if (!mqttConnected) { 
          // Calls non-blocking reconnect_soft
          reconnect_soft(); 
        } else {
          client.loop(); 
        }
      }
      //Handle any required MQTT state publishes (thread-safe)
      if ((mqttConnected) && (!isBooting)) {
        handleLiveMqttUpdates();
        unsigned long curMillis = millis();
        if (curMillis - lastSyncStepTime > INIT_SYNC_INTERVAL) {
          if (initialSyncRequired) {
            handleInitMqttSync(); 
          }
          handleQueuedMqttUpdates(); 
          lastSyncStepTime = curMillis;
        }
      }
    }
    delay(150);
  }
}
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

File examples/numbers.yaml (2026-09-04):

# Create these entries under your existing MQTT integration header,
# whether that is in your primary configuration.yaml, a split yaml file
# or in the MQTT section of a package.
# 
# Replace the "parkasst" section in the state topics with whatever topic
# you specified in the MQTT setup portion of the Parking Assistant settings 
# if different than the default.
#
# You can also change the name to anything desired and add any other standard
# attributes like friendly name, icon, etc.
#
# For distance entities, values can be in inches or millimeters depending upon
# the Parking Assistant unit settings.  

mqtt:
  number:
    - name: "Brightness Standby"
      state_topic: "stat/parkasst/brightnessleep"
      command_topic: "cmnd/parkasst/brightnessleep"
      min: 0
      max: 255
      step: 1
      mode: "slider"

    - name: "Dist1 Wake"
      state_topic: "stat/parkasst/distwake"
      command_topic: "cmnd/parkasst/distwake"
      min: 12    #305  (mm)
      max: 192   #4990 (mm)
      step: 1
      mode: "box"
      unit_of_measurement: "in"  #"mm"

    - name: "Dist2 Active"
      state_topic: "stat/parkasst/diststart"
      command_topic: "cmnd/parkasst/diststart"
      min: 12    #305  (mm)
      max: 192   #4990 (mm)
      step: 1
      mode: "box"
      unit_of_measurement: "in"  #"mm"

    - name: "Dist3 Park"
      state_topic: "stat/parkasst/distpark"
      command_topic: "cmnd/parkasst/distpark"
      min: 12    #305  (mm)
      max: 192   #4990 (mm)
      step: 1
      mode: "box"
      unit_of_measurement: "in"  #"mm"

    - name: "Dist4 Backup"
      state_topic: "stat/parkasst/distbackup"
      command_topic: "cmnd/parkasst/distbackup"
      min: 12    #305  (mm)
      max: 192   #4990 (mm)
      step: 1
      mode: "box"
      unit_of_measurement: "in"  #"mm"

    - name: "Side Dist Left"
      state_topic: "stat/parkasst/sidedistleft"
      command_topic: "cmnd/parkasst/sidedistleft"
      min: 2      #50   (mm) 
      max: 48     #1220 (mm) 
      step: 1
      mode: "box"
      unit_of_measurement: "in"  #"mm"

    - name: "Side Dist Right"
      state_topic: "stat/parkasst/sidedistright"
      command_topic: "cmnd/parkasst/sidedistright"
      min: 2      #50   (mm) 
      max: 48     #1220 (mm) 
      step: 1
      mode: "box"
      unit_of_measurement: "in"  #"mm"

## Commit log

2022-11-13 Fix for standby brightness
    [parking_assistant.ino]
2022-11-17 File adds
    [ElectroCookie Enclosure V3 w Tabs.stl, ElectroCookie Lid.stl]
2022-11-28 Fix for version number
    [parking_assistant.ino]
2025-04-05 v0.50 Updates
    [ElectroCookie Enclosure Tall.stl, VL53L0X Case.stl]
2026-09-04 v0.60 update
    [Controller Enclosure Basic.stl, Controller Enclosure with Mount Tabs.stl, ElectroCookie Enclosure V3 w Tabs.stl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]
